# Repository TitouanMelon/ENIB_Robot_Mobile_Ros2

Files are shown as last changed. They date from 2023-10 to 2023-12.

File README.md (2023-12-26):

# Mobile robot with ROS2

Project to make a moving robot with communication with ROS2 and sensors
His little name is : Humble

## Project member
- Titouan Melon : https://www.linkedin.com/in/titouan-melon
- Louanne Floch : https://www.linkedin.com/in/louanne-floch
- Jérémy Plantec : https://www.linkedin.com/in/j%C3%A9r%C3%A9my-plantec-7a24a81bb
- Donald TOGNIA DJANKO DIALLO : https://www.linkedin.com/in/tognia-djanko-diallo-donald-b38281228

## Extern links
- Google drive :https://drive.google.com/drive/folders/1ekVw0Pp5evgDc79cSzruJdU0V-NTOiN-?usp=sharing
- Documentation of the mechanical part : https://www.enib.fr/~kerhoas/robot_ros_architecture.html
- Documentation of the STM32 workspace : https://nasmelon.ddns.net/robotRos/doc/index.html
- Visualization of the 3D model : https://nasmelon.ddns.net/robotRos/3d/index.html
- Virtual machine with all software and startup workspace :
 - rapid speed link : https://drive.google.com/file/d/1msf677nJeT9T99g9dxZXXRz8_1ijEkyR/view?usp=sharing
 - low speed link : https://nasmelon.ddns.net/robotRos/Ubuntu22.04.ova

## Schema
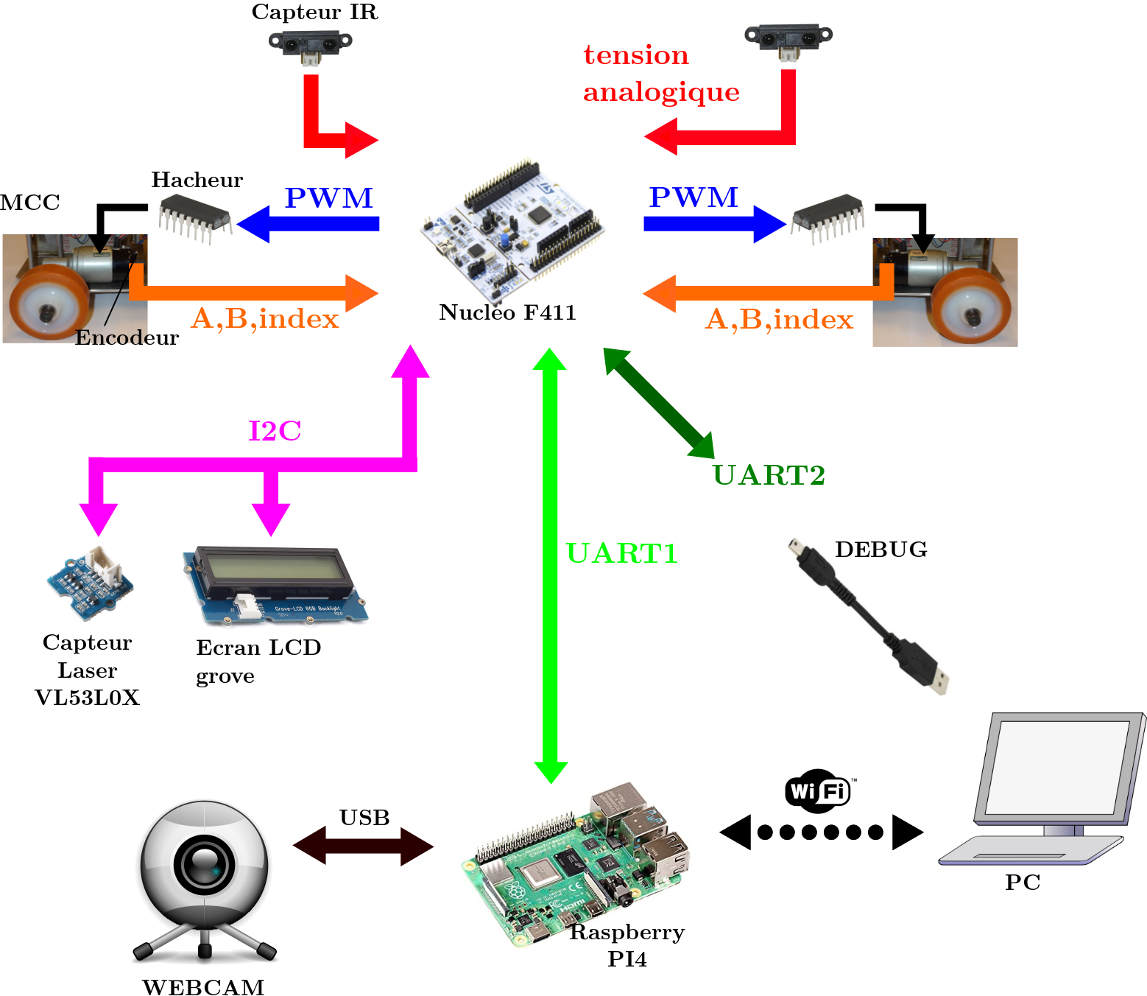
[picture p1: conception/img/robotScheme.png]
robot sheme


## Folder description

```
\---finalCode
|	\---Camera : camera's program 
|	\---IHM : qt ihm
|	\---WORKSPACE_F411_uROS6 : stm32 workspace
\---startupCode : contain the startup workspace
\---conception
|   \---3D_models
|   \---img : img to readme
|   \---installation scripts
|   \---schematique : eagle
\---docs
|   \---externe : extern pdf 
|   \---html : documentation in web format
|   \---latex : documentation in pdf format
\---report : report for ERI
```

## Summary
1. [Software installation](./README.md#Software-installation-procedure)
2. [Get startup workspace](./README.md#Get-startup-workspace)
3. [Get final workspace](./README.md#Get-final-workspace)
4. [Launch procedure](./README.md#Launch-procedure)
5. [Modify the code](./README.md#modify-code)
6. [Other information](./README.md#Other-information)

# Software installation procedure
## Install OS

### On a PC
Install <a href="https://ubuntu.com/download/desktop" >Ubuntu 22.04.3 LTS</a> on a pc
### On a RPI
Install <a href="https://www.raspberrypi.com/software/">RPI imager</a> and with this install Ubuntu like this

CHOOSE OS -> Other general-purpose OS -> Ubuntu -> Ubuntu Desktop 22.04.03 LTS (64bits)

## Install all in one script
>[!NOTE]
>this section is recommended for a pc but it is possible to apply it to the raspberry PI
>You need 8Go of free space

You can install all necessary tools with this following commands.

```
sudo apt install wget -y
wget https://raw.githubusercontent.com/TitouanMelon/ENIB_Robot_Mobile_Ros2/main/conception/installation%20scripts/ROS.sh
wget STM32cubeIDE.sh
sed -i 's/\r$//' ./ROS.sh && chmod +x ./ROS.sh && ./ROS.sh
```

## For PC and RaspberryPi
### Install ROS2
ROS2 installation is the same on PC and on RPI

```
sudo apt install wget -y
wget https://raw.githubusercontent.com/TitouanMelon/ENIB_Robot_Mobile_Ros2/main/conception/installation%20scripts/ROS_Install.sh
sed -i 's/\r$//' ./ROS_Install.sh && chmod +x ./ROS_Install.sh && ./ROS_Install.sh
```

### Install MicroRos

>[!WARNING]
>Be carreful the installation of microRos require a minimum of 1GB of RAM to succes

>[!NOTE]
>In order to install on a RPI4 with 2GB of RAM you can remove gdm3 install the script with the console and reinstall gdm3

```
sudo apt install wget -y
wget https://raw.githubusercontent.com/TitouanMelon/ENIB_Robot_Mobile_Ros2/main/conception/installation%20scripts/MicroROS_Install.sh
sed -i 's/\r$//' ./MicroROS_Install.sh && chmod +x ./MicroROS_Install.sh && ./MicroROS_Install.sh
```

### Copy scripts on pc
```
cd ~
sudo apt install wget -y
wget https://raw.githubusercontent.com/TitouanMelon/ENIB_Robot_Mobile_Ros2/main/conception/installation%20scripts/STM32.sh
wget https://raw.githubusercontent.com/TitouanMelon/ENIB_Robot_Mobile_Ros2/main/conception/installation%20scripts/SET_ROS_DOMAIN_ID.sh
sed -i 's/\r$//' ./STM32.sh && chmod +x ./STM32.sh
sed -i 's/\r$//' ./SET_ROS_DOMAIN_ID.sh && chmod +x ./SET_ROS_DOMAIN_ID.sh
echo "ROS_DOMAIN_ID=0" | sudo tee -a /etc/environment
sudo ln -s ./STM32.sh /usr/bin/stm32_ros_agent 
sudo ln -s ./SET_ROS_DOMAIN_ID.sh /usr/bin/set_ros_id
```

## For Pc only
>[!NOTE]
>this section is recommended for a pc but it is possible to apply it to the raspberry PI

### STM32CubeIde

Get <a href="https://www.st.com/en/development-tools/stm32cubeide.html">STM32CubeIde</a> and install it 

#### Install

Go to the **Get Software** level and select the latest version of your OS

Next accept the EULA and fil the form with the name of your choice but a valid email address on the next prompt

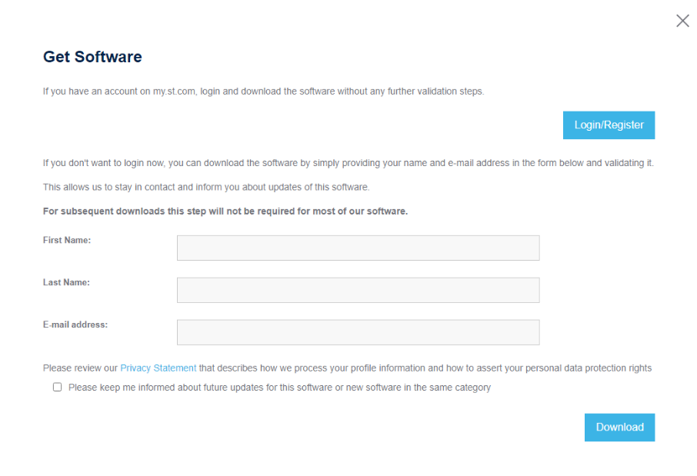
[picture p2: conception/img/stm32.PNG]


You will receive an email with the download link

After download just launch the executable and follow the instructions

#### Install gtkterm
```
sudo apt install gtkterm -y
```

### QT creator and QT creator ros
you need to install the qtcreator and qtcreator-ros software

```
sudo apt install qtcreator -y
sudo snap install qtcreator-ros --classic
```

# Get startup workspace
>[!NOTE]
>Be carreful if a directory have the same name the commands can erase the folder

Go to your project directory and run the command below
## Get the STM32 workspace
```
sudo apt install wget unzip -y
wget https://github.com/TitouanMelon/ENIB_Robot_Mobile_Ros2/raw/main/startupCode/WORKSPACE_F411_uROS.zip
unzip WORKSPACE_F411_uROS.zip
```

## Get the qt workspace
```
sudo apt install wget unzip -y
wget https://github.com/TitouanMelon/ENIB_Robot_Mobile_Ros2/raw/main/startupCode/IHM.zip
unzip IHM.zip
```

## Get the camera workspace
>[!NOTE]
>You need to have ROS2 install to follow this tutorial (see [here](./README.md#install-ros2) to install)

For the camera we can't give a startup folder because there are some configuration to do if they want modify the code like add more file
so is easier to follow this links to do the workspace by yourself:

- Tutorial ROS2 humble : https://docs.ros.org/en/humble/Tutorials/Beginner-Client-Libraries/Writing-A-Simple-Py-Publisher-And-Subscriber.html
- Github of the tutorial exemples : https://github.com/ros2/examples/tree/rolling/rclpy

# Get final workspace
```
sudo apt install git -y
git clone https://github.com/TitouanMelon/ENIB_Robot_Mobile_Ros2.git
mkdir -p ~/robot
mv -r ./ENIB_Robot_Mobile_Ros2/finalCode/* ~/robot/
#uncomment to remove git directory
#rm -r ./ENIB_Robot_Mobile_Ros2

```

# Launch procedure
>[!NOTE]
>The command below is make for our final solution so you maybe need to adjust some command to execute your solution

1. Build and run IHM
Open a terminal in the IHM directory and run this command

```
colcon build
source install/setup.bash
./build/robot_mobile_pkg_cpp/my_node_ihm
# if you change the name of project change this line like this ./build/<node_name>/<executable_name>
```

2. Compile, build and run the camera program
```
colcon build --packages-select py_pubsub
source install/setup.bash
ros2 run py_pubsub camera
# if you change the name of project change the line like this ros2 run <package_name> <entry_point>
```

3. Start the STM32.sh or stm32_ros_agent
```
stm32_ros_agent
# or launch STM32.sh from the terminal
```
4. Flash the stm32 and run the code
>[!NOTE]
>If you have the multiple pattern error clean and rebuild the project until the error dissipear

# modify code
## Open stm32 project
>[!NOTE]
>you need STM32CubeIde to follow this tutorial (see [here](./README.md#STM32CubeIde) to install)

- Open stm32cubeIde and select the workspace and select ok

## Open IHM
>[!NOTE]
>you need qtcreator and qtcreator-ros to follow this tutorial (see [here](./README.md#qt-creator-and-qt-creator-ros) to install)

- Open qtcreator-ros
- go to File -> Open project or file

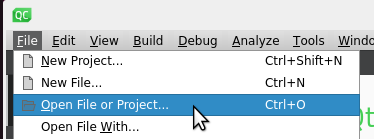
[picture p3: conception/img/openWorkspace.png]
openproject

- Open the file 'workspace.user'
- Then close and repeat to make qtcreator-ros load the project files

## Open camera code
1. Code directly on the RPI
2. Use Visual Studio to connect to in ssh to your raspberryPi and have access to his folder 

# Other information
## Documentation of the stm32 final workspace
You can found the documentation of the STM32 project [here](./docs)

## Config camera
```
sudo apt install v412-ctl
v4l2-ctl -d /dev/video0 --all
```

## Get information about ROS2 node and topic 
- You can use rqt to see information about ROS2. It's a visual ihm to see topics and data
- Information about all topic
```
ros2 topic list
```

- Information about a node
```
ros2 node info /nom/du/node
```

## Send and receive data on ros topic
You can see message_type and data on this link : https://docs.ros.org/en/melodic/api/std_msgs/html/index-msg.html

- Publish data once on a topic
```
ros2 topic --once <topic/name> <message_type> <data>
```
- Publish N data per seconds on a topic 
```
ros2 topic -r N <topic/name> <message_type> <data>
```
- exemple of publishing an array of 3 Int8 on the topic camera/hsv_low once ([data format](https://docs.ros.org/en/melodic/api/std_msgs/html/msg/Int8MultiArray.html))
```
ros2 topic pub --once camera/hsv_low std_msgs/msg/Int8MultiArray "{data : [99,91,30]}"
```

- Listen a topic
```
ros2 topic echo <topic/name>
```

## Redirect printf on UART2

Right-click on the syscalls.c file and select Properties. Under C/C++ Build>Settings, check Exclude ressource from build

Then click on Apply and close
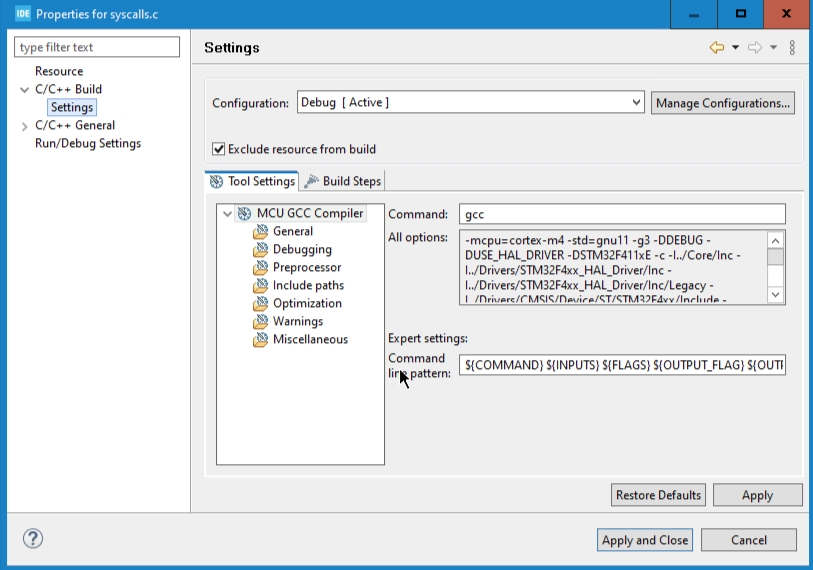
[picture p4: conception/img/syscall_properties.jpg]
syscall.c properties


Next create two files :
- retarget.h copy/paste code from [retarget.h](./conception/retarget/retarget.h) and save
- retarget.c and copy/paste code from [retarget.c](./conception/retarget/retarget.c) and save

After you need to include stdio.h and retarget.h in your main file and call 
```
RetargetInit(&huart2);
```

to indicate you want printf and scanf function on UART2

## 3D models
see 3D models information [here](./conception/3D_models/)

## Pinout

more information [here](./docs/externe/base_robot.pdf)

| Pin STM32 | Function | Use |
|--- | --- | --- |
|PA8 | PWM1/1 | Encodeur Voie A |
|PA9 | PWM1/2 | Encodeur Voie B |
|PB10 | EXTI1 | Index encodeur  |
|PA0 | PWM2/1 | Encodeur Voie A |
|PA1 | PWM2/2 | Encodeur Voie B |
|PC0 | EXTI | Index Moteur |
|PA6 | PWM3/1 | PWM motor 1 |
|PC7 | PWM3/2 | PWM motor 2 |
|PB3 | ENABLE MOTEUR | actif état Bas  |
|PA4 | ADC1_8 | Sensor IR 1 |
|PB0 | ADC1_4 | Sensor IR 2 |

## Robot cablage
### USART2
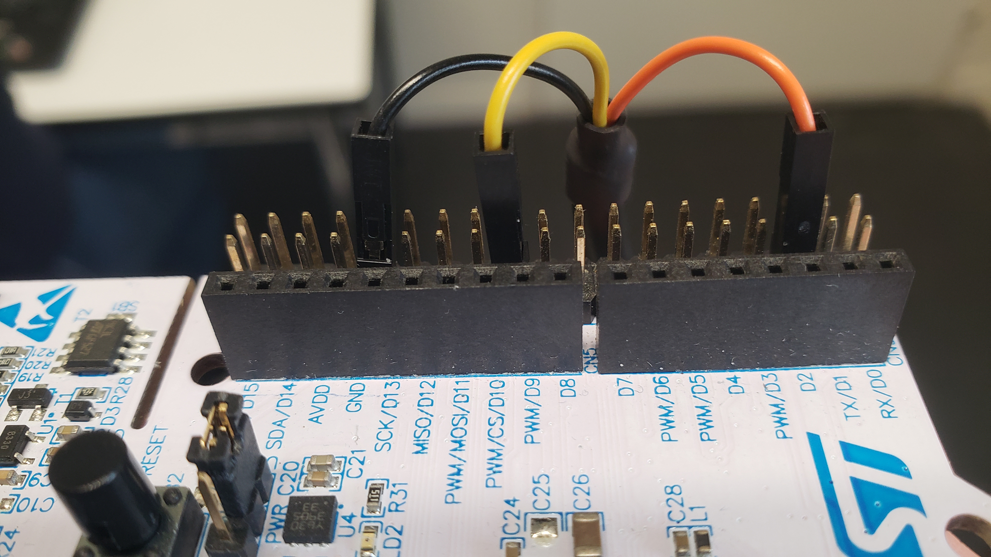
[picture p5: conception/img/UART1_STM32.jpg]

###Motor, Sensors and rpi
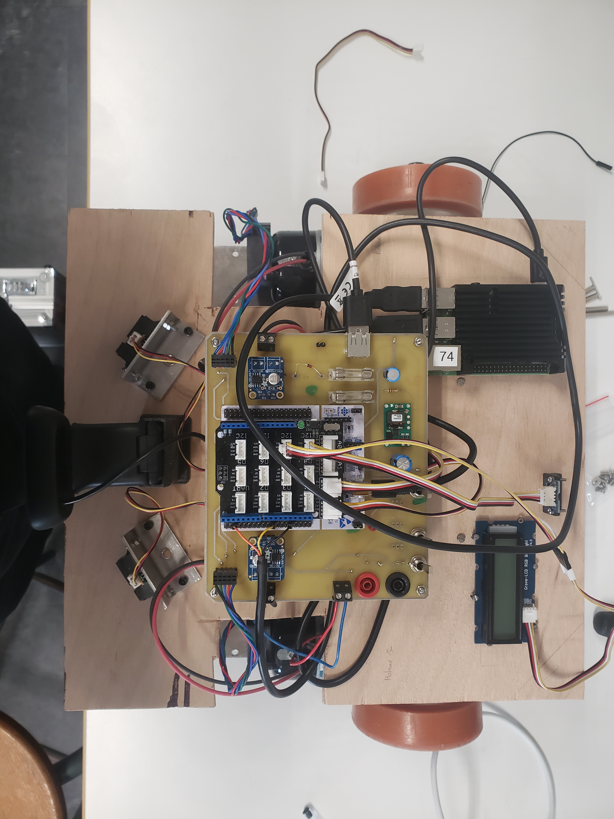
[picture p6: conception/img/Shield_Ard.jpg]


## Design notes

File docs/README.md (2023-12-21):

# Get the web documentation
1. Download the html zip, extract them and launch index.html
2. Go to https://nasmelon.ddns.net/robotRos/doc/index.html

# Get the pdf documentation
1. Download the stm32_doc.pdf

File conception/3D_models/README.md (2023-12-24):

# 3D model for construct the robot
- Catia file
 - [PlaqueHaut](./piece/plaque/RobotROSPlaque.CATPart)
 - [SupportCapteurArriere](./piece/support/SupportVL530X.CATPart)
 - [SupportCamera](./piece/support/support_webcam.CATPart)
 - [SupportCapteurAvant](./piece/support/SupportVL53L0X.CATPart)

- Drawing
 - [PlaqueHaut](./other/drawing/PlaqueRobotRos.pdf)
 - [SupportCapteurArriere](./other/drawing/SupportCapteurArriere.pdf)
 - [SupportCapteurAvant](./other/drawing/SupportCapteurAvant.pdf)

- Stl
 - [SupportCapteurArriere](./other/3dprint/SupportVL530X.stl)
 - [SupportCamera](./other/3dprint/support_webcam.stl)

- Gcode for prusa mk3/mk4
 - [SupportCapteurArriere](./other/3dprint/SupportVL530X.gcode)
 - [SupportCamera](./other/3dprint/support_webcam.gcode)

# 3D model in one file

- .obj and .stp of the assembly of the robot can be found in HumbleObj_Stp.rar
- Vizualize 3D model : https://nasmelon.ddns.net/robotRos/3d/index.html

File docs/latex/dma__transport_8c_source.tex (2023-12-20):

\doxysection{dma\+\_\+transport.\+c}
\hypertarget{dma__transport_8c_source}{}\label{dma__transport_8c_source}\index{C:/Users/Administrator/Documents/GitHub/ENIB\_Robot\_Mobile\_Ros2/finalCode/WORKSPACE\_F411\_uROS/base\_robot/Core/Src/dma\_transport.c@{C:/Users/Administrator/Documents/GitHub/ENIB\_Robot\_Mobile\_Ros2/finalCode/WORKSPACE\_F411\_uROS/base\_robot/Core/Src/dma\_transport.c}}

\begin{DoxyCode}{0}
\DoxyCodeLine{\Hypertarget{dma__transport_8c_source_l00001}00001\ \textcolor{preprocessor}{\#include\ <uxr/client/transport.h>}}
\DoxyCodeLine{\Hypertarget{dma__transport_8c_source_l00002}00002\ }
\DoxyCodeLine{\Hypertarget{dma__transport_8c_source_l00003}00003\ \textcolor{preprocessor}{\#include\ <rmw\_microxrcedds\_c/config.h>}}
\DoxyCodeLine{\Hypertarget{dma__transport_8c_source_l00004}00004\ }
\DoxyCodeLine{\Hypertarget{dma__transport_8c_source_l00005}00005\ \textcolor{preprocessor}{\#include\ "{}\mbox{\hyperlink{main_8h}{main.h}}"{}}}
\DoxyCodeLine{\Hypertarget{dma__transport_8c_source_l00006}00006\ \textcolor{preprocessor}{\#include\ "{}cmsis\_os.h"{}}}
\DoxyCodeLine{\Hypertarget{dma__transport_8c_source_l00007}00007\ }
\DoxyCodeLine{\Hypertarget{dma__transport_8c_source_l00008}00008\ \textcolor{preprocessor}{\#include\ <unistd.h>}}
\DoxyCodeLine{\Hypertarget{dma__transport_8c_source_l00009}00009\ \textcolor{preprocessor}{\#include\ <stdio.h>}}
\DoxyCodeLine{\Hypertarget{dma__transport_8c_source_l00010}00010\ \textcolor{preprocessor}{\#include\ <string.h>}}
\DoxyCodeLine{\Hypertarget{dma__transport_8c_source_l00011}00011\ \textcolor{preprocessor}{\#include\ <stdbool.h>}}
\DoxyCodeLine{\Hypertarget{dma__transport_8c_source_l00012}00012\ }
\DoxyCodeLine{\Hypertarget{dma__transport_8c_source_l00013}00013\ \textcolor{preprocessor}{\#ifdef\ RMW\_UXRCE\_TRANSPORT\_CUSTOM}}
\DoxyCodeLine{\Hypertarget{dma__transport_8c_source_l00014}00014\ }
\DoxyCodeLine{\Hypertarget{dma__transport_8c_source_l00015}00015\ \textcolor{comment}{//\ -\/-\/-\/\ micro-\/ROS\ Transports\ -\/-\/-\/}}
\DoxyCodeLine{\Hypertarget{dma__transport_8c_source_l00016}00016\ \textcolor{preprocessor}{\#define\ UART\_DMA\_BUFFER\_SIZE\ 2048}}
\DoxyCodeLine{\Hypertarget{dma__transport_8c_source_l00017}00017\ }
\DoxyCodeLine{\Hypertarget{dma__transport_8c_source_l00018}00018\ \textcolor{keyword}{static}\ uint8\_t\ dma\_buffer[UART\_DMA\_BUFFER\_SIZE];}
\DoxyCodeLine{\Hypertarget{dma__transport_8c_source_l00019}00019\ \textcolor{keyword}{static}\ \textcolor{keywordtype}{size\_t}\ dma\_head\ =\ 0,\ dma\_tail\ =\ 0;}
\DoxyCodeLine{\Hypertarget{dma__transport_8c_source_l00020}00020\ }
\DoxyCodeLine{\Hypertarget{dma__transport_8c_source_l00021}00021\ \textcolor{keywordtype}{bool}\ cubemx\_transport\_open(\textcolor{keyword}{struct}\ uxrCustomTransport\ *\ transport)\{}
\DoxyCodeLine{\Hypertarget{dma__transport_8c_source_l00022}00022\ \ \ \ \ UART\_HandleTypeDef\ *\ uart\ =\ (UART\_HandleTypeDef*)\ transport-\/>args;}
\DoxyCodeLine{\Hypertarget{dma__transport_8c_source_l00023}00023\ \ \ \ \ HAL\_UART\_Receive\_DMA(uart,\ dma\_buffer,\ UART\_DMA\_BUFFER\_SIZE);}
\DoxyCodeLine{\Hypertarget{dma__transport_8c_source_l00024}00024\ \ \ \ \ \textcolor{keywordflow}{return}\ \textcolor{keyword}{true};}
\DoxyCodeLine{\Hypertarget{dma__transport_8c_source_l00025}00025\ \}}
\DoxyCodeLine{\Hypertarget{dma__transport_8c_source_l00026}00026\ }
\DoxyCodeLine{\Hypertarget{dma__transport_8c_source_l00027}00027\ \textcolor{keywordtype}{bool}\ cubemx\_transport\_close(\textcolor{keyword}{struct}\ uxrCustomTransport\ *\ transport)\{}
\DoxyCodeLine{\Hypertarget{dma__transport_8c_source_l00028}00028\ \ \ \ \ UART\_HandleTypeDef\ *\ uart\ =\ (UART\_HandleTypeDef*)\ transport-\/>args;}
\DoxyCodeLine{\Hypertarget{dma__transport_8c_source_l00029}00029\ \ \ \ \ HAL\_UART\_DMAStop(uart);}
\DoxyCodeLine{\Hypertarget{dma__transport_8c_source_l00030}00030\ \ \ \ \ \textcolor{keywordflow}{return}\ \textcolor{keyword}{true};}
\DoxyCodeLine{\Hypertarget{dma__transport_8c_source_l00031}00031\ \}}
\DoxyCodeLine{\Hypertarget{dma__transport_8c_source_l00032}00032\ }
\DoxyCodeLine{\Hypertarget{dma__transport_8c_source_l00033}00033\ \textcolor{keywordtype}{size\_t}\ cubemx\_transport\_write(\textcolor{keyword}{struct}\ uxrCustomTransport*\ transport,\ uint8\_t\ *\ buf,\ \textcolor{keywordtype}{size\_t}\ len,\ uint8\_t\ *\ err)\{}
\DoxyCodeLine{\Hypertarget{dma__transport_8c_source_l00034}00034\ \ \ \ \ UART\_HandleTypeDef\ *\ uart\ =\ (UART\_HandleTypeDef*)\ transport-\/>args;}
\DoxyCodeLine{\Hypertarget{dma__transport_8c_source_l00035}00035\ }
\DoxyCodeLine{\Hypertarget{dma__transport_8c_source_l00036}00036\ \ \ \ \ HAL\_StatusTypeDef\ ret;}
\DoxyCodeLine{\Hypertarget{dma__transport_8c_source_l00037}00037\ \ \ \ \ \textcolor{keywordflow}{if}\ (uart-\/>gState\ ==\ HAL\_UART\_STATE\_READY)\{}
\DoxyCodeLine{\Hypertarget{dma__transport_8c_source_l00038}00038\ \ \ \ \ \ \ \ \ ret\ =\ HAL\_UART\_Transmit\_DMA(uart,\ buf,\ len);}
\DoxyCodeLine{\Hypertarget{dma__transport_8c_source_l00039}00039\ \ \ \ \ \ \ \ \ \textcolor{keywordflow}{while}\ (ret\ ==\ HAL\_OK\ \&\&\ uart-\/>gState\ !=\ HAL\_UART\_STATE\_READY)\{}
\DoxyCodeLine{\Hypertarget{dma__transport_8c_source_l00040}00040\ \ \ \ \ \ \ \ \ \ \ \ \ osDelay(1);}
\DoxyCodeLine{\Hypertarget{dma__transport_8c_source_l00041}00041\ \ \ \ \ \ \ \ \ \}}
\DoxyCodeLine{\Hypertarget{dma__transport_8c_source_l00042}00042\ }
\DoxyCodeLine{\Hypertarget{dma__transport_8c_source_l00043}00043\ \ \ \ \ \ \ \ \ \textcolor{keywordflow}{return}\ (ret\ ==\ HAL\_OK)\ ?\ len\ :\ 0;}
\DoxyCodeLine{\Hypertarget{dma__transport_8c_source_l00044}00044\ \ \ \ \ \}\textcolor{keywordflow}{else}\{}
\DoxyCodeLine{\Hypertarget{dma__transport_8c_source_l00045}00045\ \ \ \ \ \ \ \ \ \textcolor{keywordflow}{return}\ 0;}
\DoxyCodeLine{\Hypertarget{dma__transport_8c_source_l00046}00046\ \ \ \ \ \}}
\DoxyCodeLine{\Hypertarget{dma__transport_8c_source_l00047}00047\ \}}
\DoxyCodeLine{\Hypertarget{dma__transport_8c_source_l00048}00048\ }
\DoxyCodeLine{\Hypertarget{dma__transport_8c_source_l00049}00049\ \textcolor{keywordtype}{size\_t}\ cubemx\_transport\_read(\textcolor{keyword}{struct}\ uxrCustomTransport*\ transport,\ uint8\_t*\ buf,\ \textcolor{keywordtype}{size\_t}\ len,\ \textcolor{keywordtype}{int}\ timeout,\ uint8\_t*\ err)\{}
\DoxyCodeLine{\Hypertarget{dma__transport_8c_source_l00050}00050\ \ \ \ \ UART\_HandleTypeDef\ *\ uart\ =\ (UART\_HandleTypeDef*)\ transport-\/>args;}
\DoxyCodeLine{\Hypertarget{dma__transport_8c_source_l00051}00051\ }
\DoxyCodeLine{\Hypertarget{dma__transport_8c_source_l00052}00052\ \ \ \ \ \textcolor{keywordtype}{int}\ ms\_used\ =\ 0;}
\DoxyCodeLine{\Hypertarget{dma__transport_8c_source_l00053}00053\ \ \ \ \ \textcolor{keywordflow}{do}}
\DoxyCodeLine{\Hypertarget{dma__transport_8c_source_l00054}00054\ \ \ \ \ \{}
\DoxyCodeLine{\Hypertarget{dma__transport_8c_source_l00055}00055\ \ \ \ \ \ \ \ \ \_\_disable\_irq();}
\DoxyCodeLine{\Hypertarget{dma__transport_8c_source_l00056}00056\ \ \ \ \ \ \ \ \ dma\_tail\ =\ UART\_DMA\_BUFFER\_SIZE\ -\/\ \_\_HAL\_DMA\_GET\_COUNTER(uart-\/>hdmarx);}
\DoxyCodeLine{\Hypertarget{dma__transport_8c_source_l00057}00057\ \ \ \ \ \ \ \ \ \_\_enable\_irq();}
\DoxyCodeLine{\Hypertarget{dma__transport_8c_source_l00058}00058\ \ \ \ \ \ \ \ \ ms\_used++;}
\DoxyCodeLine{\Hypertarget{dma__transport_8c_source_l00059}00059\ \ \ \ \ \ \ \ \ osDelay(portTICK\_RATE\_MS);}
\DoxyCodeLine{\Hypertarget{dma__transport_8c_source_l00060}00060\ \ \ \ \ \}\ \textcolor{keywordflow}{while}\ (dma\_head\ ==\ dma\_tail\ \&\&\ ms\_used\ <\ timeout);}
\DoxyCodeLine{\Hypertarget{dma__transport_8c_source_l00061}00061\ \ \ \ \ }
\DoxyCodeLine{\Hypertarget{dma__transport_8c_source_l00062}00062\ \ \ \ \ \textcolor{keywordtype}{size\_t}\ wrote\ =\ 0;}
\DoxyCodeLine{\Hypertarget{dma__transport_8c_source_l00063}00063\ \ \ \ \ \textcolor{keywordflow}{while}\ ((dma\_head\ !=\ dma\_tail)\ \&\&\ (wrote\ <\ len))\{}
\DoxyCodeLine{\Hypertarget{dma__transport_8c_source_l00064}00064\ \ \ \ \ \ \ \ \ buf[wrote]\ =\ dma\_buffer[dma\_head];}
\DoxyCodeLine{\Hypertarget{dma__transport_8c_source_l00065}00065\ \ \ \ \ \ \ \ \ dma\_head\ =\ (dma\_head\ +\ 1)\ \%\ UART\_DMA\_BUFFER\_SIZE;}
\DoxyCodeLine{\Hypertarget{dma__transport_8c_source_l00066}00066\ \ \ \ \ \ \ \ \ wrote++;}
\DoxyCodeLine{\Hypertarget{dma__transport_8c_source_l00067}00067\ \ \ \ \ \}}
\DoxyCodeLine{\Hypertarget{dma__transport_8c_source_l00068}00068\ \ \ \ \ }
\DoxyCodeLine{\Hypertarget{dma__transport_8c_source_l00069}00069\ \ \ \ \ \textcolor{keywordflow}{return}\ wrote;}
\DoxyCodeLine{\Hypertarget{dma__transport_8c_source_l00070}00070\ \}}
\DoxyCodeLine{\Hypertarget{dma__transport_8c_source_l00071}00071\ }
\DoxyCodeLine{\Hypertarget{dma__transport_8c_source_l00072}00072\ \textcolor{preprocessor}{\#endif\ }\textcolor{comment}{//RMW\_UXRCE\_TRANSPORT\_CUSTOM}}

\end{DoxyCode}

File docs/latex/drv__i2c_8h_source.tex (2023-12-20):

\doxysection{drv\+\_\+i2c.\+h}
\hypertarget{drv__i2c_8h_source}{}\label{drv__i2c_8h_source}\index{C:/Users/Administrator/Documents/GitHub/ENIB\_Robot\_Mobile\_Ros2/finalCode/WORKSPACE\_F411\_uROS/base\_robot/Core/Inc/drv\_i2c.h@{C:/Users/Administrator/Documents/GitHub/ENIB\_Robot\_Mobile\_Ros2/finalCode/WORKSPACE\_F411\_uROS/base\_robot/Core/Inc/drv\_i2c.h}}

\begin{DoxyCode}{0}
\DoxyCodeLine{\Hypertarget{drv__i2c_8h_source_l00001}00001\ \textcolor{comment}{/*}}
\DoxyCodeLine{\Hypertarget{drv__i2c_8h_source_l00002}00002\ \textcolor{comment}{\ *\ drv\_i2c.h}}
\DoxyCodeLine{\Hypertarget{drv__i2c_8h_source_l00003}00003\ \textcolor{comment}{\ *}}
\DoxyCodeLine{\Hypertarget{drv__i2c_8h_source_l00004}00004\ \textcolor{comment}{\ *\ \ Created\ on:\ Mar\ 13,\ 2023}}
\DoxyCodeLine{\Hypertarget{drv__i2c_8h_source_l00005}00005\ \textcolor{comment}{\ *\ \ \ \ \ \ Author:\ kerhoas}}
\DoxyCodeLine{\Hypertarget{drv__i2c_8h_source_l00006}00006\ \textcolor{comment}{\ */}}
\DoxyCodeLine{\Hypertarget{drv__i2c_8h_source_l00007}00007\ }
\DoxyCodeLine{\Hypertarget{drv__i2c_8h_source_l00008}00008\ \textcolor{preprocessor}{\#ifndef\ INC\_DRV\_I2C\_H\_}}
\DoxyCodeLine{\Hypertarget{drv__i2c_8h_source_l00009}00009\ \textcolor{preprocessor}{\#define\ INC\_DRV\_I2C\_H\_}}
\DoxyCodeLine{\Hypertarget{drv__i2c_8h_source_l00010}00010\ }
\DoxyCodeLine{\Hypertarget{drv__i2c_8h_source_l00011}00011\ \textcolor{keywordtype}{void}\ MX\_I2C1\_Init(\textcolor{keywordtype}{void});}
\DoxyCodeLine{\Hypertarget{drv__i2c_8h_source_l00012}00012\ }
\DoxyCodeLine{\Hypertarget{drv__i2c_8h_source_l00013}00013\ \textcolor{comment}{//\ Transmit\ n\_data\ bytes\ to\ i2c\ slave}}
\DoxyCodeLine{\Hypertarget{drv__i2c_8h_source_l00014}00014\ \textcolor{keywordtype}{int}\ i2c1\_WriteBuffer(uint16\_t\ addrSlave,\ uint8\_t\ *data,\ \textcolor{keywordtype}{int}\ n\_data);}
\DoxyCodeLine{\Hypertarget{drv__i2c_8h_source_l00015}00015\ }
\DoxyCodeLine{\Hypertarget{drv__i2c_8h_source_l00016}00016\ \textcolor{comment}{//\ Receive\ n\_data\ bytes\ from\ i2c\ slave}}
\DoxyCodeLine{\Hypertarget{drv__i2c_8h_source_l00017}00017\ \textcolor{keywordtype}{int}\ i2c1\_ReadBuffer(uint16\_t\ addrSlave,\ uint8\_t\ *data,\ \textcolor{keywordtype}{int}\ n\_data);}
\DoxyCodeLine{\Hypertarget{drv__i2c_8h_source_l00018}00018\ }
\DoxyCodeLine{\Hypertarget{drv__i2c_8h_source_l00019}00019\ \textcolor{comment}{//\ Receive\ n\_data\ bytes\ -\/\ located\ at\ regAddr\ -\/\ from\ i2c\ slave}}
\DoxyCodeLine{\Hypertarget{drv__i2c_8h_source_l00020}00020\ \textcolor{keywordtype}{int}\ i2c1\_ReadRegBuffer(uint16\_t\ addrSlave,\ uint8\_t\ \ regAddr,\ \ uint8\_t\ *data,\ \textcolor{keywordtype}{int}\ n\_data);}
\DoxyCodeLine{\Hypertarget{drv__i2c_8h_source_l00021}00021\ }
\DoxyCodeLine{\Hypertarget{drv__i2c_8h_source_l00022}00022\ \textcolor{comment}{//\ Write\ n\_data\ bytes\ -\/\ have\ to\ be\ written\ at\ regAddr\ -\/\ to\ i2c\ slave}}
\DoxyCodeLine{\Hypertarget{drv__i2c_8h_source_l00023}00023\ \textcolor{keywordtype}{int}\ i2c1\_WriteRegBuffer(uint16\_t\ addrSlave,\ uint8\_t\ \ regAddr,\ \ uint8\_t\ *data,\ \textcolor{keywordtype}{int}\ n\_data);}
\DoxyCodeLine{\Hypertarget{drv__i2c_8h_source_l00024}00024\ }
\DoxyCodeLine{\Hypertarget{drv__i2c_8h_source_l00025}00025\ \textcolor{comment}{//\ Write\ 1\ byte\ at\ regAddr\ Slave\ -\/\ Interrupt\ Method}}
\DoxyCodeLine{\Hypertarget{drv__i2c_8h_source_l00026}00026\ \textcolor{keywordtype}{void}\ i2c1\_WriteRegByte\_IT(uint16\_t\ addrSlave,\ uint8\_t\ \ regAddr,\ \ uint8\_t\ data);}
\DoxyCodeLine{\Hypertarget{drv__i2c_8h_source_l00027}00027\ }
\DoxyCodeLine{\Hypertarget{drv__i2c_8h_source_l00028}00028\ \textcolor{comment}{//\ Read\ 1\ byte\ from\ regAddr\ Slave\ -\/\ Interrupt\ Method}}
\DoxyCodeLine{\Hypertarget{drv__i2c_8h_source_l00029}00029\ \textcolor{keywordtype}{void}\ i2c1\_ReadRegBuffer\_IT(uint16\_t\ addrSlave,\ uint8\_t\ \ regAddr,\ \ uint8\_t*\ datas,\ \textcolor{keywordtype}{int}\ len);}
\DoxyCodeLine{\Hypertarget{drv__i2c_8h_source_l00030}00030\ }
\DoxyCodeLine{\Hypertarget{drv__i2c_8h_source_l00031}00031\ \textcolor{comment}{//\ Write\ 1\ byte\ to\ regAddr\ (16\ bits)\ Slave}}
\DoxyCodeLine{\Hypertarget{drv__i2c_8h_source_l00032}00032\ \textcolor{keywordtype}{int}\ i2c1\_WriteReg16Byte(uint16\_t\ addrSlave,\ uint16\_t\ \ regAddr,\ \ uint8\_t\ data);}
\DoxyCodeLine{\Hypertarget{drv__i2c_8h_source_l00033}00033\ }
\DoxyCodeLine{\Hypertarget{drv__i2c_8h_source_l00034}00034\ \textcolor{comment}{//\ Write\ 16\ bits\ word\ to\ regAddr\ (16\ bits)\ Slave}}
\DoxyCodeLine{\Hypertarget{drv__i2c_8h_source_l00035}00035\ \textcolor{keywordtype}{int}\ i2c1\_WriteReg16Word16(uint16\_t\ addrSlave,\ uint16\_t\ \ regAddr,\ \ uint16\_t\ data);}
\DoxyCodeLine{\Hypertarget{drv__i2c_8h_source_l00036}00036\ }
\DoxyCodeLine{\Hypertarget{drv__i2c_8h_source_l00037}00037\ \textcolor{comment}{//\ Write\ 32\ bits\ word\ to\ regAddr\ (16\ bits)\ Slave}}
\DoxyCodeLine{\Hypertarget{drv__i2c_8h_source_l00038}00038\ \textcolor{keywordtype}{int}\ i2c1\_WriteReg16Word32(uint16\_t\ addrSlave,\ uint16\_t\ \ regAddr,\ \ uint32\_t\ data);}
\DoxyCodeLine{\Hypertarget{drv__i2c_8h_source_l00039}00039\ }
\DoxyCodeLine{\Hypertarget{drv__i2c_8h_source_l00040}00040\ \textcolor{comment}{//\ Read\ 1\ byte\ from\ regAddr\ (16\ bits)\ Slave}}
\DoxyCodeLine{\Hypertarget{drv__i2c_8h_source_l00041}00041\ \textcolor{keywordtype}{int}\ i2c1\_ReadReg16Byte(uint16\_t\ addrSlave,\ uint16\_t\ \ regAddr,\ uint8\_t\ *data);}
\DoxyCodeLine{\Hypertarget{drv__i2c_8h_source_l00042}00042\ }
\DoxyCodeLine{\Hypertarget{drv__i2c_8h_source_l00043}00043\ \textcolor{comment}{//\ Read\ 16\ bits\ word\ from\ regAddr\ (16\ bits)\ Slave}}
\DoxyCodeLine{\Hypertarget{drv__i2c_8h_source_l00044}00044\ \textcolor{keywordtype}{int}\ i2c1\_ReadReg16Word16(uint16\_t\ addrSlave,\ uint16\_t\ \ regAddr,\ uint16\_t\ *data);}
\DoxyCodeLine{\Hypertarget{drv__i2c_8h_source_l00045}00045\ }
\DoxyCodeLine{\Hypertarget{drv__i2c_8h_source_l00046}00046\ \textcolor{comment}{//\ Read\ 32\ bits\ word\ from\ regAddr\ (16\ bits)\ Slave}}
\DoxyCodeLine{\Hypertarget{drv__i2c_8h_source_l00047}00047\ \textcolor{keywordtype}{int}\ i2c1\_ReadReg16Word32(uint16\_t\ addrSlave,\ uint16\_t\ \ regAddr,\ uint32\_t\ *data);}
\DoxyCodeLine{\Hypertarget{drv__i2c_8h_source_l00048}00048\ }
\DoxyCodeLine{\Hypertarget{drv__i2c_8h_source_l00049}00049\ \textcolor{comment}{//\ Read\ n\_data\ bytes\ from\ regAddr\ (16\ bits)\ Slave}}
\DoxyCodeLine{\Hypertarget{drv__i2c_8h_source_l00050}00050\ \textcolor{keywordtype}{int}\ i2c1\_ReadReg16Buffer(uint16\_t\ addrSlave,\ uint16\_t\ \ regAddr,\ \ uint8\_t\ *data,\ \textcolor{keywordtype}{int}\ n\_data);}
\DoxyCodeLine{\Hypertarget{drv__i2c_8h_source_l00051}00051\ }
\DoxyCodeLine{\Hypertarget{drv__i2c_8h_source_l00052}00052\ \textcolor{preprocessor}{\#endif\ }\textcolor{comment}{/*\ INC\_DRV\_I2C\_H\_\ */}\textcolor{preprocessor}{}}

\end{DoxyCode}

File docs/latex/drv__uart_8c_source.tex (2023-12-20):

\doxysection{drv\+\_\+uart.\+c}
\hypertarget{drv__uart_8c_source}{}\label{drv__uart_8c_source}\index{C:/Users/Administrator/Documents/GitHub/ENIB\_Robot\_Mobile\_Ros2/finalCode/WORKSPACE\_F411\_uROS/base\_robot/Core/Src/drv\_uart.c@{C:/Users/Administrator/Documents/GitHub/ENIB\_Robot\_Mobile\_Ros2/finalCode/WORKSPACE\_F411\_uROS/base\_robot/Core/Src/drv\_uart.c}}

\begin{DoxyCode}{0}
\DoxyCodeLine{\Hypertarget{drv__uart_8c_source_l00001}00001\ \textcolor{preprocessor}{\#include\ "{}\mbox{\hyperlink{main_8h}{main.h}}"{}}}
\DoxyCodeLine{\Hypertarget{drv__uart_8c_source_l00002}00002\ \textcolor{preprocessor}{\#include\ "{}drv\_uart.h"{}}}
\DoxyCodeLine{\Hypertarget{drv__uart_8c_source_l00003}00003\ }
\DoxyCodeLine{\Hypertarget{drv__uart_8c_source_l00004}00004\ UART\_HandleTypeDef\ huart1;}
\DoxyCodeLine{\Hypertarget{drv__uart_8c_source_l00005}00005\ UART\_HandleTypeDef\ huart2;}
\DoxyCodeLine{\Hypertarget{drv__uart_8c_source_l00006}00006\ DMA\_HandleTypeDef\ hdma\_usart1\_rx;}
\DoxyCodeLine{\Hypertarget{drv__uart_8c_source_l00007}00007\ DMA\_HandleTypeDef\ hdma\_usart1\_tx;}
\DoxyCodeLine{\Hypertarget{drv__uart_8c_source_l00008}00008\ DMA\_HandleTypeDef\ hdma\_usart2\_rx;}
\DoxyCodeLine{\Hypertarget{drv__uart_8c_source_l00009}00009\ DMA\_HandleTypeDef\ hdma\_usart2\_tx;}
\DoxyCodeLine{\Hypertarget{drv__uart_8c_source_l00010}00010\ }
\DoxyCodeLine{\Hypertarget{drv__uart_8c_source_l00011}00011\ }
\DoxyCodeLine{\Hypertarget{drv__uart_8c_source_l00012}00012\ \textcolor{keywordtype}{void}\ MX\_USART1\_UART\_Init(\textcolor{keywordtype}{void})}
\DoxyCodeLine{\Hypertarget{drv__uart_8c_source_l00013}00013\ \{}
\DoxyCodeLine{\Hypertarget{drv__uart_8c_source_l00014}00014\ \ \ huart1.Instance\ =\ USART1;}
\DoxyCodeLine{\Hypertarget{drv__uart_8c_source_l00015}00015\ \ \ huart1.Init.BaudRate\ =\ 115200;}
\DoxyCodeLine{\Hypertarget{drv__uart_8c_source_l00016}00016\ \ \ huart1.Init.WordLength\ =\ UART\_WORDLENGTH\_8B;}
\DoxyCodeLine{\Hypertarget{drv__uart_8c_source_l00017}00017\ \ \ huart1.Init.StopBits\ =\ UART\_STOPBITS\_1;}
\DoxyCodeLine{\Hypertarget{drv__uart_8c_source_l00018}00018\ \ \ huart1.Init.Parity\ =\ UART\_PARITY\_NONE;}
\DoxyCodeLine{\Hypertarget{drv__uart_8c_source_l00019}00019\ \ \ huart1.Init.Mode\ =\ UART\_MODE\_TX\_RX;}
\DoxyCodeLine{\Hypertarget{drv__uart_8c_source_l00020}00020\ \ \ huart1.Init.HwFlowCtl\ =\ UART\_HWCONTROL\_NONE;}
\DoxyCodeLine{\Hypertarget{drv__uart_8c_source_l00021}00021\ \ \ huart1.Init.OverSampling\ =\ UART\_OVERSAMPLING\_16;}
\DoxyCodeLine{\Hypertarget{drv__uart_8c_source_l00022}00022\ \ \ \textcolor{keywordflow}{if}\ (HAL\_UART\_Init(\&huart1)\ !=\ HAL\_OK)}
\DoxyCodeLine{\Hypertarget{drv__uart_8c_source_l00023}00023\ \ \ \{}
\DoxyCodeLine{\Hypertarget{drv__uart_8c_source_l00024}00024\ \ \ \ \ Error\_Handler();}
\DoxyCodeLine{\Hypertarget{drv__uart_8c_source_l00025}00025\ \ \ \}}
\DoxyCodeLine{\Hypertarget{drv__uart_8c_source_l00026}00026\ \}}
\DoxyCodeLine{\Hypertarget{drv__uart_8c_source_l00027}00027\ }
\DoxyCodeLine{\Hypertarget{drv__uart_8c_source_l00028}00028\ }
\DoxyCodeLine{\Hypertarget{drv__uart_8c_source_l00029}00029\ \textcolor{keywordtype}{void}\ MX\_USART2\_UART\_Init(\textcolor{keywordtype}{void})}
\DoxyCodeLine{\Hypertarget{drv__uart_8c_source_l00030}00030\ \{}
\DoxyCodeLine{\Hypertarget{drv__uart_8c_source_l00031}00031\ \ \ huart2.Instance\ =\ USART2;}
\DoxyCodeLine{\Hypertarget{drv__uart_8c_source_l00032}00032\ \ \ huart2.Init.BaudRate\ =\ 115200;}
\DoxyCodeLine{\Hypertarget{drv__uart_8c_source_l00033}00033\ \ \ huart2.Init.WordLength\ =\ UART\_WORDLENGTH\_8B;}
\DoxyCodeLine{\Hypertarget{drv__uart_8c_source_l00034}00034\ \ \ huart2.Init.StopBits\ =\ UART\_STOPBITS\_1;}
\DoxyCodeLine{\Hypertarget{drv__uart_8c_source_l00035}00035\ \ \ huart2.Init.Parity\ =\ UART\_PARITY\_NONE;}
\DoxyCodeLine{\Hypertarget{drv__uart_8c_source_l00036}00036\ \ \ huart2.Init.Mode\ =\ UART\_MODE\_TX\_RX;}
\DoxyCodeLine{\Hypertarget{drv__uart_8c_source_l00037}00037\ \ \ huart2.Init.HwFlowCtl\ =\ UART\_HWCONTROL\_NONE;}
\DoxyCodeLine{\Hypertarget{drv__uart_8c_source_l00038}00038\ \ \ huart2.Init.OverSampling\ =\ UART\_OVERSAMPLING\_16;}
\DoxyCodeLine{\Hypertarget{drv__uart_8c_source_l00039}00039\ \ \ \textcolor{keywordflow}{if}\ (HAL\_UART\_Init(\&huart2)\ !=\ HAL\_OK)}
\DoxyCodeLine{\Hypertarget{drv__uart_8c_source_l00040}00040\ \ \ \{}
\DoxyCodeLine{\Hypertarget{drv__uart_8c_source_l00041}00041\ \ \ \ \ Error\_Handler();}
\DoxyCodeLine{\Hypertarget{drv__uart_8c_source_l00042}00042\ \ \ \}}
\DoxyCodeLine{\Hypertarget{drv__uart_8c_source_l00043}00043\ \}}
\DoxyCodeLine{\Hypertarget{drv__uart_8c_source_l00044}00044\ }
\DoxyCodeLine{\Hypertarget{drv__uart_8c_source_l00048}00048\ \textcolor{keywordtype}{void}\ MX\_DMA\_Init(\textcolor{keywordtype}{void})}
\DoxyCodeLine{\Hypertarget{drv__uart_8c_source_l00049}00049\ \{}
\DoxyCodeLine{\Hypertarget{drv__uart_8c_source_l00050}00050\ }
\DoxyCodeLine{\Hypertarget{drv__uart_8c_source_l00051}00051\ \ \ \textcolor{comment}{/*\ DMA\ controller\ clock\ enable\ */}}
\DoxyCodeLine{\Hypertarget{drv__uart_8c_source_l00052}00052\ \ \ \_\_HAL\_RCC\_DMA2\_CLK\_ENABLE();}
\DoxyCodeLine{\Hypertarget{drv__uart_8c_source_l00053}00053\ \ \ \_\_HAL\_RCC\_DMA1\_CLK\_ENABLE();}
\DoxyCodeLine{\Hypertarget{drv__uart_8c_source_l00054}00054\ }
\DoxyCodeLine{\Hypertarget{drv__uart_8c_source_l00055}00055\ \ \ \textcolor{comment}{/*\ DMA\ interrupt\ init\ */}}
\DoxyCodeLine{\Hypertarget{drv__uart_8c_source_l00056}00056\ \ \ \textcolor{comment}{/*\ DMA1\_Stream5\_IRQn\ interrupt\ configuration\ */}}
\DoxyCodeLine{\Hypertarget{drv__uart_8c_source_l00057}00057\ \ \ HAL\_NVIC\_SetPriority(DMA1\_Stream5\_IRQn,\ 5,\ 0);}
\DoxyCodeLine{\Hypertarget{drv__uart_8c_source_l00058}00058\ \ \ HAL\_NVIC\_EnableIRQ(DMA1\_Stream5\_IRQn);}
\DoxyCodeLine{\Hypertarget{drv__uart_8c_source_l00059}00059\ \ \ \textcolor{comment}{/*\ DMA1\_Stream6\_IRQn\ interrupt\ configuration\ */}}
\DoxyCodeLine{\Hypertarget{drv__uart_8c_source_l00060}00060\ \ \ HAL\_NVIC\_SetPriority(DMA1\_Stream6\_IRQn,\ 5,\ 0);}
\DoxyCodeLine{\Hypertarget{drv__uart_8c_source_l00061}00061\ \ \ HAL\_NVIC\_EnableIRQ(DMA1\_Stream6\_IRQn);}
\DoxyCodeLine{\Hypertarget{drv__uart_8c_source_l00062}00062\ \ \ \textcolor{comment}{/*\ DMA2\_Stream2\_IRQn\ interrupt\ configuration\ */}}
\DoxyCodeLine{\Hypertarget{drv__uart_8c_source_l00063}00063\ \ \ HAL\_NVIC\_SetPriority(DMA2\_Stream2\_IRQn,\ 5,\ 0);}
\DoxyCodeLine{\Hypertarget{drv__uart_8c_source_l00064}00064\ \ \ HAL\_NVIC\_EnableIRQ(DMA2\_Stream2\_IRQn);}
\DoxyCodeLine{\Hypertarget{drv__uart_8c_source_l00065}00065\ \ \ \textcolor{comment}{/*\ DMA2\_Stream7\_IRQn\ interrupt\ configuration\ */}}
\DoxyCodeLine{\Hypertarget{drv__uart_8c_source_l00066}00066\ \ \ HAL\_NVIC\_SetPriority(DMA2\_Stream7\_IRQn,\ 5,\ 0);}
\DoxyCodeLine{\Hypertarget{drv__uart_8c_source_l00067}00067\ \ \ HAL\_NVIC\_EnableIRQ(DMA2\_Stream7\_IRQn);}
\DoxyCodeLine{\Hypertarget{drv__uart_8c_source_l00068}00068\ }
\DoxyCodeLine{\Hypertarget{drv__uart_8c_source_l00069}00069\ \}}

\end{DoxyCode}

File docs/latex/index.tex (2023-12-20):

\chapter{Robot ROS}
\hypertarget{index}{}\label{index}\index{Robot ROS@{Robot ROS}}
  \hypertarget{index_Externe}{}\doxysection{\texorpdfstring{Externe documentation}{Externe documentation}}\label{index_Externe}
\href{base_robot.pdf}{\texttt{ Documentation about the pinout of the robot}}~\newline
\href{vl53l0x-datasheet-I2C.pdf}{\texttt{ I2C protocole for VLX530X}}~\newline
\hypertarget{index_Principal}{}\doxysection{\texorpdfstring{Principal function}{Principal function}}\label{index_Principal}
function \doxylink{main_8h_a840291bc02cba5474a4cb46a9b9566fe}{main} \+: init function and start kernel.~\newline
function \doxylink{main_8h_a5aca40d972a3057895d59e61e0e69678}{microros\+\_\+task} \+: Create the publishers and the subscribers and exploit them.~\newline
function \doxylink{main_8h_aeaf40c2ad14431735bdc8432bf5e57de}{task\+\_\+\+Motor\+\_\+\+Left} \+: Control the left motor.~\newline
function \doxylink{main_8h_a81f652726bff3b9832ab014d3fc28d1e}{task\+\_\+\+Motor\+\_\+\+Right} \+: Control the right motor.~\newline
function \doxylink{main_8h_a0770d7007222fbff5f97c3ea3b3cbb5c}{task\+\_\+\+VL53} \+: Get the VL53 measure and put it in the queue.~\newline
function \doxylink{main_8h_a0437f457b0f155ea2e19c99e841144f4}{task\+\_\+\+Grove\+\_\+\+LCD} \+: Get the information from rhe queue and print it on the LCD.~\newline
function \doxylink{main_8h_aa20650615a802a253757e491905b6af9}{task\+\_\+\+Supervision} \+: The brain\textquotesingle{}s robot decide of the action depending of data receive from micro\+ROS.~\newline
\hypertarget{index_Secondary}{}\doxysection{\texorpdfstring{Secondary function}{Secondary function}}\label{index_Secondary}
function \doxylink{micro_r_o_s_8h_a890a219b2095c02f9ad37f507e6e1bcb}{create\+Publisher} \+: use to create a default publisher.~\newline
function \doxylink{micro_r_o_s_8h_aa2d2993f945f17986c10ad57863224b5}{create\+Subscriber} \+: use to create a default subscriber.~\newline
function \doxylink{main_8h_a3f82047e1c93bff73e4db97a19f6ad2e}{CHECKMRRET} \+: Test if a micro\+Ros function success else print errror message.~\newline
function \doxylink{main_8h_afec8e194407d73381e7dfda42910309d}{Subscriber\+Callback\+Function} \+: callback call when message is receive.~\newline
\hypertarget{index_Test}{}\doxysection{\texorpdfstring{Test function}{Test function}}\label{index_Test}
function \doxylink{main_8h_a0068220a4432a5ea9b4442d018b706f8}{test\+\_\+uart2} \+: Test printf and scanf.~\newline
function \doxylink{main_8h_a03356c29f7343d5cd605bcd3e80e27e0}{test\+\_\+vl53} \+: Test VL53 sensors.~\newline
function \doxylink{main_8h_aac27f033a986ce7ecadc6f9532aa8c3a}{test\+\_\+motor} \+: Test correcteur.~\newline
\hypertarget{index_Config}{}\doxysection{\texorpdfstring{Config define}{Config define}}\label{index_Config}
\hypertarget{index_Exo}{}\doxysubsection{\texorpdfstring{Config exo}{Config exo}}\label{index_Exo}
\hypertarget{index_Param}{}\doxysubsection{\texorpdfstring{Config param}{Config param}}\label{index_Param}
\begin{DoxyAuthor}{Author}
\href{https://www.linkedin.com/in/titouan-melon}{\texttt{ Titouan Melon}}~\newline
\href{https://www.linkedin.com/in/louanne-floch}{\texttt{ Louanne Floch}}~\newline
\href{https://www.linkedin.com/in/j\%C3\%A9r\%C3\%A9my-plantec-7a24a81bb}{\texttt{ Jérémy Plantec}}~\newline
\href{https://www.linkedin.com/in/tognia-djanko-diallo-donald-b38281228}{\texttt{ Donald TOGNIA DJANKO DIALLO}}~\newline

\end{DoxyAuthor}
\begin{DoxyAttention}{Attention}

\end{DoxyAttention}
Copyright (c) 2022 STMicroelectronics. All rights reserved.

This software is licensed under terms that can be found in the LICENSE file in the root directory of this software component. If no LICENSE file comes with this software, it is provided AS-\/\+IS.

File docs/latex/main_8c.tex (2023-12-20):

\doxysection{C\+:/\+Users/\+Administrator/\+Documents/\+Git\+Hub/\+ENIB\+\_\+\+Robot\+\_\+\+Mobile\+\_\+\+Ros2/final\+Code/\+WORKSPACE\+\_\+\+F411\+\_\+u\+ROS/base\+\_\+robot/\+Core/\+Src/main.c File Reference}
\hypertarget{main_8c}{}\label{main_8c}\index{C:/Users/Administrator/Documents/GitHub/ENIB\_Robot\_Mobile\_Ros2/finalCode/WORKSPACE\_F411\_uROS/base\_robot/Core/Src/main.c@{C:/Users/Administrator/Documents/GitHub/ENIB\_Robot\_Mobile\_Ros2/finalCode/WORKSPACE\_F411\_uROS/base\_robot/Core/Src/main.c}}

file that contain the main code  

{\ttfamily \#include "{}main.\+h"{}}\newline
{\ttfamily \#include "{}motor\+Command.\+h"{}}\newline
{\ttfamily \#include "{}quad\+Encoder.\+h"{}}\newline
{\ttfamily \#include "{}capt\+Dist\+IR.\+h"{}}\newline
{\ttfamily \#include "{}VL53\+L0\+X.\+h"{}}\newline
{\ttfamily \#include "{}grove\+LCD.\+h"{}}\newline
\doxysubsubsection*{Data Structures}
\begin{DoxyCompactItemize}
\item 
struct \mbox{\hyperlink{struct_a_message}{AMessage}}
\item 
struct \mbox{\hyperlink{struct_micro_ros_pub_msg}{Micro\+Ros\+Pub\+Msg}}
\item 
struct \mbox{\hyperlink{struct_micro_ros_sub_msg}{Micro\+Ros\+Sub\+Msg}}
\end{DoxyCompactItemize}
\doxysubsubsection*{Macros}
\begin{DoxyCompactItemize}
\item 
\#define \mbox{\hyperlink{main_8c_a2e077c020d61734cb1ff60a0675673bd}{SAMPLING\+\_\+\+PERIOD\+\_\+ms}}~5
\end{DoxyCompactItemize}
\begin{Indent}\textbf{ config exo}\par
\begin{DoxyCompactItemize}
\item 
\#define \mbox{\hyperlink{main_8c_a515337f3365e5661ae661438b9e3287f}{EXSTARTUP}}~0
\item 
\#define \mbox{\hyperlink{main_8c_aa7a8b25b270619f1c6b15fd19a9454b7}{EXTEST\+\_\+\+UART2}}~1
\item 
\#define \mbox{\hyperlink{main_8c_af1effc30fa444fbfdd808d2cf02eee91}{EXCORRECTOR}}~2
\item 
\#define \mbox{\hyperlink{main_8c_a667f3a57a846fa3dd5c731e3540516be}{EXTESTCORRECTOR}}~3
\item 
\#define \mbox{\hyperlink{main_8c_a135f4fce99234202abb270c8e5593254}{EXTEST\+\_\+\+VL53}}~4
\item 
\#define \mbox{\hyperlink{main_8c_a078911f52c2ed596deab611e414f61b9}{EXTEST\+\_\+\+MICROROS}}~5
\item 
\#define \mbox{\hyperlink{main_8c_ae948c4c658b2bd925657c58f5b8f33ab}{EXFINAL}}~6
\item 
\#define \mbox{\hyperlink{main_8c_a81fc52cde1f4e885f6b60dca20bb031b}{SYNCHRO\+\_\+\+EX}}~\mbox{\hyperlink{main_8c_ae948c4c658b2bd925657c58f5b8f33ab}{EXFINAL}}
\end{DoxyCompactItemize}
\end{Indent}
\begin{Indent}\textbf{ config robot}\par
\begin{DoxyCompactItemize}
\item 
\#define \mbox{\hyperlink{main_8c_a6c7b89fa170faf81cf0702509bc7caef}{SEUIL\+\_\+\+DIST\+\_\+\+SENSOR}}~800
\item 
\#define \mbox{\hyperlink{main_8c_a3fd0b1ecf51c1cd847bb232b2fec904c}{ROS\+\_\+\+DOMAIN\+\_\+\+ID}}~0
\item 
\#define \mbox{\hyperlink{main_8c_abf2d80992dcfabfd1668184c3dff2733}{LCD}}~1
\item 
\#define \mbox{\hyperlink{main_8c_a39c8f0426010081d7f1fe74787adc164}{VL53}}~1
\item 
\#define \mbox{\hyperlink{main_8c_a96ea3637588f12d301b57f11d784daf3}{MICROROS}}~1
\item 
\#define \mbox{\hyperlink{main_8c_a2cc88864f2aaa74f3d4d09d76ac2961b}{DEBUG\+\_\+\+PRINTF}}~0
\item 
\#define \mbox{\hyperlink{main_8c_a86963c34eaf4aa7d9adc6e80a33871a7}{DEBUG\+\_\+\+MOTOR}}~0
\end{DoxyCompactItemize}
\end{Indent}
\begin{Indent}\textbf{ config correcteur}\par
\begin{DoxyCompactItemize}
\item 
\#define \mbox{\hyperlink{main_8c_a6a156e181d5d76e0ddd73ecc409ac9c3}{Te}}~SAMPLING\+\_\+\+PERIOD\+\_\+ms
\item 
\#define \mbox{\hyperlink{main_8c_ad0a3d11e0c5a60ce313ba4264e6eaba8}{LKp}}~0.\+001
\item 
\#define \mbox{\hyperlink{main_8c_a9c4bf434152b94b6a99df877f3a70185}{LKi}}~(5.\+0/(0.\+1\texorpdfstring{$\ast$}{*}40.\+0))
\item 
\#define \mbox{\hyperlink{main_8c_a7438270e3e1220d8d0bd82120273af12}{RKp}}~0.\+001
\item 
\#define \mbox{\hyperlink{main_8c_a8192f3340491948157f63db6418769aa}{RKi}}~(5.\+0/(0.\+1\texorpdfstring{$\ast$}{*}40.\+0))
\end{DoxyCompactItemize}
\end{Indent}
\begin{Indent}\textbf{ config default speed for each mode}\par
\begin{DoxyCompactItemize}
\item 
\#define \mbox{\hyperlink{main_8c_a0a5ceb9ceb914e08d345410b561cb37a}{CMD}}~1000
\item 
\#define \mbox{\hyperlink{main_8c_adad34192ac4bc13e73ed3be5a6309d53}{VITESSE\+\_\+\+KART}}~\mbox{\hyperlink{main_8c_a0a5ceb9ceb914e08d345410b561cb37a}{CMD}}/2
\item 
\#define \mbox{\hyperlink{main_8c_a71fa41f4b84f3fa3973737ac75e785a4}{VITESSE\+\_\+\+OBS}}~\mbox{\hyperlink{main_8c_a0a5ceb9ceb914e08d345410b561cb37a}{CMD}}
\item 
\#define \mbox{\hyperlink{main_8c_a83be4ba677a5b20cd4b969a5d2828f39}{VITESSE\+\_\+\+CAM}}~\mbox{\hyperlink{main_8c_a0a5ceb9ceb914e08d345410b561cb37a}{CMD}}/3
\end{DoxyCompactItemize}
\end{Indent}
\begin{Indent}\textbf{ config camera settings}\par
\begin{DoxyCompactItemize}
\item 
\#define \mbox{\hyperlink{main_8c_a4dee696e6f875ff0e01891dea054c4a1}{CAMERA\+\_\+\+X\+\_\+\+MIN}}~0
\item 
\#define \mbox{\hyperlink{main_8c_ab898595d41f7c7a6f5a7a7f2678c3bdd}{CAMERA\+\_\+\+X\+\_\+\+MAX}}~640
\item 
\#define \mbox{\hyperlink{main_8c_a9601c1b626116baa4ae182d8d32a7c41}{CAMERA\+\_\+\+Y\+\_\+\+MIN}}~0
\item 
\#define \mbox{\hyperlink{main_8c_a7f248c7643665aeacb8a58e541a60f50}{CAMERA\+\_\+\+Y\+\_\+\+MAX}}~480
\end{DoxyCompactItemize}
\end{Indent}
\begin{Indent}\textbf{ config default behaviour}\par
\begin{DoxyCompactItemize}
\item 
\#define \mbox{\hyperlink{main_8c_ab9c800875296f23bd616d7d273ff16d7}{DEFAULT\+\_\+\+MODE}}~MODE\+\_\+\+ZIG
\item 
\#define \mbox{\hyperlink{main_8c_afc945b2e8394478f97e2aabc7aebaf0e}{DEFAULT\+\_\+\+SPEED}}~LOW
\item 
\#define \mbox{\hyperlink{main_8c_a63ec0cea9c1f0ca8a7893c2c53d2fd81}{DEFAULT\+\_\+\+DIR}}~STOP
\end{DoxyCompactItemize}
\end{Indent}
\begin{Indent}\textbf{ config test value}\par
\begin{DoxyCompactItemize}
\item 
\#define \mbox{\hyperlink{main_8c_a58e95dc1eb9d6ce16f515e77beeadd58}{NB}}~200
\item 
\#define \mbox{\hyperlink{main_8c_a991a2b437e497b7c30f7c37f3da862c0}{TEST\+\_\+\+CORRECTOR\+\_\+\+DUTY}}~150
\item 
\#define \mbox{\hyperlink{main_8c_abfb9d3a25ca2e3a1dae1c814522ca875}{TEST\+\_\+\+CORRECTOR\+\_\+\+SPEEDL}}~-\/100
\item 
\#define \mbox{\hyperlink{main_8c_aafb3a6eb5ef46672cb007ee167d395a4}{TEST\+\_\+\+CORRECTOR\+\_\+\+SPEEDR}}~-\/100
\item 
\#define \mbox{\hyperlink{main_8c_ac8f0cb690a7ba18ff1d3bcac03a6205b}{TEST\+\_\+\+LEFT\+\_\+\+MOTOR}}~1
\end{DoxyCompactItemize}
\end{Indent}
\doxysubsubsection*{Enumerations}
\begin{DoxyCompactItemize}
\item 
enum \{ {\bfseries MODE\+\_\+\+OBS}
, {\bfseries MODE\+\_\+\+ZIG}
, {\bfseries MODE\+\_\+\+CAM}
, {\bfseries LAST\+\_\+\+MODE}
 \}
\item 
enum \{ \newline
{\bfseries STOP\+\_\+\+VIT}
, {\bfseries LOW}
, {\bfseries FAST}
, {\bfseries SONIC}
, \newline
{\bfseries LAST\+\_\+\+SPEED} =100
 \}
\item 
enum \{ \newline
{\bfseries AVANT}
, {\bfseries GAUCHE}
, {\bfseries RECULE}
, {\bfseries DROITE}
, \newline
{\bfseries STOP}
, {\bfseries AVANT\+\_\+\+GAUCHE}
, {\bfseries AVANT\+\_\+\+DROITE}
, {\bfseries RECULE\+\_\+\+GAUCHE}
, \newline
{\bfseries RECULE\+\_\+\+DROITE}
, {\bfseries LAST\+\_\+\+DIR}
 \}
\end{DoxyCompactItemize}
\doxysubsubsection*{Functions}
\begin{DoxyCompactItemize}
\item 
void \mbox{\hyperlink{main_8c_a70af21c671abfcc773614a9a4f63d920}{System\+Clock\+\_\+\+Config}} (void)
\item 
\Hypertarget{main_8c_a2504decd83a590057f35cbf3fb3d8a24}\label{main_8c_a2504decd83a590057f35cbf3fb3d8a24} 
bool {\bfseries cubemx\+\_\+transport\+\_\+open} (struct uxr\+Custom\+Transport \texorpdfstring{$\ast$}{*}transport)
\item 
\Hypertarget{main_8c_abbe7360a9584812682c8a6966a7f5f21}\label{main_8c_abbe7360a9584812682c8a6966a7f5f21} 
bool {\bfseries cubemx\+\_\+transport\+\_\+close} (struct uxr\+Custom\+Transport \texorpdfstring{$\ast$}{*}transport)
\item 
\Hypertarget{main_8c_a15743751ea08f8597ba27fb2d26b568c}\label{main_8c_a15743751ea08f8597ba27fb2d26b568c} 
size\+\_\+t {\bfseries cubemx\+\_\+transport\+\_\+write} (struct uxr\+Custom\+Transport \texorpdfstring{$\ast$}{*}transport, const uint8\+\_\+t \texorpdfstring{$\ast$}{*}buf, size\+\_\+t len, uint8\+\_\+t \texorpdfstring{$\ast$}{*}err)
\item 
\Hypertarget{main_8c_a607bea63774c226b5e25b7cc05921a72}\label{main_8c_a607bea63774c226b5e25b7cc05921a72} 
size\+\_\+t {\bfseries cubemx\+\_\+transport\+\_\+read} (struct uxr\+Custom\+Transport \texorpdfstring{$\ast$}{*}transport, uint8\+\_\+t \texorpdfstring{$\ast$}{*}buf, size\+\_\+t len, int timeout, uint8\+\_\+t \texorpdfstring{$\ast$}{*}err)
\item 
void \texorpdfstring{$\ast$}{*} \mbox{\hyperlink{main_8c_afbbd07004ef2541918f88b67c4af7a71}{microros\+\_\+allocate}} (size\+\_\+t size, void \texorpdfstring{$\ast$}{*}state)
\item 
void \mbox{\hyperlink{main_8c_aba9c00b570a317fad6f6d30220fada5b}{microros\+\_\+deallocate}} (void \texorpdfstring{$\ast$}{*}pointer, void \texorpdfstring{$\ast$}{*}state)
\item 
void \texorpdfstring{$\ast$}{*} \mbox{\hyperlink{main_8c_a3850b59e26ba636e5111bde82afafb01}{microros\+\_\+reallocate}} (void \texorpdfstring{$\ast$}{*}pointer, size\+\_\+t size, void \texorpdfstring{$\ast$}{*}state)
\item 
void \texorpdfstring{$\ast$}{*} \mbox{\hyperlink{main_8c_a74ab553464987a94faae5e414df0078a}{microros\+\_\+zero\+\_\+allocate}} (size\+\_\+t number\+\_\+of\+\_\+elements, size\+\_\+t size\+\_\+of\+\_\+element, void \texorpdfstring{$\ast$}{*}state)
\item 
void \mbox{\hyperlink{main_8c_a3f82047e1c93bff73e4db97a19f6ad2e}{CHECKMRRET}} (rcl\+\_\+ret\+\_\+t ret, char \texorpdfstring{$\ast$}{*}msg)
\item 
void \mbox{\hyperlink{main_8c_afec8e194407d73381e7dfda42910309d}{Subscriber\+Callback\+Function}} (const void \texorpdfstring{$\ast$}{*}msgin)
\item 
void \mbox{\hyperlink{main_8c_a5aca40d972a3057895d59e61e0e69678}{microros\+\_\+task}} (void \texorpdfstring{$\ast$}{*}argument)
\item 
void \mbox{\hyperlink{main_8c_aeaf40c2ad14431735bdc8432bf5e57de}{task\+\_\+\+Motor\+\_\+\+Left}} (void \texorpdfstring{$\ast$}{*}pv\+Parameters)
\item 
void \mbox{\hyperlink{main_8c_a81f652726bff3b9832ab014d3fc28d1e}{task\+\_\+\+Motor\+\_\+\+Right}} (void \texorpdfstring{$\ast$}{*}pv\+Parameters)
\item 
void \mbox{\hyperlink{main_8c_a0770d7007222fbff5f97c3ea3b3cbb5c}{task\+\_\+\+VL53}} (void \texorpdfstring{$\ast$}{*}pv\+Parameters)
\item 
void \mbox{\hyperlink{main_8c_a0437f457b0f155ea2e19c99e841144f4}{task\+\_\+\+Grove\+\_\+\+LCD}} (void \texorpdfstring{$\ast$}{*}pv\+Parameters)
\item 
void \mbox{\hyperlink{main_8c_aa20650615a802a253757e491905b6af9}{task\+\_\+\+Supervision}} (void \texorpdfstring{$\ast$}{*}pv\+Parameters)
\item 
int \mbox{\hyperlink{main_8c_a840291bc02cba5474a4cb46a9b9566fe}{main}} (void)
\item 
void \mbox{\hyperlink{main_8c_a0068220a4432a5ea9b4442d018b706f8}{test\+\_\+uart2}} (void \texorpdfstring{$\ast$}{*}pv\+Parameters)
\item 
void \mbox{\hyperlink{main_8c_a03356c29f7343d5cd605bcd3e80e27e0}{test\+\_\+vl53}} (void \texorpdfstring{$\ast$}{*}pv\+Parameters)
\item 
void \mbox{\hyperlink{main_8c_aac27f033a986ce7ecadc6f9532aa8c3a}{test\+\_\+motor}} (void \texorpdfstring{$\ast$}{*}pv\+Parameters)
\item 
void \mbox{\hyperlink{main_8c_a8a3b0ad512a6e6c6157440b68d395eac}{HAL\+\_\+\+TIM\+\_\+\+Period\+Elapsed\+Callback}} (TIM\+\_\+\+Handle\+Type\+Def \texorpdfstring{$\ast$}{*}htim)
\item 
void \mbox{\hyperlink{main_8c_a1730ffe1e560465665eb47d9264826f9}{Error\+\_\+\+Handler}} (void)
\end{DoxyCompactItemize}
\doxysubsubsection*{Variables}
\begin{DoxyCompactItemize}
\item 
UART\+\_\+\+Handle\+Type\+Def \mbox{\hyperlink{main_8c_a2cf715bef37f7e8ef385a30974a5f0d5}{huart1}}
\item 
UART\+\_\+\+Handle\+Type\+Def \mbox{\hyperlink{main_8c_aa9479c261d65eecedd3d9582f7f0f89c}{huart2}}
\item 
DMA\+\_\+\+Handle\+Type\+Def \mbox{\hyperlink{main_8c_a34251392f0d5e2461e3aef615918c235}{hdma\+\_\+usart1\+\_\+rx}}
\item 
DMA\+\_\+\+Handle\+Type\+Def \mbox{\hyperlink{main_8c_a5af94ab36bfe698db3e6beea96d10a90}{hdma\+\_\+usart1\+\_\+tx}}
\item 
DMA\+\_\+\+Handle\+Type\+Def \mbox{\hyperlink{main_8c_a784aa25dc7e4580cfbf80658340f482c}{hdma\+\_\+usart2\+\_\+rx}}
\item 
DMA\+\_\+\+Handle\+Type\+Def \mbox{\hyperlink{main_8c_a0083b476c2a75ab9fb2ccbed0048857e}{hdma\+\_\+usart2\+\_\+tx}}
\item 
I2\+C\+\_\+\+Handle\+Type\+Def \mbox{\hyperlink{main_8c_af7b2c26e44dadaaa798a5c3d82914ba7}{hi2c1}}
\item 
os\+Thread\+Id\+\_\+t \mbox{\hyperlink{main_8c_a6a263905468b0c37de4ee5e50ede4e74}{default\+Task\+Handle}}
\item 
const os\+Thread\+Attr\+\_\+t \mbox{\hyperlink{main_8c_a25fbb54afdba71c24ba51ed50166ac8d}{default\+Task\+\_\+attributes}}
\item 
int16\+\_\+t \mbox{\hyperlink{main_8c_a377891cff46d2f0a39f956b917366f95}{tab\+\_\+speed}} \mbox{[}\mbox{\hyperlink{main_8c_a58e95dc1eb9d6ce16f515e77beeadd58}{NB}}\mbox{]}
\end{DoxyCompactItemize}
\begin{Indent}\textbf{ semaphore}\par
\begin{DoxyCompactItemize}
\item 
x\+Semaphore\+Handle \mbox{\hyperlink{main_8c_a8c732ee84a40140fe90e1edb5e3fe61a}{x\+Sem\+\_\+\+Supervision}} = NULL
\end{DoxyCompactItemize}
\end{Indent}
\begin{Indent}\textbf{ queue\+Handle}\par
\begin{DoxyCompactItemize}
\item 
x\+Queue\+Handle \mbox{\hyperlink{main_8c_a938902e735d5df04bf790f601801da8e}{q\+\_\+mot\+\_\+L}} = NULL
\item 
x\+Queue\+Handle \mbox{\hyperlink{main_8c_aa26ca3e16f249f82045250c09e1cd053}{q\+\_\+mot\+\_\+R}} = NULL
\item 
x\+Queue\+Handle \mbox{\hyperlink{main_8c_a2313a36ccf1c497c3b1595ad8f7a266a}{qh\+MR\+\_\+sub}} = NULL
\item 
x\+Queue\+Handle \mbox{\hyperlink{main_8c_a2ec1e708e81871b5c6929cb901a69c51}{qh\+MR\+\_\+pub}} = NULL
\item 
x\+Queue\+Handle \mbox{\hyperlink{main_8c_a494090d44b64e4d33b49a38031ede042}{qh\+LCD}} = NULL
\item 
x\+Queue\+Handle \mbox{\hyperlink{main_8c_a3350c1d692cc188bf1b42c2a3810b9d1}{qh\+Vl53}} = NULL
\end{DoxyCompactItemize}
\end{Indent}

\doxysubsection{Detailed Description}
file that contain the main code 

Definition in file \mbox{\hyperlink{main_8c_source}{main.\+c}}.

\doxysubsection{Macro Definition Documentation}
\Hypertarget{main_8c_ab898595d41f7c7a6f5a7a7f2678c3bdd}\label{main_8c_ab898595d41f7c7a6f5a7a7f2678c3bdd} 
\index{main.c@{main.c}!CAMERA\_X\_MAX@{CAMERA\_X\_MAX}}
\index{CAMERA\_X\_MAX@{CAMERA\_X\_MAX}!main.c@{main.c}}
\doxysubsubsection{\texorpdfstring{CAMERA\_X\_MAX}{CAMERA\_X\_MAX}}
{\footnotesize\ttfamily \#define CAMERA\+\_\+\+X\+\_\+\+MAX~640}

Define maximal x position return by camera 

Definition at line \mbox{\hyperlink{main_8c_source_l00073}{73}} of file \mbox{\hyperlink{main_8c_source}{main.\+c}}.

\Hypertarget{main_8c_a4dee696e6f875ff0e01891dea054c4a1}\label{main_8c_a4dee696e6f875ff0e01891dea054c4a1} 
\index{main.c@{main.c}!CAMERA\_X\_MIN@{CAMERA\_X\_MIN}}
\index{CAMERA\_X\_MIN@{CAMERA\_X\_MIN}!main.c@{main.c}}
\doxysubsubsection{\texorpdfstring{CAMERA\_X\_MIN}{CAMERA\_X\_MIN}}
{\footnotesize\ttfamily \#define CAMERA\+\_\+\+X\+\_\+\+MIN~0}

Define minimal x position return by camera 

Definition at line \mbox{\hyperlink{main_8c_source_l00072}{72}} of file \mbox{\hyperlink{main_8c_source}{main.\+c}}.

\Hypertarget{main_8c_a7f248c7643665aeacb8a58e541a60f50}\label{main_8c_a7f248c7643665aeacb8a58e541a60f50} 
\index{main.c@{main.c}!CAMERA\_Y\_MAX@{CAMERA\_Y\_MAX}}
\index{CAMERA\_Y\_MAX@{CAMERA\_Y\_MAX}!main.c@{main.c}}
\doxysubsubsection{\texorpdfstring{CAMERA\_Y\_MAX}{CAMERA\_Y\_MAX}}
{\footnotesize\ttfamily \#define CAMERA\+\_\+\+Y\+\_\+\+MAX~480}

Define maximal y position return by camera 

Definition at line \mbox{\hyperlink{main_8c_source_l00075}{75}} of file \mbox{\hyperlink{main_8c_source}{main.\+c}}.

\Hypertarget{main_8c_a9601c1b626116baa4ae182d8d32a7c41}\label{main_8c_a9601c1b626116baa4ae182d8d32a7c41} 
\index{main.c@{main.c}!CAMERA\_Y\_MIN@{CAMERA\_Y\_MIN}}
\index{CAMERA\_Y\_MIN@{CAMERA\_Y\_MIN}!main.c@{main.c}}
\doxysubsubsection{\texorpdfstring{CAMERA\_Y\_MIN}{CAMERA\_Y\_MIN}}
{\footnotesize\ttfamily \#define CAMERA\+\_\+\+Y\+\_\+\+MIN~0}

Define minimal y position return by camera 

Definition at line \mbox{\hyperlink{main_8c_source_l00074}{74}} of file \mbox{\hyperlink{main_8c_source}{main.\+c}}.

\Hypertarget{main_8c_a0a5ceb9ceb914e08d345410b561cb37a}\label{main_8c_a0a5ceb9ceb914e08d345410b561cb37a} 
\index{main.c@{main.c}!CMD@{CMD}}
\index{CMD@{CMD}!main.c@{main.c}}
\doxysubsubsection{\texorpdfstring{CMD}{CMD}}
{\footnotesize\ttfamily \#define CMD~1000}

Can be use as default speed 

Definition at line \mbox{\hyperlink{main_8c_source_l00066}{66}} of file \mbox{\hyperlink{main_8c_source}{main.\+c}}.

\Hypertarget{main_8c_a86963c34eaf4aa7d9adc6e80a33871a7}\label{main_8c_a86963c34eaf4aa7d9adc6e80a33871a7} 
\index{main.c@{main.c}!DEBUG\_MOTOR@{DEBUG\_MOTOR}}
\index{DEBUG\_MOTOR@{DEBUG\_MOTOR}!main.c@{main.c}}
\doxysubsubsection{\texorpdfstring{DEBUG\_MOTOR}{DEBUG\_MOTOR}}
{\footnotesize\ttfamily \#define DEBUG\+\_\+\+MOTOR~0}

Activate motor debug print 

Definition at line \mbox{\hyperlink{main_8c_source_l00056}{56}} of file \mbox{\hyperlink{main_8c_source}{main.\+c}}.

\Hypertarget{main_8c_a2cc88864f2aaa74f3d4d09d76ac2961b}\label{main_8c_a2cc88864f2aaa74f3d4d09d76ac2961b} 
\index{main.c@{main.c}!DEBUG\_PRINTF@{DEBUG\_PRINTF}}
\index{DEBUG\_PRINTF@{DEBUG\_PRINTF}!main.c@{main.c}}
\doxysubsubsection{\texorpdfstring{DEBUG\_PRINTF}{DEBUG\_PRINTF}}
{\footnotesize\ttfamily \#define DEBUG\+\_\+\+PRINTF~0}

Activate debug print 

Definition at line \mbox{\hyperlink{main_8c_source_l00055}{55}} of file \mbox{\hyperlink{main_8c_source}{main.\+c}}.

\Hypertarget{main_8c_a63ec0cea9c1f0ca8a7893c2c53d2fd81}\label{main_8c_a63ec0cea9c1f0ca8a7893c2c53d2fd81} 
\index{main.c@{main.c}!DEFAULT\_DIR@{DEFAULT\_DIR}}
\index{DEFAULT\_DIR@{DEFAULT\_DIR}!main.c@{main.c}}
\doxysubsubsection{\texorpdfstring{DEFAULT\_DIR}{DEFAULT\_DIR}}
{\footnotesize\ttfamily \#define DEFAULT\+\_\+\+DIR~STOP}

Default direction at startup 

Definition at line \mbox{\hyperlink{main_8c_source_l00082}{82}} of file \mbox{\hyperlink{main_8c_source}{main.\+c}}.

\Hypertarget{main_8c_ab9c800875296f23bd616d7d273ff16d7}\label{main_8c_ab9c800875296f23bd616d7d273ff16d7} 
\index{main.c@{main.c}!DEFAULT\_MODE@{DEFAULT\_MODE}}
\index{DEFAULT\_MODE@{DEFAULT\_MODE}!main.c@{main.c}}
\doxysubsubsection{\texorpdfstring{DEFAULT\_MODE}{DEFAULT\_MODE}}
{\footnotesize\ttfamily \#define DEFAULT\+\_\+\+MODE~MODE\+\_\+\+ZIG}

Default mode at startup 

Definition at line \mbox{\hyperlink{main_8c_source_l00080}{80}} of file \mbox{\hyperlink{main_8c_source}{main.\+c}}.

\Hypertarget{main_8c_afc945b2e8394478f97e2aabc7aebaf0e}\label{main_8c_afc945b2e8394478f97e2aabc7aebaf0e} 
\index{main.c@{main.c}!DEFAULT\_SPEED@{DEFAULT\_SPEED}}
\index{DEFAULT\_SPEED@{DEFAULT\_SPEED}!main.c@{main.c}}
\doxysubsubsection{\texorpdfstring{DEFAULT\_SPEED}{DEFAULT\_SPEED}}
{\footnotesize\ttfamily \#define DEFAULT\+\_\+\+SPEED~LOW}

Default speed at startup 

Definition at line \mbox{\hyperlink{main_8c_source_l00081}{81}} of file \mbox{\hyperlink{main_8c_source}{main.\+c}}.

\Hypertarget{main_8c_af1effc30fa444fbfdd808d2cf02eee91}\label{main_8c_af1effc30fa444fbfdd808d2cf02eee91} 
\index{main.c@{main.c}!EXCORRECTOR@{EXCORRECTOR}}
\index{EXCORRECTOR@{EXCORRECTOR}!main.c@{main.c}}
\doxysubsubsection{\texorpdfstring{EXCORRECTOR}{EXCORRECTOR}}
{\footnotesize\ttfamily \#define EXCORRECTOR~2}

Code to calibrate your correcteur 

Definition at line \mbox{\hyperlink{main_8c_source_l00041}{41}} of file \mbox{\hyperlink{main_8c_source}{main.\+c}}.

\Hypertarget{main_8c_ae948c4c658b2bd925657c58f5b8f33ab}\label{main_8c_ae948c4c658b2bd925657c58f5b8f33ab} 
\index{main.c@{main.c}!EXFINAL@{EXFINAL}}
\index{EXFINAL@{EXFINAL}!main.c@{main.c}}
\doxysubsubsection{\texorpdfstring{EXFINAL}{EXFINAL}}
{\footnotesize\ttfamily \#define EXFINAL~6}

Final code 

Definition at line \mbox{\hyperlink{main_8c_source_l00045}{45}} of file \mbox{\hyperlink{main_8c_source}{main.\+c}}.

\Hypertarget{main_8c_a515337f3365e5661ae661438b9e3287f}\label{main_8c_a515337f3365e5661ae661438b9e3287f} 
\index{main.c@{main.c}!EXSTARTUP@{EXSTARTUP}}
\index{EXSTARTUP@{EXSTARTUP}!main.c@{main.c}}
\doxysubsubsection{\texorpdfstring{EXSTARTUP}{EXSTARTUP}}
{\footnotesize\ttfamily \#define EXSTARTUP~0}

startup code 

Definition at line \mbox{\hyperlink{main_8c_source_l00039}{39}} of file \mbox{\hyperlink{main_8c_source}{main.\+c}}.

\Hypertarget{main_8c_a078911f52c2ed596deab611e414f61b9}\label{main_8c_a078911f52c2ed596deab611e414f61b9} 
\index{main.c@{main.c}!EXTEST\_MICROROS@{EXTEST\_MICROROS}}
\index{EXTEST\_MICROROS@{EXTEST\_MICROROS}!main.c@{main.c}}
\doxysubsubsection{\texorpdfstring{EXTEST\_MICROROS}{EXTEST\_MICROROS}}
{\footnotesize\ttfamily \#define EXTEST\+\_\+\+MICROROS~5}

Test Micro ROS subscriber and publisher 

Definition at line \mbox{\hyperlink{main_8c_source_l00044}{44}} of file \mbox{\hyperlink{main_8c_source}{main.\+c}}.

\Hypertarget{main_8c_aa7a8b25b270619f1c6b15fd19a9454b7}\label{main_8c_aa7a8b25b270619f1c6b15fd19a9454b7} 
\index{main.c@{main.c}!EXTEST\_UART2@{EXTEST\_UART2}}
\index{EXTEST\_UART2@{EXTEST\_UART2}!main.c@{main.c}}
\doxysubsubsection{\texorpdfstring{EXTEST\_UART2}{EXTEST\_UART2}}
{\footnotesize\ttfamily \#define EXTEST\+\_\+\+UART2~1}

Test printf and scanf function 

Definition at line \mbox{\hyperlink{main_8c_source_l00040}{40}} of file \mbox{\hyperlink{main_8c_source}{main.\+c}}.

\Hypertarget{main_8c_a135f4fce99234202abb270c8e5593254}\label{main_8c_a135f4fce99234202abb270c8e5593254} 
\index{main.c@{main.c}!EXTEST\_VL53@{EXTEST\_VL53}}
\index{EXTEST\_VL53@{EXTEST\_VL53}!main.c@{main.c}}
\doxysubsubsection{\texorpdfstring{EXTEST\_VL53}{EXTEST\_VL53}}
{\footnotesize\ttfamily \#define EXTEST\+\_\+\+VL53~4}

Test VL530X sensor 

Definition at line \mbox{\hyperlink{main_8c_source_l00043}{43}} of file \mbox{\hyperlink{main_8c_source}{main.\+c}}.

\Hypertarget{main_8c_a667f3a57a846fa3dd5c731e3540516be}\label{main_8c_a667f3a57a846fa3dd5c731e3540516be} 
\index{main.c@{main.c}!EXTESTCORRECTOR@{EXTESTCORRECTOR}}
\index{EXTESTCORRECTOR@{EXTESTCORRECTOR}!main.c@{main.c}}
\doxysubsubsection{\texorpdfstring{EXTESTCORRECTOR}{EXTESTCORRECTOR}}
{\footnotesize\ttfamily \#define EXTESTCORRECTOR~3}

Code to test your correcteur 

Definition at line \mbox{\hyperlink{main_8c_source_l00042}{42}} of file \mbox{\hyperlink{main_8c_source}{main.\+c}}.

\Hypertarget{main_8c_abf2d80992dcfabfd1668184c3dff2733}\label{main_8c_abf2d80992dcfabfd1668184c3dff2733} 
\index{main.c@{main.c}!LCD@{LCD}}
\index{LCD@{LCD}!main.c@{main.c}}
\doxysubsubsection{\texorpdfstring{LCD}{LCD}}
{\footnotesize\ttfamily \#define LCD~1}

Activate LCD task 

Definition at line \mbox{\hyperlink{main_8c_source_l00052}{52}} of file \mbox{\hyperlink{main_8c_source}{main.\+c}}.

\Hypertarget{main_8c_a9c4bf434152b94b6a99df877f3a70185}\label{main_8c_a9c4bf434152b94b6a99df877f3a70185} 
\index{main.c@{main.c}!LKi@{LKi}}
\index{LKi@{LKi}!main.c@{main.c}}
\doxysubsubsection{\texorpdfstring{LKi}{LKi}}
{\footnotesize\ttfamily \#define LKi~(5.\+0/(0.\+1\texorpdfstring{$\ast$}{*}40.\+0))}

Ki factor for the left motor 

Definition at line \mbox{\hyperlink{main_8c_source_l00061}{61}} of file \mbox{\hyperlink{main_8c_source}{main.\+c}}.

\Hypertarget{main_8c_ad0a3d11e0c5a60ce313ba4264e6eaba8}\label{main_8c_ad0a3d11e0c5a60ce313ba4264e6eaba8} 
\index{main.c@{main.c}!LKp@{LKp}}
\index{LKp@{LKp}!main.c@{main.c}}
\doxysubsubsection{\texorpdfstring{LKp}{LKp}}
{\footnotesize\ttfamily \#define LKp~0.\+001}

Kp factor for the left motor 

Definition at line \mbox{\hyperlink{main_8c_source_l00060}{60}} of file \mbox{\hyperlink{main_8c_source}{main.\+c}}.

\Hypertarget{main_8c_a96ea3637588f12d301b57f11d784daf3}\label{main_8c_a96ea3637588f12d301b57f11d784daf3} 
\index{main.c@{main.c}!MICROROS@{MICROROS}}
\index{MICROROS@{MICROROS}!main.c@{main.c}}
\doxysubsubsection{\texorpdfstring{MICROROS}{MICROROS}}
{\footnotesize\ttfamily \#define MICROROS~1}

Activate Micro\+ROS task 

Definition at line \mbox{\hyperlink{main_8c_source_l00054}{54}} of file \mbox{\hyperlink{main_8c_source}{main.\+c}}.

\Hypertarget{main_8c_a58e95dc1eb9d6ce16f515e77beeadd58}\label{main_8c_a58e95dc1eb9d6ce16f515e77beeadd58} 
\index{main.c@{main.c}!NB@{NB}}
\index{NB@{NB}!main.c@{main.c}}
\doxysubsubsection{\texorpdfstring{NB}{NB}}
{\footnotesize\ttfamily \#define NB~200}

Number of samples in correcteur calibration task 

Definition at line \mbox{\hyperlink{main_8c_source_l00085}{85}} of file \mbox{\hyperlink{main_8c_source}{main.\+c}}.

\Hypertarget{main_8c_a8192f3340491948157f63db6418769aa}\label{main_8c_a8192f3340491948157f63db6418769aa} 
\index{main.c@{main.c}!RKi@{RKi}}
\index{RKi@{RKi}!main.c@{main.c}}
\doxysubsubsection{\texorpdfstring{RKi}{RKi}}
{\footnotesize\ttfamily \#define RKi~(5.\+0/(0.\+1\texorpdfstring{$\ast$}{*}40.\+0))}

Kp factor for the right motor 

Definition at line \mbox{\hyperlink{main_8c_source_l00063}{63}} of file \mbox{\hyperlink{main_8c_source}{main.\+c}}.

\Hypertarget{main_8c_a7438270e3e1220d8d0bd82120273af12}\label{main_8c_a7438270e3e1220d8d0bd82120273af12} 
\index{main.c@{main.c}!RKp@{RKp}}
\index{RKp@{RKp}!main.c@{main.c}}
\doxysubsubsection{\texorpdfstring{RKp}{RKp}}
{\footnotesize\ttfamily \#define RKp~0.\+001}

Kp factor for the right motor 

Definition at line \mbox{\hyperlink{main_8c_source_l00062}{62}} of file \mbox{\hyperlink{main_8c_source}{main.\+c}}.

\Hypertarget{main_8c_a3fd0b1ecf51c1cd847bb232b2fec904c}\label{main_8c_a3fd0b1ecf51c1cd847bb232b2fec904c} 
\index{main.c@{main.c}!ROS\_DOMAIN\_ID@{ROS\_DOMAIN\_ID}}
\index{ROS\_DOMAIN\_ID@{ROS\_DOMAIN\_ID}!main.c@{main.c}}
\doxysubsubsection{\texorpdfstring{ROS\_DOMAIN\_ID}{ROS\_DOMAIN\_ID}}
{\footnotesize\ttfamily \#define ROS\+\_\+\+DOMAIN\+\_\+\+ID~0}

Define ROS domain id 

Definition at line \mbox{\hyperlink{main_8c_source_l00051}{51}} of file \mbox{\hyperlink{main_8c_source}{main.\+c}}.

\Hypertarget{main_8c_a2e077c020d61734cb1ff60a0675673bd}\label{main_8c_a2e077c020d61734cb1ff60a0675673bd} 
\index{main.c@{main.c}!SAMPLING\_PERIOD\_ms@{SAMPLING\_PERIOD\_ms}}
\index{SAMPLING\_PERIOD\_ms@{SAMPLING\_PERIOD\_ms}!main.c@{main.c}}
\doxysubsubsection{\texorpdfstring{SAMPLING\_PERIOD\_ms}{SAMPLING\_PERIOD\_ms}}
{\footnotesize\ttfamily \#define SAMPLING\+\_\+\+PERIOD\+\_\+ms~5}

Define the delay beetween two execution of the same task 

Definition at line \mbox{\hyperlink{main_8c_source_l00037}{37}} of file \mbox{\hyperlink{main_8c_source}{main.\+c}}.

\Hypertarget{main_8c_a6c7b89fa170faf81cf0702509bc7caef}\label{main_8c_a6c7b89fa170faf81cf0702509bc7caef} 
\index{main.c@{main.c}!SEUIL\_DIST\_SENSOR@{SEUIL\_DIST\_SENSOR}}
\index{SEUIL\_DIST\_SENSOR@{SEUIL\_DIST\_SENSOR}!main.c@{main.c}}
\doxysubsubsection{\texorpdfstring{SEUIL\_DIST\_SENSOR}{SEUIL\_DIST\_SENSOR}}
{\footnotesize\ttfamily \#define SEUIL\+\_\+\+DIST\+\_\+\+SENSOR~800}

Define the trigger for forward sensors4 

Definition at line \mbox{\hyperlink{main_8c_source_l00050}{50}} of file \mbox{\hyperlink{main_8c_source}{main.\+c}}.

\Hypertarget{main_8c_a81fc52cde1f4e885f6b60dca20bb031b}\label{main_8c_a81fc52cde1f4e885f6b60dca20bb031b} 
\index{main.c@{main.c}!SYNCHRO\_EX@{SYNCHRO\_EX}}
\index{SYNCHRO\_EX@{SYNCHRO\_EX}!main.c@{main.c}}
\doxysubsubsection{\texorpdfstring{SYNCHRO\_EX}{SYNCHRO\_EX}}
{\footnotesize\ttfamily \#define SYNCHRO\+\_\+\+EX~\mbox{\hyperlink{main_8c_ae948c4c658b2bd925657c58f5b8f33ab}{EXFINAL}}}

Define wich config are executed 

Definition at line \mbox{\hyperlink{main_8c_source_l00047}{47}} of file \mbox{\hyperlink{main_8c_source}{main.\+c}}.

\Hypertarget{main_8c_a6a156e181d5d76e0ddd73ecc409ac9c3}\label{main_8c_a6a156e181d5d76e0ddd73ecc409ac9c3} 
\index{main.c@{main.c}!Te@{Te}}
\index{Te@{Te}!main.c@{main.c}}
\doxysubsubsection{\texorpdfstring{Te}{Te}}
{\footnotesize\ttfamily \#define Te~SAMPLING\+\_\+\+PERIOD\+\_\+ms}

Definition at line \mbox{\hyperlink{main_8c_source_l00059}{59}} of file \mbox{\hyperlink{main_8c_source}{main.\+c}}.

\Hypertarget{main_8c_a991a2b437e497b7c30f7c37f3da862c0}\label{main_8c_a991a2b437e497b7c30f7c37f3da862c0} 
\index{main.c@{main.c}!TEST\_CORRECTOR\_DUTY@{TEST\_CORRECTOR\_DUTY}}
\index{TEST\_CORRECTOR\_DUTY@{TEST\_CORRECTOR\_DUTY}!main.c@{main.c}}
\doxysubsubsection{\texorpdfstring{TEST\_CORRECTOR\_DUTY}{TEST\_CORRECTOR\_DUTY}}
{\footnotesize\ttfamily \#define TEST\+\_\+\+CORRECTOR\+\_\+\+DUTY~150}

Duty cycle to apply to calibrate the correcteur 

Definition at line \mbox{\hyperlink{main_8c_source_l00086}{86}} of file \mbox{\hyperlink{main_8c_source}{main.\+c}}.

\Hypertarget{main_8c_abfb9d3a25ca2e3a1dae1c814522ca875}\label{main_8c_abfb9d3a25ca2e3a1dae1c814522ca875} 
\index{main.c@{main.c}!TEST\_CORRECTOR\_SPEEDL@{TEST\_CORRECTOR\_SPEEDL}}
\index{TEST\_CORRECTOR\_SPEEDL@{TEST\_CORRECTOR\_SPEEDL}!main.c@{main.c}}
\doxysubsubsection{\texorpdfstring{TEST\_CORRECTOR\_SPEEDL}{TEST\_CORRECTOR\_SPEEDL}}
{\footnotesize\ttfamily \#define TEST\+\_\+\+CORRECTOR\+\_\+\+SPEEDL~-\/100}

Speed to test the left correcteur 

Definition at line \mbox{\hyperlink{main_8c_source_l00087}{87}} of file \mbox{\hyperlink{main_8c_source}{main.\+c}}.

\Hypertarget{main_8c_aafb3a6eb5ef46672cb007ee167d395a4}\label{main_8c_aafb3a6eb5ef46672cb007ee167d395a4} 
\index{main.c@{main.c}!TEST\_CORRECTOR\_SPEEDR@{TEST\_CORRECTOR\_SPEEDR}}
\index{TEST\_CORRECTOR\_SPEEDR@{TEST\_CORRECTOR\_SPEEDR}!main.c@{main.c}}
\doxysubsubsection{\texorpdfstring{TEST\_CORRECTOR\_SPEEDR}{TEST\_CORRECTOR\_SPEEDR}}
{\footnotesize\ttfamily \#define TEST\+\_\+\+CORRECTOR\+\_\+\+SPEEDR~-\/100}

Speed to test the right correcteur 

Definition at line \mbox{\hyperlink{main_8c_source_l00088}{88}} of file \mbox{\hyperlink{main_8c_source}{main.\+c}}.

\Hypertarget{main_8c_ac8f0cb690a7ba18ff1d3bcac03a6205b}\label{main_8c_ac8f0cb690a7ba18ff1d3bcac03a6205b} 
\index{main.c@{main.c}!TEST\_LEFT\_MOTOR@{TEST\_LEFT\_MOTOR}}
\index{TEST\_LEFT\_MOTOR@{TEST\_LEFT\_MOTOR}!main.c@{main.c}}
\doxysubsubsection{\texorpdfstring{TEST\_LEFT\_MOTOR}{TEST\_LEFT\_MOTOR}}
{\footnotesize\ttfamily \#define TEST\+\_\+\+LEFT\+\_\+\+MOTOR~1}

Calibrate left motor correcteur or not 

Definition at line \mbox{\hyperlink{main_8c_source_l00089}{89}} of file \mbox{\hyperlink{main_8c_source}{main.\+c}}.

\Hypertarget{main_8c_a83be4ba677a5b20cd4b969a5d2828f39}\label{main_8c_a83be4ba677a5b20cd4b969a5d2828f39} 
\index{main.c@{main.c}!VITESSE\_CAM@{VITESSE\_CAM}}
\index{VITESSE\_CAM@{VITESSE\_CAM}!main.c@{main.c}}
\doxysubsubsection{\texorpdfstring{VITESSE\_CAM}{VITESSE\_CAM}}
{\footnotesize\ttfamily \#define VITESSE\+\_\+\+CAM~\mbox{\hyperlink{main_8c_a0a5ceb9ceb914e08d345410b561cb37a}{CMD}}/3}

Default speed for camera mode 

Definition at line \mbox{\hyperlink{main_8c_source_l00069}{69}} of file \mbox{\hyperlink{main_8c_source}{main.\+c}}.

\Hypertarget{main_8c_adad34192ac4bc13e73ed3be5a6309d53}\label{main_8c_adad34192ac4bc13e73ed3be5a6309d53} 
\index{main.c@{main.c}!VITESSE\_KART@{VITESSE\_KART}}
\index{VITESSE\_KART@{VITESSE\_KART}!main.c@{main.c}}
\doxysubsubsection{\texorpdfstring{VITESSE\_KART}{VITESSE\_KART}}
{\footnotesize\ttfamily \#define VITESSE\+\_\+\+KART~\mbox{\hyperlink{main_8c_a0a5ceb9ceb914e08d345410b561cb37a}{CMD}}/2}

Default speed for manual mode 

Definition at line \mbox{\hyperlink{main_8c_source_l00067}{67}} of file \mbox{\hyperlink{main_8c_source}{main.\+c}}.

\Hypertarget{main_8c_a71fa41f4b84f3fa3973737ac75e785a4}\label{main_8c_a71fa41f4b84f3fa3973737ac75e785a4} 
\index{main.c@{main.c}!VITESSE\_OBS@{VITESSE\_OBS}}
\index{VITESSE\_OBS@{VITESSE\_OBS}!main.c@{main.c}}
\doxysubsubsection{\texorpdfstring{VITESSE\_OBS}{VITESSE\_OBS}}
{\footnotesize\ttfamily \#define VITESSE\+\_\+\+OBS~\mbox{\hyperlink{main_8c_a0a5ceb9ceb914e08d345410b561cb37a}{CMD}}}

Default speed for obstacle mode 

Definition at line \mbox{\hyperlink{main_8c_source_l00068}{68}} of file \mbox{\hyperlink{main_8c_source}{main.\+c}}.

\Hypertarget{main_8c_a39c8f0426010081d7f1fe74787adc164}\label{main_8c_a39c8f0426010081d7f1fe74787adc164} 
\index{main.c@{main.c}!VL53@{VL53}}
\index{VL53@{VL53}!main.c@{main.c}}
\doxysubsubsection{\texorpdfstring{VL53}{VL53}}
{\footnotesize\ttfamily \#define VL53~1}

Activate VL530X task 

Definition at line \mbox{\hyperlink{main_8c_source_l00053}{53}} of file \mbox{\hyperlink{main_8c_source}{main.\+c}}.

\doxysubsection{Enumeration Type Documentation}
\Hypertarget{main_8c_a06fc87d81c62e9abb8790b6e5713c55b}\label{main_8c_a06fc87d81c62e9abb8790b6e5713c55b} 
\doxysubsubsection{\texorpdfstring{anonymous enum}{anonymous enum}}
{\footnotesize\ttfamily anonymous enum}

enumerate mode of robot 

Definition at line \mbox{\hyperlink{main_8c_source_l00031}{31}} of file \mbox{\hyperlink{main_8c_source}{main.\+c}}.

\Hypertarget{main_8c_adf764cbdea00d65edcd07bb9953ad2b7}\label{main_8c_adf764cbdea00d65edcd07bb9953ad2b7} 
\doxysubsubsection{\texorpdfstring{anonymous enum}{anonymous enum}}
{\footnotesize\ttfamily anonymous enum}

enumerate speed 

Definition at line \mbox{\hyperlink{main_8c_source_l00033}{33}} of file \mbox{\hyperlink{main_8c_source}{main.\+c}}.

\Hypertarget{main_8c_a99fb83031ce9923c84392b4e92f956b5}\label{main_8c_a99fb83031ce9923c84392b4e92f956b5} 
\doxysubsubsection{\texorpdfstring{anonymous enum}{anonymous enum}}
{\footnotesize\ttfamily anonymous enum}

enumerate direction 

Definition at line \mbox{\hyperlink{main_8c_source_l00035}{35}} of file \mbox{\hyperlink{main_8c_source}{main.\+c}}.

\doxysubsection{Function Documentation}
\Hypertarget{main_8c_a3f82047e1c93bff73e4db97a19f6ad2e}\label{main_8c_a3f82047e1c93bff73e4db97a19f6ad2e} 
\index{main.c@{main.c}!CHECKMRRET@{CHECKMRRET}}
\index{CHECKMRRET@{CHECKMRRET}!main.c@{main.c}}
\doxysubsubsection{\texorpdfstring{CHECKMRRET()}{CHECKMRRET()}}
{\footnotesize\ttfamily void CHECKMRRET (\begin{DoxyParamCaption}\item[{rcl\+\_\+ret\+\_\+t}]{ret,  }\item[{char \texorpdfstring{$\ast$}{*}}]{msg }\end{DoxyParamCaption})}

check if micro\+Ros function success else print msg in console 
\begin{DoxyParams}{Parameters}
{\em ret} & return value of micro\+Ros function \\
\hline
{\em msg} & message to print if fail \\
\hline
\end{DoxyParams}

Definition at line \mbox{\hyperlink{main_8c_source_l00154}{154}} of file \mbox{\hyperlink{main_8c_source}{main.\+c}}.

\Hypertarget{main_8c_a1730ffe1e560465665eb47d9264826f9}\label{main_8c_a1730ffe1e560465665eb47d9264826f9} 
\index{main.c@{main.c}!Error\_Handler@{Error\_Handler}}
\index{Error\_Handler@{Error\_Handler}!main.c@{main.c}}
\doxysubsubsection{\texorpdfstring{Error\_Handler()}{Error\_Handler()}}
{\footnotesize\ttfamily void Error\+\_\+\+Handler (\begin{DoxyParamCaption}\item[{void}]{ }\end{DoxyParamCaption})}

Definition at line \mbox{\hyperlink{main_8c_source_l00914}{914}} of file \mbox{\hyperlink{main_8c_source}{main.\+c}}.

\Hypertarget{main_8c_a8a3b0ad512a6e6c6157440b68d395eac}\label{main_8c_a8a3b0ad512a6e6c6157440b68d395eac} 
\index{main.c@{main.c}!HAL\_TIM\_PeriodElapsedCallback@{HAL\_TIM\_PeriodElapsedCallback}}
\index{HAL\_TIM\_PeriodElapsedCallback@{HAL\_TIM\_PeriodElapsedCallback}!main.c@{main.c}}
\doxysubsubsection{\texorpdfstring{HAL\_TIM\_PeriodElapsedCallback()}{HAL\_TIM\_PeriodElapsedCallback()}}
{\footnotesize\ttfamily void HAL\+\_\+\+TIM\+\_\+\+Period\+Elapsed\+Callback (\begin{DoxyParamCaption}\item[{TIM\+\_\+\+Handle\+Type\+Def \texorpdfstring{$\ast$}{*}}]{htim }\end{DoxyParamCaption})}

Definition at line \mbox{\hyperlink{main_8c_source_l00906}{906}} of file \mbox{\hyperlink{main_8c_source}{main.\+c}}.

\Hypertarget{main_8c_a840291bc02cba5474a4cb46a9b9566fe}\label{main_8c_a840291bc02cba5474a4cb46a9b9566fe} 
\index{main.c@{main.c}!main@{main}}
\index{main@{main}!main.c@{main.c}}
\doxysubsubsection{\texorpdfstring{main()}{main()}}
{\footnotesize\ttfamily int main (\begin{DoxyParamCaption}\item[{void}]{ }\end{DoxyParamCaption})}

Init all GPIO and drivers, start the task, init semaphore and queue and launch the kernel
\begin{DoxyItemize}
\item Config EXSTARTUP
\begin{DoxyItemize}
\item Launch micro\+Ros, supervision, left motor, right motor and lcd task
\end{DoxyItemize}
\item Config EXTEST\+\_\+\+UART2
\begin{DoxyItemize}
\item Launch test\+\_\+uart2 task
\end{DoxyItemize}
\item Config EXCORRECTOR
\begin{DoxyItemize}
\item Launch test\+\_\+motor task
\end{DoxyItemize}
\item Config EXTESTCORRECTOR
\begin{DoxyItemize}
\item Launch supervision, left motor and right motor task
\end{DoxyItemize}
\item Config EXTEST\+\_\+\+VL53
\begin{DoxyItemize}
\item Launch test\+\_\+vl53 task
\end{DoxyItemize}
\item Config EXTEST\+\_\+\+MICROROS
\begin{DoxyItemize}
\item Launch micro\+Ros task
\end{DoxyItemize}
\item Config EXFINAL
\begin{DoxyItemize}
\item Launch micro\+Ros, supervision, left motor, right motor, vl53 and lcd task 
\end{DoxyItemize}
\end{DoxyItemize}

Definition at line \mbox{\hyperlink{main_8c_source_l00752}{752}} of file \mbox{\hyperlink{main_8c_source}{main.\+c}}.

\Hypertarget{main_8c_afbbd07004ef2541918f88b67c4af7a71}\label{main_8c_afbbd07004ef2541918f88b67c4af7a71} 
\index{main.c@{main.c}!microros\_allocate@{microros\_allocate}}
\index{microros\_allocate@{microros\_allocate}!main.c@{main.c}}
\doxysubsubsection{\texorpdfstring{microros\_allocate()}{microros\_allocate()}}
{\footnotesize\ttfamily void \texorpdfstring{$\ast$}{*} microros\+\_\+allocate (\begin{DoxyParamCaption}\item[{size\+\_\+t}]{size,  }\item[{void \texorpdfstring{$\ast$}{*}}]{state }\end{DoxyParamCaption})}

Definition at line \mbox{\hyperlink{microros__allocators_8c_source_l00014}{14}} of file \mbox{\hyperlink{microros__allocators_8c_source}{microros\+\_\+allocators.\+c}}.

\Hypertarget{main_8c_aba9c00b570a317fad6f6d30220fada5b}\label{main_8c_aba9c00b570a317fad6f6d30220fada5b} 
\index{main.c@{main.c}!microros\_deallocate@{microros\_deallocate}}
\index{microros\_deallocate@{microros\_deallocate}!main.c@{main.c}}
\doxysubsubsection{\texorpdfstring{microros\_deallocate()}{microros\_deallocate()}}
{\footnotesize\ttfamily void microros\+\_\+deallocate (\begin{DoxyParamCaption}\item[{void \texorpdfstring{$\ast$}{*}}]{pointer,  }\item[{void \texorpdfstring{$\ast$}{*}}]{state }\end{DoxyParamCaption})}

Definition at line \mbox{\hyperlink{microros__allocators_8c_source_l00022}{22}} of file \mbox{\hyperlink{microros__allocators_8c_source}{microros\+\_\+allocators.\+c}}.

\Hypertarget{main_8c_a3850b59e26ba636e5111bde82afafb01}\label{main_8c_a3850b59e26ba636e5111bde82afafb01} 
\index{main.c@{main.c}!microros\_reallocate@{microros\_reallocate}}
\index{microros\_reallocate@{microros\_reallocate}!main.c@{main.c}}
\doxysubsubsection{\texorpdfstring{microros\_reallocate()}{microros\_reallocate()}}
{\footnotesize\ttfamily void \texorpdfstring{$\ast$}{*} microros\+\_\+reallocate (\begin{DoxyParamCaption}\item[{void \texorpdfstring{$\ast$}{*}}]{pointer,  }\item[{size\+\_\+t}]{size,  }\item[{void \texorpdfstring{$\ast$}{*}}]{state }\end{DoxyParamCaption})}

Definition at line \mbox{\hyperlink{microros__allocators_8c_source_l00031}{31}} of file \mbox{\hyperlink{microros__allocators_8c_source}{microros\+\_\+allocators.\+c}}.

\Hypertarget{main_8c_a5aca40d972a3057895d59e61e0e69678}\label{main_8c_a5aca40d972a3057895d59e61e0e69678} 
\index{main.c@{main.c}!microros\_task@{microros\_task}}
\index{microros\_task@{microros\_task}!main.c@{main.c}}
\doxysubsubsection{\texorpdfstring{microros\_task()}{microros\_task()}}
{\footnotesize\ttfamily void microros\+\_\+task (\begin{DoxyParamCaption}\item[{void \texorpdfstring{$\ast$}{*}}]{argument }\end{DoxyParamCaption})}

\begin{DoxyItemize}
\item All config
\begin{DoxyItemize}
\item Create the node {\itshape STM32\+\_\+node} 
\item Set the Domain id of micro\+Ros
\end{DoxyItemize}
\item Config EXSTARTUP \+:
\begin{DoxyItemize}
\item Create a publisher and send a message on it
\end{DoxyItemize}
\item Config EXTEST\+\_\+\+MICROROS \+:
\begin{DoxyItemize}
\item Create a publisher, a subscriber and an executor
\item Init the executor and add the subscriber to it
\item Run the executor and send the receive message on the publisher
\end{DoxyItemize}
\item Config EXFINAL \+:
\begin{DoxyItemize}
\item Create 3 publishers, 5 subscriber and an executor
\item Init the executor and add the 5 subscribers to it
\item run the executor and if they are no elements waiting to be read by the task decision put the receive information in the queue If decison task send data then publish data to micro\+Ros 
\begin{DoxyParams}{Parameters}
{\em argument} & \\
\hline
\end{DoxyParams}

\end{DoxyItemize}
\end{DoxyItemize}

Definition at line \mbox{\hyperlink{main_8c_source_l00168}{168}} of file \mbox{\hyperlink{main_8c_source}{main.\+c}}.

\Hypertarget{main_8c_a74ab553464987a94faae5e414df0078a}\label{main_8c_a74ab553464987a94faae5e414df0078a} 
\index{main.c@{main.c}!microros\_zero\_allocate@{microros\_zero\_allocate}}
\index{microros\_zero\_allocate@{microros\_zero\_allocate}!main.c@{main.c}}
\doxysubsubsection{\texorpdfstring{microros\_zero\_allocate()}{microros\_zero\_allocate()}}
{\footnotesize\ttfamily void \texorpdfstring{$\ast$}{*} microros\+\_\+zero\+\_\+allocate (\begin{DoxyParamCaption}\item[{size\+\_\+t}]{number\+\_\+of\+\_\+elements,  }\item[{size\+\_\+t}]{size\+\_\+of\+\_\+element,  }\item[{void \texorpdfstring{$\ast$}{*}}]{state }\end{DoxyParamCaption})}

Definition at line \mbox{\hyperlink{microros__allocators_8c_source_l00044}{44}} of file \mbox{\hyperlink{microros__allocators_8c_source}{microros\+\_\+allocators.\+c}}.

\Hypertarget{main_8c_afec8e194407d73381e7dfda42910309d}\label{main_8c_afec8e194407d73381e7dfda42910309d} 
\index{main.c@{main.c}!SubscriberCallbackFunction@{SubscriberCallbackFunction}}
\index{SubscriberCallbackFunction@{SubscriberCallbackFunction}!main.c@{main.c}}
\doxysubsubsection{\texorpdfstring{SubscriberCallbackFunction()}{SubscriberCallbackFunction()}}
{\footnotesize\ttfamily void Subscriber\+Callback\+Function (\begin{DoxyParamCaption}\item[{const void \texorpdfstring{$\ast$}{*}}]{msgin }\end{DoxyParamCaption})}

callback call by microros when a message is receive here use as debug and just print the receive msg 
\begin{DoxyParams}{Parameters}
{\em message} & receive \\
\hline
\end{DoxyParams}

Definition at line \mbox{\hyperlink{main_8c_source_l00156}{156}} of file \mbox{\hyperlink{main_8c_source}{main.\+c}}.

\Hypertarget{main_8c_a70af21c671abfcc773614a9a4f63d920}\label{main_8c_a70af21c671abfcc773614a9a4f63d920} 
\index{main.c@{main.c}!SystemClock\_Config@{SystemClock\_Config}}
\index{SystemClock\_Config@{SystemClock\_Config}!main.c@{main.c}}
\doxysubsubsection{\texorpdfstring{SystemClock\_Config()}{SystemClock\_Config()}}
{\footnotesize\ttfamily void System\+Clock\+\_\+\+Config (\begin{DoxyParamCaption}\item[{void}]{ }\end{DoxyParamCaption})}

Configure the main internal regulator output voltage

Initializes the RCC Oscillators according to the specified parameters in the RCC\+\_\+\+Osc\+Init\+Type\+Def structure.

Initializes the CPU, AHB and APB buses clocks

Definition at line \mbox{\hyperlink{systemclock_8c_source_l00011}{11}} of file \mbox{\hyperlink{systemclock_8c_source}{systemclock.\+c}}.

\Hypertarget{main_8c_a0437f457b0f155ea2e19c99e841144f4}\label{main_8c_a0437f457b0f155ea2e19c99e841144f4} 
\index{main.c@{main.c}!task\_Grove\_LCD@{task\_Grove\_LCD}}
\index{task\_Grove\_LCD@{task\_Grove\_LCD}!main.c@{main.c}}
\doxysubsubsection{\texorpdfstring{task\_Grove\_LCD()}{task\_Grove\_LCD()}}
{\footnotesize\ttfamily void task\+\_\+\+Grove\+\_\+\+LCD (\begin{DoxyParamCaption}\item[{void \texorpdfstring{$\ast$}{*}}]{pv\+Parameters }\end{DoxyParamCaption})}

Task use to write information on LCD depending of the data in the LCD queue
\begin{DoxyItemize}
\item Config EXSTARTUP \+:
\begin{DoxyItemize}
\item Print \textquotesingle{}TEST\textquotesingle{} LCD on screen
\end{DoxyItemize}
\item Config EXFINAL \+:
\begin{DoxyItemize}
\item Print different messages depending of the actual mode 
\begin{DoxyParams}{Parameters}
{\em argument} & \\
\hline
\end{DoxyParams}

\end{DoxyItemize}
\end{DoxyItemize}

Definition at line \mbox{\hyperlink{main_8c_source_l00463}{463}} of file \mbox{\hyperlink{main_8c_source}{main.\+c}}.

\Hypertarget{main_8c_aeaf40c2ad14431735bdc8432bf5e57de}\label{main_8c_aeaf40c2ad14431735bdc8432bf5e57de} 
\index{main.c@{main.c}!task\_Motor\_Left@{task\_Motor\_Left}}
\index{task\_Motor\_Left@{task\_Motor\_Left}!main.c@{main.c}}
\doxysubsubsection{\texorpdfstring{task\_Motor\_Left()}{task\_Motor\_Left()}}
{\footnotesize\ttfamily void task\+\_\+\+Motor\+\_\+\+Left (\begin{DoxyParamCaption}\item[{void \texorpdfstring{$\ast$}{*}}]{pv\+Parameters }\end{DoxyParamCaption})}

Task use to control the left motor of the robot 
\begin{DoxyParams}{Parameters}
{\em argument} & \\
\hline
\end{DoxyParams}

Definition at line \mbox{\hyperlink{main_8c_source_l00385}{385}} of file \mbox{\hyperlink{main_8c_source}{main.\+c}}.

\Hypertarget{main_8c_a81f652726bff3b9832ab014d3fc28d1e}\label{main_8c_a81f652726bff3b9832ab014d3fc28d1e} 
\index{main.c@{main.c}!task\_Motor\_Right@{task\_Motor\_Right}}
\index{task\_Motor\_Right@{task\_Motor\_Right}!main.c@{main.c}}
\doxysubsubsection{\texorpdfstring{task\_Motor\_Right()}{task\_Motor\_Right()}}
{\footnotesize\ttfamily void task\+\_\+\+Motor\+\_\+\+Right (\begin{DoxyParamCaption}\item[{void \texorpdfstring{$\ast$}{*}}]{pv\+Parameters }\end{DoxyParamCaption})}

Task use to control the right motor of the robot 
\begin{DoxyParams}{Parameters}
{\em argument} & \\
\hline
\end{DoxyParams}

Definition at line \mbox{\hyperlink{main_8c_source_l00411}{411}} of file \mbox{\hyperlink{main_8c_source}{main.\+c}}.

\Hypertarget{main_8c_aa20650615a802a253757e491905b6af9}\label{main_8c_aa20650615a802a253757e491905b6af9} 
\index{main.c@{main.c}!task\_Supervision@{task\_Supervision}}
\index{task\_Supervision@{task\_Supervision}!main.c@{main.c}}
\doxysubsubsection{\texorpdfstring{task\_Supervision()}{task\_Supervision()}}
{\footnotesize\ttfamily void task\+\_\+\+Supervision (\begin{DoxyParamCaption}\item[{void \texorpdfstring{$\ast$}{*}}]{pv\+Parameters }\end{DoxyParamCaption})}

Brain of the robot. get information for Micro\+Ros and VL53 task, then send speed to left and right motor, lcd and micro\+Ros task
\begin{DoxyItemize}
\item Config EXSTARTUP \+:
\begin{DoxyItemize}
\item Make the robot drive forward until an obstacle are found
\end{DoxyItemize}
\item Config EXTESTCORRECTOR \+:
\begin{DoxyItemize}
\item Make the robot drive forward at speed set by config
\end{DoxyItemize}
\item Config EXFINAL \+:
\begin{DoxyItemize}
\item Make robot switch beetween 3 behaviour depending of the mode
\item Obstacle \+: drive and avoid obstacles
\item Manual \+: drive in direction set in ihm
\item Camera \+: follow an object 
\begin{DoxyParams}{Parameters}
{\em argument} & \\
\hline
\end{DoxyParams}

\end{DoxyItemize}
\end{DoxyItemize}

Definition at line \mbox{\hyperlink{main_8c_source_l00498}{498}} of file \mbox{\hyperlink{main_8c_source}{main.\+c}}.

\Hypertarget{main_8c_a0770d7007222fbff5f97c3ea3b3cbb5c}\label{main_8c_a0770d7007222fbff5f97c3ea3b3cbb5c} 
\index{main.c@{main.c}!task\_VL53@{task\_VL53}}
\index{task\_VL53@{task\_VL53}!main.c@{main.c}}
\doxysubsubsection{\texorpdfstring{task\_VL53()}{task\_VL53()}}
{\footnotesize\ttfamily void task\+\_\+\+VL53 (\begin{DoxyParamCaption}\item[{void \texorpdfstring{$\ast$}{*}}]{pv\+Parameters }\end{DoxyParamCaption})}

task that get the value of the VL53 sensor and put it on the VL53 queue 
\begin{DoxyParams}{Parameters}
{\em argument} & \\
\hline
\end{DoxyParams}

Definition at line \mbox{\hyperlink{main_8c_source_l00438}{438}} of file \mbox{\hyperlink{main_8c_source}{main.\+c}}.

\Hypertarget{main_8c_aac27f033a986ce7ecadc6f9532aa8c3a}\label{main_8c_aac27f033a986ce7ecadc6f9532aa8c3a} 
\index{main.c@{main.c}!test\_motor@{test\_motor}}
\index{test\_motor@{test\_motor}!main.c@{main.c}}
\doxysubsubsection{\texorpdfstring{test\_motor()}{test\_motor()}}
{\footnotesize\ttfamily void test\+\_\+motor (\begin{DoxyParamCaption}\item[{void \texorpdfstring{$\ast$}{*}}]{pv\+Parameters }\end{DoxyParamCaption})}

Use to set the duty cycle and register the motor speed at each Te 

Definition at line \mbox{\hyperlink{main_8c_source_l00868}{868}} of file \mbox{\hyperlink{main_8c_source}{main.\+c}}.

\Hypertarget{main_8c_a0068220a4432a5ea9b4442d018b706f8}\label{main_8c_a0068220a4432a5ea9b4442d018b706f8} 
\index{main.c@{main.c}!test\_uart2@{test\_uart2}}
\index{test\_uart2@{test\_uart2}!main.c@{main.c}}
\doxysubsubsection{\texorpdfstring{test\_uart2()}{test\_uart2()}}
{\footnotesize\ttfamily void test\+\_\+uart2 (\begin{DoxyParamCaption}\item[{void \texorpdfstring{$\ast$}{*}}]{pv\+Parameters }\end{DoxyParamCaption})}

Use to test printf and scanf function 

Definition at line \mbox{\hyperlink{main_8c_source_l00845}{845}} of file \mbox{\hyperlink{main_8c_source}{main.\+c}}.

\Hypertarget{main_8c_a03356c29f7343d5cd605bcd3e80e27e0}\label{main_8c_a03356c29f7343d5cd605bcd3e80e27e0} 
\index{main.c@{main.c}!test\_vl53@{test\_vl53}}
\index{test\_vl53@{test\_vl53}!main.c@{main.c}}
\doxysubsubsection{\texorpdfstring{test\_vl53()}{test\_vl53()}}
{\footnotesize\ttfamily void test\+\_\+vl53 (\begin{DoxyParamCaption}\item[{void \texorpdfstring{$\ast$}{*}}]{pv\+Parameters }\end{DoxyParamCaption})}

Use to test the VL53 sensor 

Definition at line \mbox{\hyperlink{main_8c_source_l00857}{857}} of file \mbox{\hyperlink{main_8c_source}{main.\+c}}.

\doxysubsection{Variable Documentation}
\Hypertarget{main_8c_a25fbb54afdba71c24ba51ed50166ac8d}\label{main_8c_a25fbb54afdba71c24ba51ed50166ac8d} 
\index{main.c@{main.c}!defaultTask\_attributes@{defaultTask\_attributes}}
\index{defaultTask\_attributes@{defaultTask\_attributes}!main.c@{main.c}}
\doxysubsubsection{\texorpdfstring{defaultTask\_attributes}{defaultTask\_attributes}}
{\footnotesize\ttfamily const os\+Thread\+Attr\+\_\+t default\+Task\+\_\+attributes}

{\bfseries Initial value\+:}
\begin{DoxyCode}{0}
\DoxyCodeLine{=\ \{}
\DoxyCodeLine{\ \ .name\ =\ \textcolor{stringliteral}{"{}defaultTask"{}},}
\DoxyCodeLine{\ \ .stack\_size\ =\ 3000\ *\ 4,}
\DoxyCodeLine{\ \ .priority\ =\ (osPriority\_t)\ osPriorityNormal,}
\DoxyCodeLine{\}}

\end{DoxyCode}

Definition at line \mbox{\hyperlink{main_8c_source_l00024}{24}} of file \mbox{\hyperlink{main_8c_source}{main.\+c}}.

\Hypertarget{main_8c_a6a263905468b0c37de4ee5e50ede4e74}\label{main_8c_a6a263905468b0c37de4ee5e50ede4e74} 
\index{main.c@{main.c}!defaultTaskHandle@{defaultTaskHandle}}
\index{defaultTaskHandle@{defaultTaskHandle}!main.c@{main.c}}
\doxysubsubsection{\texorpdfstring{defaultTaskHandle}{defaultTaskHandle}}
{\footnotesize\ttfamily os\+Thread\+Id\+\_\+t default\+Task\+Handle}

Definition at line \mbox{\hyperlink{main_8c_source_l00023}{23}} of file \mbox{\hyperlink{main_8c_source}{main.\+c}}.

\Hypertarget{main_8c_a34251392f0d5e2461e3aef615918c235}\label{main_8c_a34251392f0d5e2461e3aef615918c235} 
\index{main.c@{main.c}!hdma\_usart1\_rx@{hdma\_usart1\_rx}}
\index{hdma\_usart1\_rx@{hdma\_usart1\_rx}!main.c@{main.c}}
\doxysubsubsection{\texorpdfstring{hdma\_usart1\_rx}{hdma\_usart1\_rx}}
{\footnotesize\ttfamily DMA\+\_\+\+Handle\+Type\+Def hdma\+\_\+usart1\+\_\+rx\hspace{0.3cm}{\ttfamily [extern]}}

Definition at line \mbox{\hyperlink{drv__uart_8c_source_l00006}{6}} of file \mbox{\hyperlink{drv__uart_8c_source}{drv\+\_\+uart.\+c}}.

\Hypertarget{main_8c_a5af94ab36bfe698db3e6beea96d10a90}\label{main_8c_a5af94ab36bfe698db3e6beea96d10a90} 
\index{main.c@{main.c}!hdma\_usart1\_tx@{hdma\_usart1\_tx}}
\index{hdma\_usart1\_tx@{hdma\_usart1\_tx}!main.c@{main.c}}
\doxysubsubsection{\texorpdfstring{hdma\_usart1\_tx}{hdma\_usart1\_tx}}
{\footnotesize\ttfamily DMA\+\_\+\+Handle\+Type\+Def hdma\+\_\+usart1\+\_\+tx\hspace{0.3cm}{\ttfamily [extern]}}

Definition at line \mbox{\hyperlink{drv__uart_8c_source_l00007}{7}} of file \mbox{\hyperlink{drv__uart_8c_source}{drv\+\_\+uart.\+c}}.

\Hypertarget{main_8c_a784aa25dc7e4580cfbf80658340f482c}\label{main_8c_a784aa25dc7e4580cfbf80658340f482c} 
\index{main.c@{main.c}!hdma\_usart2\_rx@{hdma\_usart2\_rx}}
\index{hdma\_usart2\_rx@{hdma\_usart2\_rx}!main.c@{main.c}}
\doxysubsubsection{\texorpdfstring{hdma\_usart2\_rx}{hdma\_usart2\_rx}}
{\footnotesize\ttfamily DMA\+\_\+\+Handle\+Type\+Def hdma\+\_\+usart2\+\_\+rx\hspace{0.3cm}{\ttfamily [extern]}}

Definition at line \mbox{\hyperlink{drv__uart_8c_source_l00008}{8}} of file \mbox{\hyperlink{drv__uart_8c_source}{drv\+\_\+uart.\+c}}.

\Hypertarget{main_8c_a0083b476c2a75ab9fb2ccbed0048857e}\label{main_8c_a0083b476c2a75ab9fb2ccbed0048857e} 
\index{main.c@{main.c}!hdma\_usart2\_tx@{hdma\_usart2\_tx}}
\index{hdma\_usart2\_tx@{hdma\_usart2\_tx}!main.c@{main.c}}
\doxysubsubsection{\texorpdfstring{hdma\_usart2\_tx}{hdma\_usart2\_tx}}
{\footnotesize\ttfamily DMA\+\_\+\+Handle\+Type\+Def hdma\+\_\+usart2\+\_\+tx\hspace{0.3cm}{\ttfamily [extern]}}

Definition at line \mbox{\hyperlink{drv__uart_8c_source_l00009}{9}} of file \mbox{\hyperlink{drv__uart_8c_source}{drv\+\_\+uart.\+c}}.

\Hypertarget{main_8c_af7b2c26e44dadaaa798a5c3d82914ba7}\label{main_8c_af7b2c26e44dadaaa798a5c3d82914ba7} 
\index{main.c@{main.c}!hi2c1@{hi2c1}}
\index{hi2c1@{hi2c1}!main.c@{main.c}}
\doxysubsubsection{\texorpdfstring{hi2c1}{hi2c1}}
{\footnotesize\ttfamily I2\+C\+\_\+\+Handle\+Type\+Def hi2c1\hspace{0.3cm}{\ttfamily [extern]}}

Definition at line \mbox{\hyperlink{drv__i2c_8c_source_l00006}{6}} of file \mbox{\hyperlink{drv__i2c_8c_source}{drv\+\_\+i2c.\+c}}.

\Hypertarget{main_8c_a2cf715bef37f7e8ef385a30974a5f0d5}\label{main_8c_a2cf715bef37f7e8ef385a30974a5f0d5} 
\index{main.c@{main.c}!huart1@{huart1}}
\index{huart1@{huart1}!main.c@{main.c}}
\doxysubsubsection{\texorpdfstring{huart1}{huart1}}
{\footnotesize\ttfamily UART\+\_\+\+Handle\+Type\+Def huart1\hspace{0.3cm}{\ttfamily [extern]}}

Definition at line \mbox{\hyperlink{drv__uart_8c_source_l00004}{4}} of file \mbox{\hyperlink{drv__uart_8c_source}{drv\+\_\+uart.\+c}}.

\Hypertarget{main_8c_aa9479c261d65eecedd3d9582f7f0f89c}\label{main_8c_aa9479c261d65eecedd3d9582f7f0f89c} 
\index{main.c@{main.c}!huart2@{huart2}}
\index{huart2@{huart2}!main.c@{main.c}}
\doxysubsubsection{\texorpdfstring{huart2}{huart2}}
{\footnotesize\ttfamily UART\+\_\+\+Handle\+Type\+Def huart2\hspace{0.3cm}{\ttfamily [extern]}}

Definition at line \mbox{\hyperlink{drv__uart_8c_source_l00005}{5}} of file \mbox{\hyperlink{drv__uart_8c_source}{drv\+\_\+uart.\+c}}.

\Hypertarget{main_8c_a938902e735d5df04bf790f601801da8e}\label{main_8c_a938902e735d5df04bf790f601801da8e} 
\index{main.c@{main.c}!q\_mot\_L@{q\_mot\_L}}
\index{q\_mot\_L@{q\_mot\_L}!main.c@{main.c}}
\doxysubsubsection{\texorpdfstring{q\_mot\_L}{q\_mot\_L}}
{\footnotesize\ttfamily x\+Queue\+Handle q\+\_\+mot\+\_\+L = NULL}

Queue to communicate with left motor task 

Definition at line \mbox{\hyperlink{main_8c_source_l00097}{97}} of file \mbox{\hyperlink{main_8c_source}{main.\+c}}.

\Hypertarget{main_8c_aa26ca3e16f249f82045250c09e1cd053}\label{main_8c_aa26ca3e16f249f82045250c09e1cd053} 
\index{main.c@{main.c}!q\_mot\_R@{q\_mot\_R}}
\index{q\_mot\_R@{q\_mot\_R}!main.c@{main.c}}
\doxysubsubsection{\texorpdfstring{q\_mot\_R}{q\_mot\_R}}
{\footnotesize\ttfamily x\+Queue\+Handle q\+\_\+mot\+\_\+R = NULL}

Queue to communicate with right motor task 

Definition at line \mbox{\hyperlink{main_8c_source_l00098}{98}} of file \mbox{\hyperlink{main_8c_source}{main.\+c}}.

\Hypertarget{main_8c_a494090d44b64e4d33b49a38031ede042}\label{main_8c_a494090d44b64e4d33b49a38031ede042} 
\index{main.c@{main.c}!qhLCD@{qhLCD}}
\index{qhLCD@{qhLCD}!main.c@{main.c}}
\doxysubsubsection{\texorpdfstring{qhLCD}{qhLCD}}
{\footnotesize\ttfamily x\+Queue\+Handle qh\+LCD = NULL}

Queue to communicate with LCD task 

Definition at line \mbox{\hyperlink{main_8c_source_l00101}{101}} of file \mbox{\hyperlink{main_8c_source}{main.\+c}}.

\Hypertarget{main_8c_a2ec1e708e81871b5c6929cb901a69c51}\label{main_8c_a2ec1e708e81871b5c6929cb901a69c51} 
\index{main.c@{main.c}!qhMR\_pub@{qhMR\_pub}}
\index{qhMR\_pub@{qhMR\_pub}!main.c@{main.c}}
\doxysubsubsection{\texorpdfstring{qhMR\_pub}{qhMR\_pub}}
{\footnotesize\ttfamily x\+Queue\+Handle qh\+MR\+\_\+pub = NULL}

Queue to communicate with micro\+Ros task 

Definition at line \mbox{\hyperlink{main_8c_source_l00100}{100}} of file \mbox{\hyperlink{main_8c_source}{main.\+c}}.

\Hypertarget{main_8c_a2313a36ccf1c497c3b1595ad8f7a266a}\label{main_8c_a2313a36ccf1c497c3b1595ad8f7a266a} 
\index{main.c@{main.c}!qhMR\_sub@{qhMR\_sub}}
\index{qhMR\_sub@{qhMR\_sub}!main.c@{main.c}}
\doxysubsubsection{\texorpdfstring{qhMR\_sub}{qhMR\_sub}}
{\footnotesize\ttfamily x\+Queue\+Handle qh\+MR\+\_\+sub = NULL}

Queue to get information from micro\+Ros task 

Definition at line \mbox{\hyperlink{main_8c_source_l00099}{99}} of file \mbox{\hyperlink{main_8c_source}{main.\+c}}.

\Hypertarget{main_8c_a3350c1d692cc188bf1b42c2a3810b9d1}\label{main_8c_a3350c1d692cc188bf1b42c2a3810b9d1} 
\index{main.c@{main.c}!qhVl53@{qhVl53}}
\index{qhVl53@{qhVl53}!main.c@{main.c}}
\doxysubsubsection{\texorpdfstring{qhVl53}{qhVl53}}
{\footnotesize\ttfamily x\+Queue\+Handle qh\+Vl53 = NULL}

Queue to communicate with VL53 task 

Definition at line \mbox{\hyperlink{main_8c_source_l00102}{102}} of file \mbox{\hyperlink{main_8c_source}{main.\+c}}.

\Hypertarget{main_8c_a377891cff46d2f0a39f956b917366f95}\label{main_8c_a377891cff46d2f0a39f956b917366f95} 
\index{main.c@{main.c}!tab\_speed@{tab\_speed}}
\index{tab\_speed@{tab\_speed}!main.c@{main.c}}
\doxysubsubsection{\texorpdfstring{tab\_speed}{tab\_speed}}
{\footnotesize\ttfamily int16\+\_\+t tab\+\_\+speed\mbox{[}\mbox{\hyperlink{main_8c_a58e95dc1eb9d6ce16f515e77beeadd58}{NB}}\mbox{]}}

use to store speed of motor during calibration of the correcteur 

Definition at line \mbox{\hyperlink{main_8c_source_l00105}{105}} of file \mbox{\hyperlink{main_8c_source}{main.\+c}}.

\Hypertarget{main_8c_a8c732ee84a40140fe90e1edb5e3fe61a}\label{main_8c_a8c732ee84a40140fe90e1edb5e3fe61a} 
\index{main.c@{main.c}!xSem\_Supervision@{xSem\_Supervision}}
\index{xSem\_Supervision@{xSem\_Supervision}!main.c@{main.c}}
\doxysubsubsection{\texorpdfstring{xSem\_Supervision}{xSem\_Supervision}}
{\footnotesize\ttfamily x\+Semaphore\+Handle x\+Sem\+\_\+\+Supervision = NULL}

Semaphore use in decision task 

Definition at line \mbox{\hyperlink{main_8c_source_l00094}{94}} of file \mbox{\hyperlink{main_8c_source}{main.\+c}}.

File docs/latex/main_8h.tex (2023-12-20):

\doxysection{C\+:/\+Users/\+Administrator/\+Documents/\+Git\+Hub/\+ENIB\+\_\+\+Robot\+\_\+\+Mobile\+\_\+\+Ros2/final\+Code/\+WORKSPACE\+\_\+\+F411\+\_\+u\+ROS/base\+\_\+robot/\+Core/\+Inc/main.h File Reference}
\hypertarget{main_8h}{}\label{main_8h}\index{C:/Users/Administrator/Documents/GitHub/ENIB\_Robot\_Mobile\_Ros2/finalCode/WORKSPACE\_F411\_uROS/base\_robot/Core/Inc/main.h@{C:/Users/Administrator/Documents/GitHub/ENIB\_Robot\_Mobile\_Ros2/finalCode/WORKSPACE\_F411\_uROS/base\_robot/Core/Inc/main.h}}

\+: Header for \doxylink{main_8c}{main.\+c} file. This file contains the common defines of the application.  

{\ttfamily \#include "{}stm32f4xx\+\_\+hal.\+h"{}}\newline
{\ttfamily \#include $<$stdio.\+h$>$}\newline
{\ttfamily \#include $<$rcl/rcl.\+h$>$}\newline
{\ttfamily \#include $<$rcl/error\+\_\+handling.\+h$>$}\newline
{\ttfamily \#include $<$rclc/rclc.\+h$>$}\newline
{\ttfamily \#include $<$rclc/executor.\+h$>$}\newline
{\ttfamily \#include $<$uxr/client/transport.\+h$>$}\newline
{\ttfamily \#include $<$rmw\+\_\+microxrcedds\+\_\+c/config.\+h$>$}\newline
{\ttfamily \#include $<$rmw\+\_\+microros/rmw\+\_\+microros.\+h$>$}\newline
{\ttfamily \#include $<$std\+\_\+msgs/msg/int32.\+h$>$}\newline
{\ttfamily \#include $<$std\+\_\+msgs/msg/string.\+h$>$}\newline
{\ttfamily \#include $<$std\+\_\+msgs/msg/header.\+h$>$}\newline
{\ttfamily \#include "{}Free\+RTOS.\+h"{}}\newline
{\ttfamily \#include "{}task.\+h"{}}\newline
{\ttfamily \#include "{}queue.\+h"{}}\newline
{\ttfamily \#include "{}semphr.\+h"{}}\newline
{\ttfamily \#include "{}systemclock.\+h"{}}\newline
{\ttfamily \#include "{}drv\+\_\+uart.\+h"{}}\newline
{\ttfamily \#include "{}drv\+\_\+gpio.\+h"{}}\newline
{\ttfamily \#include "{}drv\+\_\+i2c.\+h"{}}\newline
{\ttfamily \#include "{}cmsis\+\_\+os.\+h"{}}\newline
{\ttfamily \#include "{}micro\+ROS.\+h"{}}\newline
{\ttfamily \#include "{}retarget.\+h"{}}\newline
\doxysubsubsection*{Macros}
\begin{DoxyCompactItemize}
\item 
\#define \mbox{\hyperlink{main_8h_a31ac298fbbc8a1d6de1dc4577a108232}{B1\+\_\+\+Pin}}~GPIO\+\_\+\+PIN\+\_\+13
\item 
\#define \mbox{\hyperlink{main_8h_a4926b92dcb220e465850d9616c27e171}{B1\+\_\+\+GPIO\+\_\+\+Port}}~GPIOC
\item 
\#define \mbox{\hyperlink{main_8h_a5644600bf1ed996688dd87dc3f88526c}{USART\+\_\+\+TX\+\_\+\+Pin}}~GPIO\+\_\+\+PIN\+\_\+2
\item 
\#define \mbox{\hyperlink{main_8h_a79a3e098f5d738c55a12e4272b7b2f84}{USART\+\_\+\+TX\+\_\+\+GPIO\+\_\+\+Port}}~GPIOA
\item 
\#define \mbox{\hyperlink{main_8h_ac93b92f1334823df872908c845c71afc}{USART\+\_\+\+RX\+\_\+\+Pin}}~GPIO\+\_\+\+PIN\+\_\+3
\item 
\#define \mbox{\hyperlink{main_8h_aae451289f2eda1c04e3bf6d6120b6c0b}{USART\+\_\+\+RX\+\_\+\+GPIO\+\_\+\+Port}}~GPIOA
\item 
\#define \mbox{\hyperlink{main_8h_af17a94dd613cff35c699b06c7c6a2820}{LD2\+\_\+\+Pin}}~GPIO\+\_\+\+PIN\+\_\+5
\item 
\#define \mbox{\hyperlink{main_8h_a5aff6ddf7fe557e53b048115ad322aa0}{LD2\+\_\+\+GPIO\+\_\+\+Port}}~GPIOA
\item 
\#define \mbox{\hyperlink{main_8h_af2c8a7a0746106e52f6f415b8921c21b}{TMS\+\_\+\+Pin}}~GPIO\+\_\+\+PIN\+\_\+13
\item 
\#define \mbox{\hyperlink{main_8h_affce477a22cc940d3962932cb33ec422}{TMS\+\_\+\+GPIO\+\_\+\+Port}}~GPIOA
\item 
\#define \mbox{\hyperlink{main_8h_a9e21d9bed16b0275ff16a864ffb2ab6e}{TCK\+\_\+\+Pin}}~GPIO\+\_\+\+PIN\+\_\+14
\item 
\#define \mbox{\hyperlink{main_8h_a1541f23b870848a43f0274857badd175}{TCK\+\_\+\+GPIO\+\_\+\+Port}}~GPIOA
\item 
\#define \mbox{\hyperlink{main_8h_a92aba89301afeefb00b6dfbc6e874027}{SWO\+\_\+\+Pin}}~GPIO\+\_\+\+PIN\+\_\+3
\item 
\#define \mbox{\hyperlink{main_8h_a1540b1bd5614d42feb933c5b943263c0}{SWO\+\_\+\+GPIO\+\_\+\+Port}}~GPIOB
\end{DoxyCompactItemize}
\doxysubsubsection*{Functions}
\begin{DoxyCompactItemize}
\item 
void \mbox{\hyperlink{main_8h_a1730ffe1e560465665eb47d9264826f9}{Error\+\_\+\+Handler}} (void)
\item 
void \mbox{\hyperlink{main_8h_a3f82047e1c93bff73e4db97a19f6ad2e}{CHECKMRRET}} (rcl\+\_\+ret\+\_\+t ret, char \texorpdfstring{$\ast$}{*}msg)
\item 
void \mbox{\hyperlink{main_8h_afec8e194407d73381e7dfda42910309d}{Subscriber\+Callback\+Function}} (const void \texorpdfstring{$\ast$}{*}msgin)
\item 
void \mbox{\hyperlink{main_8h_a5aca40d972a3057895d59e61e0e69678}{microros\+\_\+task}} (void \texorpdfstring{$\ast$}{*}argument)
\item 
void \mbox{\hyperlink{main_8h_aeaf40c2ad14431735bdc8432bf5e57de}{task\+\_\+\+Motor\+\_\+\+Left}} (void \texorpdfstring{$\ast$}{*}pv\+Parameters)
\item 
void \mbox{\hyperlink{main_8h_a81f652726bff3b9832ab014d3fc28d1e}{task\+\_\+\+Motor\+\_\+\+Right}} (void \texorpdfstring{$\ast$}{*}pv\+Parameters)
\item 
void \mbox{\hyperlink{main_8h_a0770d7007222fbff5f97c3ea3b3cbb5c}{task\+\_\+\+VL53}} (void \texorpdfstring{$\ast$}{*}pv\+Parameters)
\item 
void \mbox{\hyperlink{main_8h_a0437f457b0f155ea2e19c99e841144f4}{task\+\_\+\+Grove\+\_\+\+LCD}} (void \texorpdfstring{$\ast$}{*}pv\+Parameters)
\item 
void \mbox{\hyperlink{main_8h_aa20650615a802a253757e491905b6af9}{task\+\_\+\+Supervision}} (void \texorpdfstring{$\ast$}{*}pv\+Parameters)
\item 
int \mbox{\hyperlink{main_8h_a840291bc02cba5474a4cb46a9b9566fe}{main}} (void)
\end{DoxyCompactItemize}
\begin{Indent}\textbf{ Test function}\par
\begin{DoxyCompactItemize}
\item 
void \mbox{\hyperlink{main_8h_a0068220a4432a5ea9b4442d018b706f8}{test\+\_\+uart2}} (void \texorpdfstring{$\ast$}{*}pv\+Parameters)
\item 
void \mbox{\hyperlink{main_8h_a03356c29f7343d5cd605bcd3e80e27e0}{test\+\_\+vl53}} (void \texorpdfstring{$\ast$}{*}pv\+Parameters)
\item 
void \mbox{\hyperlink{main_8h_aac27f033a986ce7ecadc6f9532aa8c3a}{test\+\_\+motor}} (void \texorpdfstring{$\ast$}{*}pv\+Parameters)
\end{DoxyCompactItemize}
\end{Indent}

\doxysubsection{Detailed Description}
\+: Header for \doxylink{main_8c}{main.\+c} file. This file contains the common defines of the application. 

Definition in file \mbox{\hyperlink{main_8h_source}{main.\+h}}.

\doxysubsection{Macro Definition Documentation}
\Hypertarget{main_8h_a4926b92dcb220e465850d9616c27e171}\label{main_8h_a4926b92dcb220e465850d9616c27e171} 
\index{main.h@{main.h}!B1\_GPIO\_Port@{B1\_GPIO\_Port}}
\index{B1\_GPIO\_Port@{B1\_GPIO\_Port}!main.h@{main.h}}
\doxysubsubsection{\texorpdfstring{B1\_GPIO\_Port}{B1\_GPIO\_Port}}
{\footnotesize\ttfamily \#define B1\+\_\+\+GPIO\+\_\+\+Port~GPIOC}

Definition at line \mbox{\hyperlink{main_8h_source_l00220}{220}} of file \mbox{\hyperlink{main_8h_source}{main.\+h}}.

\Hypertarget{main_8h_a31ac298fbbc8a1d6de1dc4577a108232}\label{main_8h_a31ac298fbbc8a1d6de1dc4577a108232} 
\index{main.h@{main.h}!B1\_Pin@{B1\_Pin}}
\index{B1\_Pin@{B1\_Pin}!main.h@{main.h}}
\doxysubsubsection{\texorpdfstring{B1\_Pin}{B1\_Pin}}
{\footnotesize\ttfamily \#define B1\+\_\+\+Pin~GPIO\+\_\+\+PIN\+\_\+13}

Definition at line \mbox{\hyperlink{main_8h_source_l00219}{219}} of file \mbox{\hyperlink{main_8h_source}{main.\+h}}.

\Hypertarget{main_8h_a5aff6ddf7fe557e53b048115ad322aa0}\label{main_8h_a5aff6ddf7fe557e53b048115ad322aa0} 
\index{main.h@{main.h}!LD2\_GPIO\_Port@{LD2\_GPIO\_Port}}
\index{LD2\_GPIO\_Port@{LD2\_GPIO\_Port}!main.h@{main.h}}
\doxysubsubsection{\texorpdfstring{LD2\_GPIO\_Port}{LD2\_GPIO\_Port}}
{\footnotesize\ttfamily \#define LD2\+\_\+\+GPIO\+\_\+\+Port~GPIOA}

Definition at line \mbox{\hyperlink{main_8h_source_l00226}{226}} of file \mbox{\hyperlink{main_8h_source}{main.\+h}}.

\Hypertarget{main_8h_af17a94dd613cff35c699b06c7c6a2820}\label{main_8h_af17a94dd613cff35c699b06c7c6a2820} 
\index{main.h@{main.h}!LD2\_Pin@{LD2\_Pin}}
\index{LD2\_Pin@{LD2\_Pin}!main.h@{main.h}}
\doxysubsubsection{\texorpdfstring{LD2\_Pin}{LD2\_Pin}}
{\footnotesize\ttfamily \#define LD2\+\_\+\+Pin~GPIO\+\_\+\+PIN\+\_\+5}

Definition at line \mbox{\hyperlink{main_8h_source_l00225}{225}} of file \mbox{\hyperlink{main_8h_source}{main.\+h}}.

\Hypertarget{main_8h_a1540b1bd5614d42feb933c5b943263c0}\label{main_8h_a1540b1bd5614d42feb933c5b943263c0} 
\index{main.h@{main.h}!SWO\_GPIO\_Port@{SWO\_GPIO\_Port}}
\index{SWO\_GPIO\_Port@{SWO\_GPIO\_Port}!main.h@{main.h}}
\doxysubsubsection{\texorpdfstring{SWO\_GPIO\_Port}{SWO\_GPIO\_Port}}
{\footnotesize\ttfamily \#define SWO\+\_\+\+GPIO\+\_\+\+Port~GPIOB}

Definition at line \mbox{\hyperlink{main_8h_source_l00232}{232}} of file \mbox{\hyperlink{main_8h_source}{main.\+h}}.

\Hypertarget{main_8h_a92aba89301afeefb00b6dfbc6e874027}\label{main_8h_a92aba89301afeefb00b6dfbc6e874027} 
\index{main.h@{main.h}!SWO\_Pin@{SWO\_Pin}}
\index{SWO\_Pin@{SWO\_Pin}!main.h@{main.h}}
\doxysubsubsection{\texorpdfstring{SWO\_Pin}{SWO\_Pin}}
{\footnotesize\ttfamily \#define SWO\+\_\+\+Pin~GPIO\+\_\+\+PIN\+\_\+3}

Definition at line \mbox{\hyperlink{main_8h_source_l00231}{231}} of file \mbox{\hyperlink{main_8h_source}{main.\+h}}.

\Hypertarget{main_8h_a1541f23b870848a43f0274857badd175}\label{main_8h_a1541f23b870848a43f0274857badd175} 
\index{main.h@{main.h}!TCK\_GPIO\_Port@{TCK\_GPIO\_Port}}
\index{TCK\_GPIO\_Port@{TCK\_GPIO\_Port}!main.h@{main.h}}
\doxysubsubsection{\texorpdfstring{TCK\_GPIO\_Port}{TCK\_GPIO\_Port}}
{\footnotesize\ttfamily \#define TCK\+\_\+\+GPIO\+\_\+\+Port~GPIOA}

Definition at line \mbox{\hyperlink{main_8h_source_l00230}{230}} of file \mbox{\hyperlink{main_8h_source}{main.\+h}}.

\Hypertarget{main_8h_a9e21d9bed16b0275ff16a864ffb2ab6e}\label{main_8h_a9e21d9bed16b0275ff16a864ffb2ab6e} 
\index{main.h@{main.h}!TCK\_Pin@{TCK\_Pin}}
\index{TCK\_Pin@{TCK\_Pin}!main.h@{main.h}}
\doxysubsubsection{\texorpdfstring{TCK\_Pin}{TCK\_Pin}}
{\footnotesize\ttfamily \#define TCK\+\_\+\+Pin~GPIO\+\_\+\+PIN\+\_\+14}

Definition at line \mbox{\hyperlink{main_8h_source_l00229}{229}} of file \mbox{\hyperlink{main_8h_source}{main.\+h}}.

\Hypertarget{main_8h_affce477a22cc940d3962932cb33ec422}\label{main_8h_affce477a22cc940d3962932cb33ec422} 
\index{main.h@{main.h}!TMS\_GPIO\_Port@{TMS\_GPIO\_Port}}
\index{TMS\_GPIO\_Port@{TMS\_GPIO\_Port}!main.h@{main.h}}
\doxysubsubsection{\texorpdfstring{TMS\_GPIO\_Port}{TMS\_GPIO\_Port}}
{\footnotesize\ttfamily \#define TMS\+\_\+\+GPIO\+\_\+\+Port~GPIOA}

Definition at line \mbox{\hyperlink{main_8h_source_l00228}{228}} of file \mbox{\hyperlink{main_8h_source}{main.\+h}}.

\Hypertarget{main_8h_af2c8a7a0746106e52f6f415b8921c21b}\label{main_8h_af2c8a7a0746106e52f6f415b8921c21b} 
\index{main.h@{main.h}!TMS\_Pin@{TMS\_Pin}}
\index{TMS\_Pin@{TMS\_Pin}!main.h@{main.h}}
\doxysubsubsection{\texorpdfstring{TMS\_Pin}{TMS\_Pin}}
{\footnotesize\ttfamily \#define TMS\+\_\+\+Pin~GPIO\+\_\+\+PIN\+\_\+13}

Definition at line \mbox{\hyperlink{main_8h_source_l00227}{227}} of file \mbox{\hyperlink{main_8h_source}{main.\+h}}.

\Hypertarget{main_8h_aae451289f2eda1c04e3bf6d6120b6c0b}\label{main_8h_aae451289f2eda1c04e3bf6d6120b6c0b} 
\index{main.h@{main.h}!USART\_RX\_GPIO\_Port@{USART\_RX\_GPIO\_Port}}
\index{USART\_RX\_GPIO\_Port@{USART\_RX\_GPIO\_Port}!main.h@{main.h}}
\doxysubsubsection{\texorpdfstring{USART\_RX\_GPIO\_Port}{USART\_RX\_GPIO\_Port}}
{\footnotesize\ttfamily \#define USART\+\_\+\+RX\+\_\+\+GPIO\+\_\+\+Port~GPIOA}

Definition at line \mbox{\hyperlink{main_8h_source_l00224}{224}} of file \mbox{\hyperlink{main_8h_source}{main.\+h}}.

\Hypertarget{main_8h_ac93b92f1334823df872908c845c71afc}\label{main_8h_ac93b92f1334823df872908c845c71afc} 
\index{main.h@{main.h}!USART\_RX\_Pin@{USART\_RX\_Pin}}
\index{USART\_RX\_Pin@{USART\_RX\_Pin}!main.h@{main.h}}
\doxysubsubsection{\texorpdfstring{USART\_RX\_Pin}{USART\_RX\_Pin}}
{\footnotesize\ttfamily \#define USART\+\_\+\+RX\+\_\+\+Pin~GPIO\+\_\+\+PIN\+\_\+3}

Definition at line \mbox{\hyperlink{main_8h_source_l00223}{223}} of file \mbox{\hyperlink{main_8h_source}{main.\+h}}.

\Hypertarget{main_8h_a79a3e098f5d738c55a12e4272b7b2f84}\label{main_8h_a79a3e098f5d738c55a12e4272b7b2f84} 
\index{main.h@{main.h}!USART\_TX\_GPIO\_Port@{USART\_TX\_GPIO\_Port}}
\index{USART\_TX\_GPIO\_Port@{USART\_TX\_GPIO\_Port}!main.h@{main.h}}
\doxysubsubsection{\texorpdfstring{USART\_TX\_GPIO\_Port}{USART\_TX\_GPIO\_Port}}
{\footnotesize\ttfamily \#define USART\+\_\+\+TX\+\_\+\+GPIO\+\_\+\+Port~GPIOA}

Definition at line \mbox{\hyperlink{main_8h_source_l00222}{222}} of file \mbox{\hyperlink{main_8h_source}{main.\+h}}.

\Hypertarget{main_8h_a5644600bf1ed996688dd87dc3f88526c}\label{main_8h_a5644600bf1ed996688dd87dc3f88526c} 
\index{main.h@{main.h}!USART\_TX\_Pin@{USART\_TX\_Pin}}
\index{USART\_TX\_Pin@{USART\_TX\_Pin}!main.h@{main.h}}
\doxysubsubsection{\texorpdfstring{USART\_TX\_Pin}{USART\_TX\_Pin}}
{\footnotesize\ttfamily \#define USART\+\_\+\+TX\+\_\+\+Pin~GPIO\+\_\+\+PIN\+\_\+2}

Definition at line \mbox{\hyperlink{main_8h_source_l00221}{221}} of file \mbox{\hyperlink{main_8h_source}{main.\+h}}.

\doxysubsection{Function Documentation}
\Hypertarget{main_8h_a3f82047e1c93bff73e4db97a19f6ad2e}\label{main_8h_a3f82047e1c93bff73e4db97a19f6ad2e} 
\index{main.h@{main.h}!CHECKMRRET@{CHECKMRRET}}
\index{CHECKMRRET@{CHECKMRRET}!main.h@{main.h}}
\doxysubsubsection{\texorpdfstring{CHECKMRRET()}{CHECKMRRET()}}
{\footnotesize\ttfamily void CHECKMRRET (\begin{DoxyParamCaption}\item[{rcl\+\_\+ret\+\_\+t}]{ret,  }\item[{char \texorpdfstring{$\ast$}{*}}]{msg }\end{DoxyParamCaption})}

check if micro\+Ros function success else print msg in console 
\begin{DoxyParams}{Parameters}
{\em ret} & return value of micro\+Ros function \\
\hline
{\em msg} & message to print if fail \\
\hline
\end{DoxyParams}

Definition at line \mbox{\hyperlink{main_8c_source_l00154}{154}} of file \mbox{\hyperlink{main_8c_source}{main.\+c}}.

\Hypertarget{main_8h_a1730ffe1e560465665eb47d9264826f9}\label{main_8h_a1730ffe1e560465665eb47d9264826f9} 
\index{main.h@{main.h}!Error\_Handler@{Error\_Handler}}
\index{Error\_Handler@{Error\_Handler}!main.h@{main.h}}
\doxysubsubsection{\texorpdfstring{Error\_Handler()}{Error\_Handler()}}
{\footnotesize\ttfamily void Error\+\_\+\+Handler (\begin{DoxyParamCaption}\item[{void}]{ }\end{DoxyParamCaption})}

Definition at line \mbox{\hyperlink{main_8c_source_l00914}{914}} of file \mbox{\hyperlink{main_8c_source}{main.\+c}}.

\Hypertarget{main_8h_a840291bc02cba5474a4cb46a9b9566fe}\label{main_8h_a840291bc02cba5474a4cb46a9b9566fe} 
\index{main.h@{main.h}!main@{main}}
\index{main@{main}!main.h@{main.h}}
\doxysubsubsection{\texorpdfstring{main()}{main()}}
{\footnotesize\ttfamily int main (\begin{DoxyParamCaption}\item[{void}]{ }\end{DoxyParamCaption})}
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

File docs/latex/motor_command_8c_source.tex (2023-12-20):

\doxysection{motor\+Command.\+c}
\hypertarget{motor_command_8c_source}{}\label{motor_command_8c_source}\index{C:/Users/Administrator/Documents/GitHub/ENIB\_Robot\_Mobile\_Ros2/finalCode/WORKSPACE\_F411\_uROS/base\_robot/Core/Src/motorCommand.c@{C:/Users/Administrator/Documents/GitHub/ENIB\_Robot\_Mobile\_Ros2/finalCode/WORKSPACE\_F411\_uROS/base\_robot/Core/Src/motorCommand.c}}

\begin{DoxyCode}{0}
\DoxyCodeLine{\Hypertarget{motor_command_8c_source_l00001}00001\ \textcolor{comment}{/*}}
\DoxyCodeLine{\Hypertarget{motor_command_8c_source_l00002}00002\ \textcolor{comment}{\ *\ MotorCommand.c}}
\DoxyCodeLine{\Hypertarget{motor_command_8c_source_l00003}00003\ \textcolor{comment}{\ */}}
\DoxyCodeLine{\Hypertarget{motor_command_8c_source_l00004}00004\ }
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

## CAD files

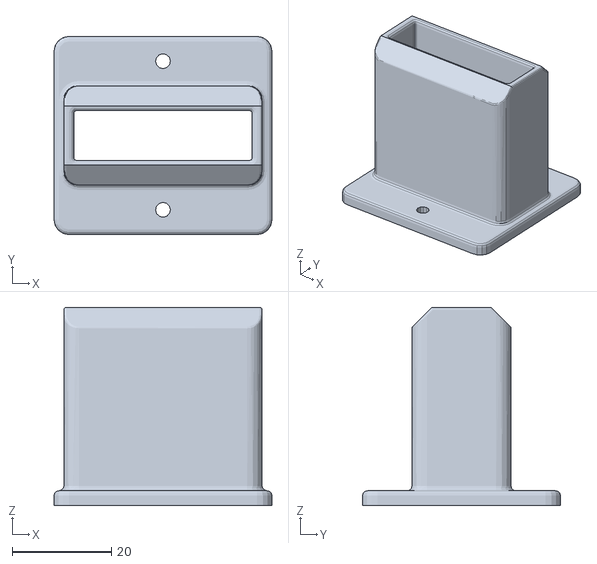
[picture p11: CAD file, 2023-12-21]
conception/3D_models/other/3dprint/support_webcam.stl
44.0 x 40.0 x 40.0

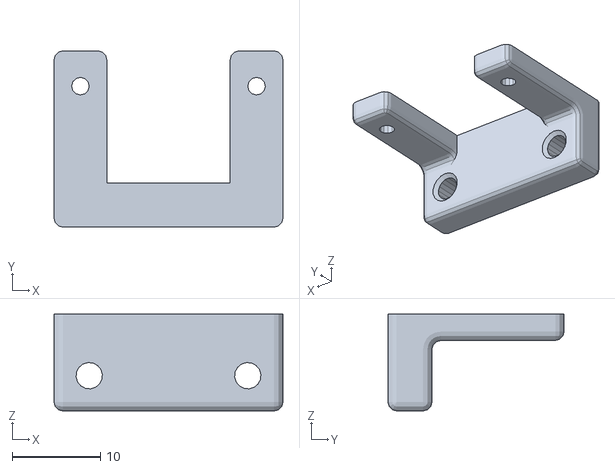
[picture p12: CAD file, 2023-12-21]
conception/3D_models/other/3dprint/SupportVL530X.stl
26.0 x 20.0 x 11.0

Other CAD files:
conception/3D_models/Humble.CATProduct
conception/3D_models/MainBoard.CATProduct
conception/3D_models/piece/24V-5V/convertisseur.CATPart
conception/3D_models/piece/Hacheur/Droite/CAPC-0805-T0.CATPart
conception/3D_models/piece/Hacheur/Droite/DRV8871_R-PDSO-G8.CATPart
conception/3D_models/piece/Hacheur/Droite/DRV8871_module_PCB.CATPart
conception/3D_models/piece/Hacheur/Droite/RESC-0805.CATPart
conception/3D_models/piece/Hacheur/Droite/SMD AEC (Base).CATPart
conception/3D_models/piece/Hacheur/Droite/SMD AEC (Cylinder).CATPart
conception/3D_models/piece/Hacheur/Droite/SMD AEC (Pin).CATPart
conception/3D_models/piece/Hacheur/Droite/hacheurDroite.CATProduct
conception/3D_models/piece/Hacheur/Gauche/CAPC-0805-T0.CATPart
conception/3D_models/piece/Hacheur/Gauche/DRV8871_R-PDSO-G8.CATPart
conception/3D_models/piece/Hacheur/Gauche/DRV8871_module_PCB.CATPart
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

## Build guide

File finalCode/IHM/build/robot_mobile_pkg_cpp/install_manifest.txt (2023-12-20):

/home/rospc/robot_mobile_ihm/install/robot_mobile_pkg_cpp/lib/robot_mobile_pkg_cpp/my_node_ihm
/home/rospc/robot_mobile_ihm/install/robot_mobile_pkg_cpp/share/ament_index/resource_index/package_run_dependencies/robot_mobile_pkg_cpp
/home/rospc/robot_mobile_ihm/install/robot_mobile_pkg_cpp/share/ament_index/resource_index/parent_prefix_path/robot_mobile_pkg_cpp
/home/rospc/robot_mobile_ihm/install/robot_mobile_pkg_cpp/share/robot_mobile_pkg_cpp/environment/ament_prefix_path.sh
/home/rospc/robot_mobile_ihm/install/robot_mobile_pkg_cpp/share/robot_mobile_pkg_cpp/environment/ament_prefix_path.dsv
/home/rospc/robot_mobile_ihm/install/robot_mobile_pkg_cpp/share/robot_mobile_pkg_cpp/environment/path.sh
/home/rospc/robot_mobile_ihm/install/robot_mobile_pkg_cpp/share/robot_mobile_pkg_cpp/environment/path.dsv
/home/rospc/robot_mobile_ihm/install/robot_mobile_pkg_cpp/share/robot_mobile_pkg_cpp/local_setup.bash
/home/rospc/robot_mobile_ihm/install/robot_mobile_pkg_cpp/share/robot_mobile_pkg_cpp/local_setup.sh
/home/rospc/robot_mobile_ihm/install/robot_mobile_pkg_cpp/share/robot_mobile_pkg_cpp/local_setup.zsh
/home/rospc/robot_mobile_ihm/install/robot_mobile_pkg_cpp/share/robot_mobile_pkg_cpp/local_setup.dsv
/home/rospc/robot_mobile_ihm/install/robot_mobile_pkg_cpp/share/robot_mobile_pkg_cpp/package.dsv
/home/rospc/robot_mobile_ihm/install/robot_mobile_pkg_cpp/share/ament_index/resource_index/packages/robot_mobile_pkg_cpp
/home/rospc/robot_mobile_ihm/install/robot_mobile_pkg_cpp/share/robot_mobile_pkg_cpp/cmake/robot_mobile_pkg_cppConfig.cmake
/home/rospc/robot_mobile_ihm/install/robot_mobile_pkg_cpp/share/robot_mobile_pkg_cpp/cmake/robot_mobile_pkg_cppConfig-version.cmake
/home/rospc/robot_mobile_ihm/install/robot_mobile_pkg_cpp/share/robot_mobile_pkg_cpp/package.xml

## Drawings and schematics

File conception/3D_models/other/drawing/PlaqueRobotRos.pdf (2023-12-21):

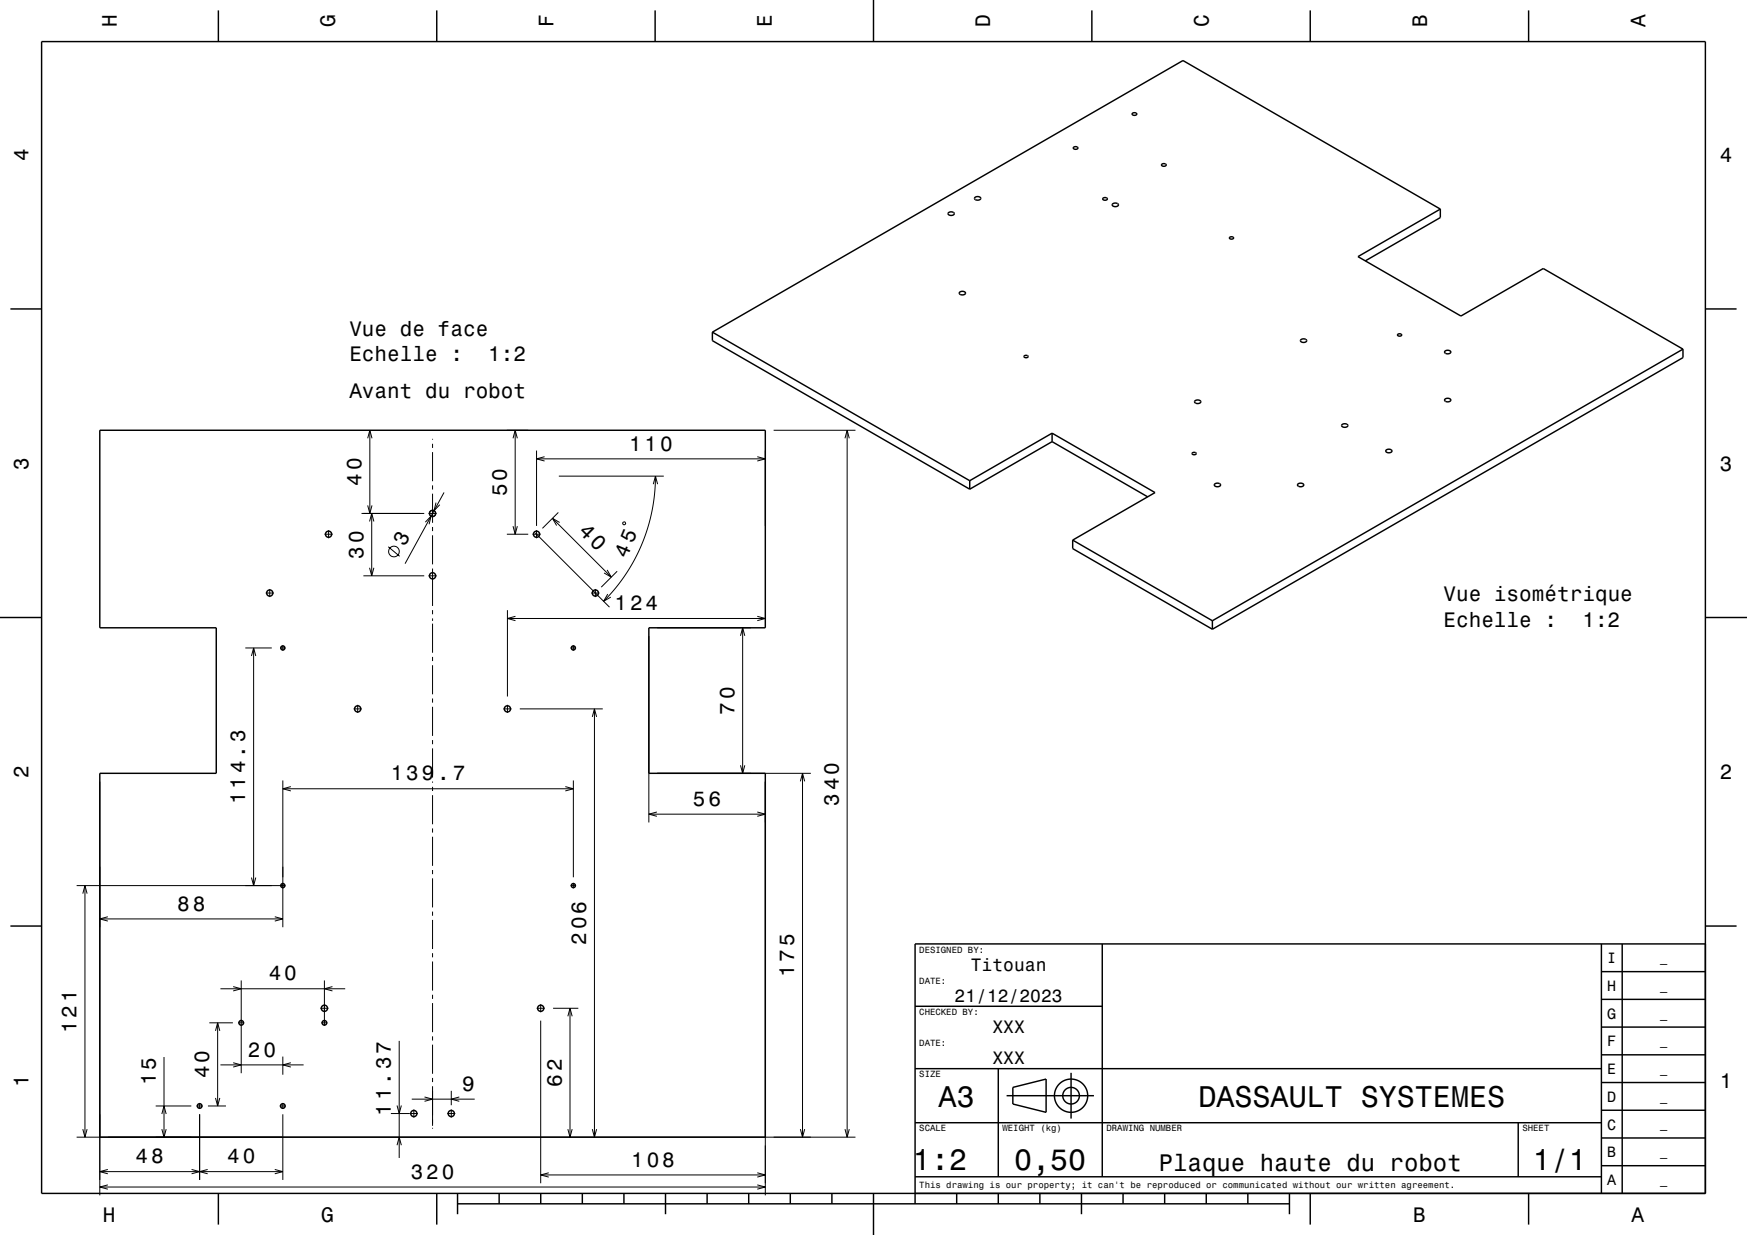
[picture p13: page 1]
CHECKED BY:; Vue isométrique Echelle : 1:2

Vue de face
Echelle : 1:2
Avant du robot

DESIGNED BY: Titouan DATE: 21/12/2023 | I | _

SIZE A3 | | | | DASSAULT SYSTEMES

SCALE 1:2 | WEIGHT (kg) 0,50 | DRAWING NUMBER Plaque haute du robot | SHEET 1/1

This drawing is our property; it can't be reproduced or communicated without our written agreement.

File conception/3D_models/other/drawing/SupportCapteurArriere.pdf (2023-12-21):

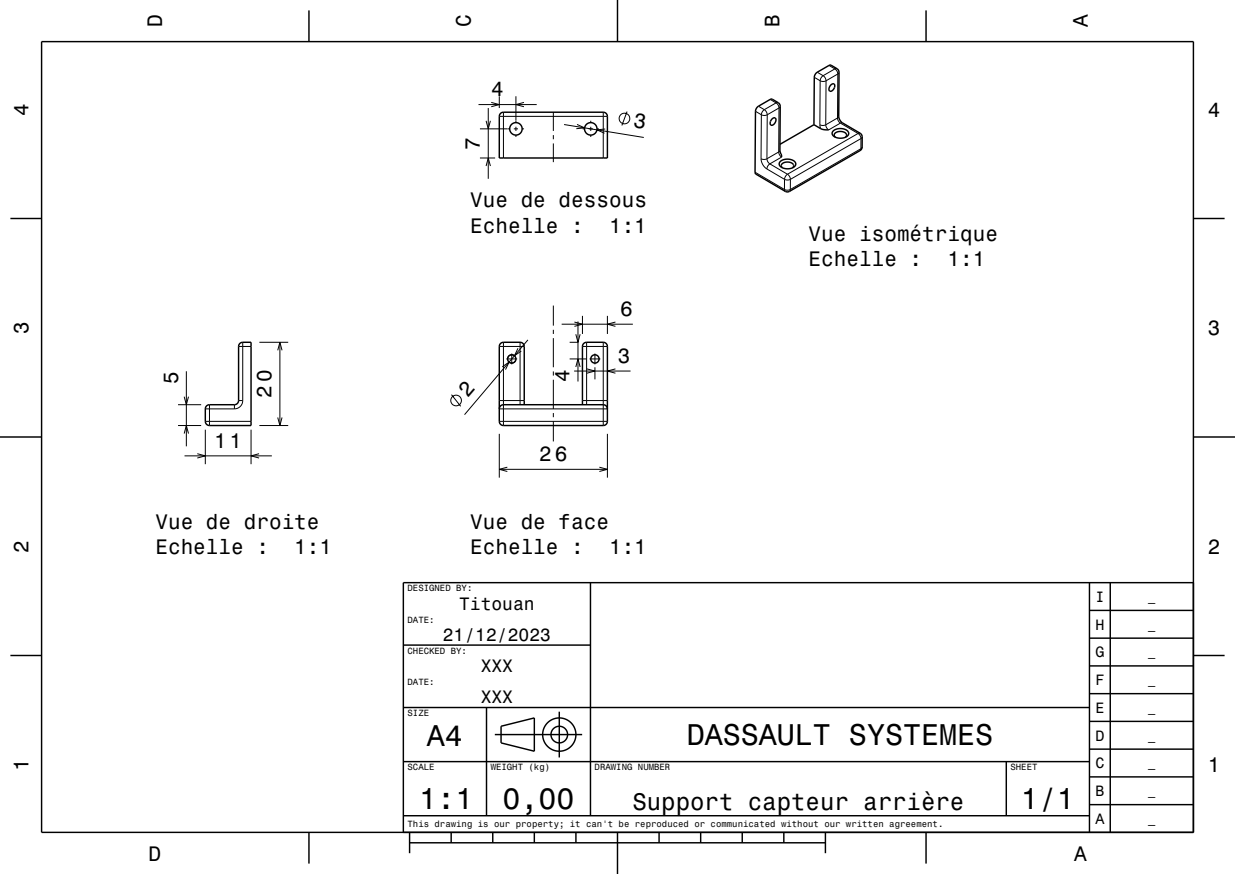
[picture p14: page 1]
CHECKED BY:; Echelle : 1:1 20; Vue isométrique Echelle : 1:1

Vue de dessous
Echelle : 1:1

Vue de droite

Vue de face

DESIGNED BY: Titouan DATE: 21/12/2023 | I | _

SIZE A4 | | | | DASSAULT SYSTEMES

SCALE 1:1 | WEIGHT (kg) 0,00 | DRAWING NUMBER Support capteur arrière | SHEET 1/1

This drawing is our property; it can't be reproduced or communicated without our written agreement.

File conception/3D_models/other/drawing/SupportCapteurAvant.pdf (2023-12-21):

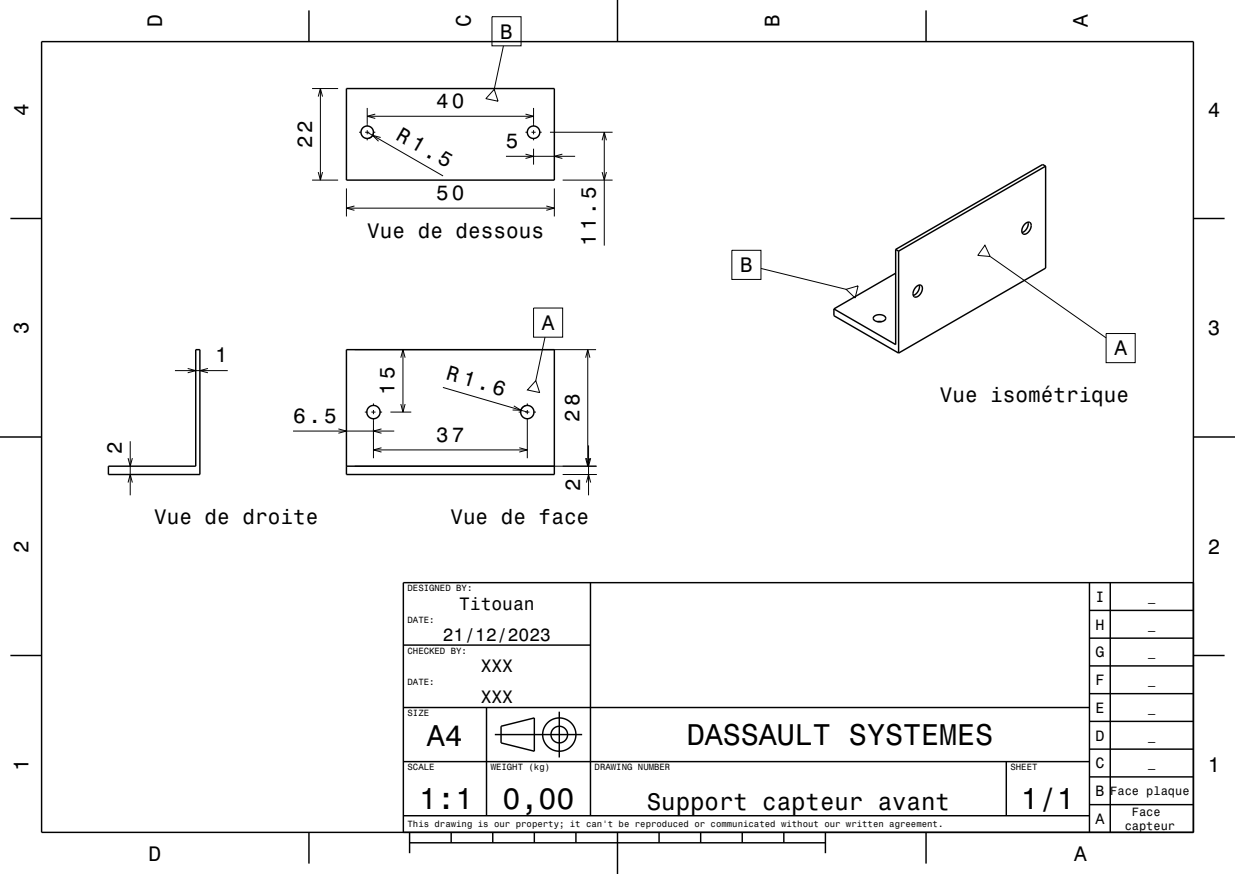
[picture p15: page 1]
CHECKED BY:; Vue isométrique

Vue de dessous

Vue de droite

Vue de face

DESIGNED BY: Titouan DATE: 21/12/2023 | I | _

B | Face plaque
A | Face capteur

SIZE A4 | | | | DASSAULT SYSTEMES

SCALE 1:1 | WEIGHT (kg) 0,00 | DRAWING NUMBER Support capteur avant | SHEET 1/1

This drawing is our property; it can't be reproduced or communicated without our written agreement.

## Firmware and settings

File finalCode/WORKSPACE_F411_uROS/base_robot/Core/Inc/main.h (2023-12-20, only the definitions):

#define B1_Pin GPIO_PIN_13
#define B1_GPIO_Port GPIOC
#define USART_TX_Pin GPIO_PIN_2
#define USART_TX_GPIO_Port GPIOA
#define USART_RX_Pin GPIO_PIN_3
#define USART_RX_GPIO_Port GPIOA
#define LD2_Pin GPIO_PIN_5
#define LD2_GPIO_Port GPIOA
#define TMS_Pin GPIO_PIN_13
#define TMS_GPIO_Port GPIOA
#define TCK_Pin GPIO_PIN_14
#define TCK_GPIO_Port GPIOA
#define SWO_Pin GPIO_PIN_3
#define SWO_GPIO_Port GPIOB

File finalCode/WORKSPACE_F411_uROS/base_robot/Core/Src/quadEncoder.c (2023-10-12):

/*
 * QuadEncoder.c
 */
#include "quadEncoder.h"

#define SAMPLING_PERIOD_ms		5
#define TE_ms	SAMPLING_PERIOD_ms
#define USE_QUAD_ENCODER_1250_CPR 1

#if USE_QUAD_ENCODER_1250_CPR
#define COUNT_PER_ROUND 1250
#define MAX_CNT_PER_REV (COUNT_PER_ROUND * 4 - 1)
#define MAX_COUNT (int)(((unsigned long)MAX_CNT_PER_REV*6555)/1000)
#define HALF_MAX_COUNT (MAX_COUNT>>1)
#define COEFF	6555
#endif

#if USE_QUAD_ENCODER_1000_CPR
#define COUNT_PER_ROUND 1000
#define MAX_CNT_PER_REV (COUNT_PER_ROUND * 4 - 1)
#define MAX_COUNT (int)(((unsigned long)MAX_CNT_PER_REV*8192)/1000)
#define HALF_MAX_COUNT (MAX_COUNT>>1)
#define COEFF 8192
#endif

#if USE_QUAD_ENCODER_500_CPR
#define COUNT_PER_ROUND 500
#define MAX_CNT_PER_REV (COUNT_PER_ROUND * 4 - 1)
#define MAX_COUNT (int)(((unsigned long)MAX_CNT_PER_REV*16392)/1000)
#define HALF_MAX_COUNT (MAX_COUNT>>1)
#define COEFF 16392
#endif

#if USE_QUAD_ENCODER_250_CPR
#define COUNT_PER_ROUND 250
#define MAX_CNT_PER_REV (COUNT_PER_ROUND * 4 - 1)
#define MAX_COUNT (int)(((unsigned long)MAX_CNT_PER_REV*32768)/1000)
#define HALF_MAX_COUNT (MAX_COUNT>>1)
#define COEFF 32768
#endif



TIM_HandleTypeDef    TimEncoderHandleLeft;
TIM_HandleTypeDef    TimEncoderHandleRight;

/*******************************************************************************
 * TIMER 1, CHANNEL 1 et 2  --> RIGHT
 * TIMER 2, CHANNEL 1 et 2	--> LEFT
****************************************************************************** */
int indexL=0;
static int indexR=0;

//================================================================
//		TIMER INIT
//================================================================

void quadEncoder_Init(void)
{
	TIM_Encoder_InitTypeDef sConfig;
	//--------------------------------------------------
	// TIMER 1
	//--------------------------------------------------
	TimEncoderHandleLeft.Instance = TIM1;
	TimEncoderHandleLeft.Init.Prescaler = 0;
	TimEncoderHandleLeft.Init.CounterMode = TIM_COUNTERMODE_UP;
	TimEncoderHandleLeft.Init.Period = COUNT_PER_ROUND*4;
	TimEncoderHandleLeft.Init.ClockDivision = TIM_CLOCKDIVISION_DIV1;

	sConfig.EncoderMode = TIM_ENCODERMODE_TI12;
	sConfig.IC1Polarity = TIM_INPUTCHANNELPOLARITY_RISING;
	sConfig.IC1Selection = TIM_ICSELECTION_DIRECTTI;
	sConfig.IC1Prescaler = TIM_ICPSC_DIV4;
	sConfig.IC1Filter = 0x0F;
	sConfig.IC2Polarity = TIM_INPUTCHANNELPOLARITY_RISING;
	sConfig.IC2Selection = TIM_ICSELECTION_DIRECTTI;//TIM_ICSELECTION_DIRECTTI; //TIM_TI1SELECTION_XORCOMBINATION
	sConfig.IC2Prescaler = TIM_ICPSC_DIV4;
	sConfig.IC2Filter = 0x0F;

	HAL_TIM_Encoder_Init(&TimEncoderHandleLeft, &sConfig);

	__HAL_TIM_SetCounter(&TimEncoderHandleLeft, 0);

	HAL_TIM_Encoder_Start(&TimEncoderHandleLeft,TIM_CHANNEL_1);
	HAL_TIM_Encoder_Start(&TimEncoderHandleLeft,TIM_CHANNEL_2);

	//--------------------------------------------------
	// TIMER 2
	//--------------------------------------------------
	TimEncoderHandleRight.Instance = TIM2;
	TimEncoderHandleRight.Init.Prescaler = 0;
	TimEncoderHandleRight.Init.CounterMode = TIM_COUNTERMODE_UP;
	TimEncoderHandleRight.Init.Period = COUNT_PER_ROUND*4;
	TimEncoderHandleRight.Init.ClockDivision = TIM_CLOCKDIVISION_DIV1;

	sConfig.EncoderMode = TIM_ENCODERMODE_TI12;
	sConfig.IC1Polarity = TIM_INPUTCHANNELPOLARITY_RISING;
	sConfig.IC1Selection = TIM_ICSELECTION_DIRECTTI;
	sConfig.IC1Prescaler = TIM_ICPSC_DIV4;
	sConfig.IC1Filter = 0x0F;
	sConfig.IC2Polarity = TIM_INPUTCHANNELPOLARITY_RISING;
	sConfig.IC2Selection = TIM_ICSELECTION_DIRECTTI;//TIM_ICSELECTION_DIRECTTI; //TIM_TI1SELECTION_XORCOMBINATION
	sConfig.IC2Prescaler = TIM_ICPSC_DIV4;
	sConfig.IC2Filter = 0x0F;

	HAL_TIM_Encoder_Init(&TimEncoderHandleRight, &sConfig);

	__HAL_TIM_SetCounter(&TimEncoderHandleRight, 0);

	HAL_TIM_Encoder_Start(&TimEncoderHandleRight,TIM_CHANNEL_1);
	HAL_TIM_Encoder_Start(&TimEncoderHandleRight,TIM_CHANNEL_2);
}

//================================================================
//		POSITION LEFT CALC
//================================================================

void quadEncoder_PosCalcL(int* AngPos)
{

int POSCNTcopy = 0;
POSCNTcopy = (int)TIM1->CNT;
AngPos[1] = AngPos[0];
AngPos[0] = (unsigned int)(((unsigned long)POSCNTcopy * COEFF)/1000); // 0 <= POSCNT <= 4999 to 0 <= AngPos <= 32767
}

//================================================================
//		POSITION RIGHT CALC
//================================================================

void quadEncoder_PosCalcR(int* AngPos)
{

int POSCNTcopy = 0;
POSCNTcopy = (int)TIM2->CNT;
AngPos[1] = AngPos[0];
AngPos[0] = (unsigned int)(((unsigned long)POSCNTcopy * COEFF)/1000); // 0 <= POSCNT <= 4999 to 0 <= AngPos <= 32767
}

//================================================================
//		POSITION LEFT 16 BITS
//================================================================

int16_t quadEncoder_GetPos16L(void)
{
	uint16_t PosL = 0;
	PosL=TIM1->CNT;
	return (int16_t)PosL;

	}

//================================================================
//		POSITION RIGHT 16 BITS
//================================================================

int16_t quadEncoder_GetPos16R(void)
{
	uint16_t PosR = 0;
	PosR=TIM2->CNT;
    return (int16_t)PosR;
}
//================================================================
//		POSITION LEFT 32 BITS	(pos 16 bits + nombre de tours)
//================================================================

int32_t quadEncoder_GetPos32L(void)
{
	int32_t  PosL = 0;
	PosL=indexL*4*COUNT_PER_ROUND + (int32_t) quadEncoder_GetPos16L();
	return PosL;
}

//================================================================
//		POSITION RIGHT 32 BITS	(pos 16 bits + nombre de tours)
//================================================================

int32_t quadEncoder_GetPos32R(void)
{
	int32_t PosR = 0;
	PosR=indexR*4*COUNT_PER_ROUND + (int32_t) quadEncoder_GetPos16R();
	return PosR;
}

//================================================================
//		SPEED LEFT
//--> must be called every Te
//================================================================

int16_t quadEncoder_GetSpeedL(void)
{
	static int AngPos[2] = {0,0};
	static int16_t SpeedL=0;

	quadEncoder_PosCalcL(AngPos);
	SpeedL = AngPos[0] - AngPos[1];
	if (SpeedL >= 0)
	{
		if (SpeedL >= HALF_MAX_COUNT)
			{
			SpeedL = SpeedL - MAX_COUNT;
			}
	}
	else
	{
		if (SpeedL < -HALF_MAX_COUNT)
			{
			SpeedL = SpeedL + MAX_COUNT;
			}
	}
	
	//***********************************
	// CONVERT RPM
	// 1 tour = 32767
	// Nbre de Tours pendant Te: DELTA_pos/32767
	// Nbre de Tours pendant 1s (Te en ms) : (DELTA_pos/32767)*(1000/Te)
	// Nbre de Tours par minute : : (DELTA_pos/32767)*((60*1000)/Te)

	SpeedL=(SpeedL*60*1000)/(32767*TE_ms);
	return SpeedL;
}

//================================================================
//		SPEED RIGHT
//-->  must be called every Te
//================================================================
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

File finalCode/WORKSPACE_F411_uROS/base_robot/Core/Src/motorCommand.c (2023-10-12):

/*
 * MotorCommand.c
 */

#include "motorCommand.h"

static TIM_HandleTypeDef    TimHandle;
static TIM_OC_InitTypeDef   sConfigOC;

//=================================================================
//			PWM INIT
// TIMER 3 (PWM)  : CH1 et CH2
// ENABLE : Sortie Logique (GPIO) PA7
//=================================================================

void motorCommand_Init(void)
{
	unsigned int uwPrescalerValue = 0;

	/* Compute the prescaler value to have TIM4 counter clock equal to 10MHz */
	  uwPrescalerValue = (unsigned int) ((SystemCoreClock / 10000000) - 1);
	  TimHandle.Instance = TIM3;
	  TimHandle.Init.Period = 200 - 1; // 100MHz/200=50kHz
	  TimHandle.Init.Prescaler = uwPrescalerValue;
	  TimHandle.Init.ClockDivision = 0;
	  TimHandle.Init.CounterMode = TIM_COUNTERMODE_UP;

	  HAL_TIM_Base_Init(&TimHandle);

	  sConfigOC.OCMode = TIM_OCMODE_PWM1;
	  sConfigOC.Pulse = 0x5;// Specifies the pulse value to be loaded into the Capture Compare Register. This parameter can be a number between Min_Data = 0x0000 and Max_Data = 0xFFFF */

	  sConfigOC.OCPolarity = TIM_OCPOLARITY_HIGH;
	  sConfigOC.OCFastMode = TIM_OCFAST_DISABLE;

	 HAL_TIM_PWM_ConfigChannel(&TimHandle, &sConfigOC, TIM_CHANNEL_1);
	 HAL_TIM_PWM_ConfigChannel(&TimHandle, &sConfigOC, TIM_CHANNEL_2);

	 // CHANGEMENT DU RAPPORT CYCLIQUE
	 __HAL_TIM_SetCompare(&TimHandle, TIM_CHANNEL_1, 100);	// 100 : moteurs au repos
	 __HAL_TIM_SetCompare(&TimHandle, TIM_CHANNEL_2, 100);

	  HAL_TIM_PWM_Start(&TimHandle, TIM_CHANNEL_1);	// MOTOR RIGHT
	  HAL_TIM_PWM_Start(&TimHandle, TIM_CHANNEL_2); // MOTOR LEFT

	  // ENABLE MOTEUR (SI INVERSEUR)
	  //HAL_GPIO_WritePin(GPIOA, GPIO_PIN_7, 0);
	  HAL_GPIO_WritePin(GPIOB, GPIO_PIN_3, 0);
}

//=================================================================
//			SET DUTY CYCLE LEFT
//=================================================================
void motorLeft_SetDuty(int duty)
{
	__HAL_TIM_SetCompare(&TimHandle, TIM_CHANNEL_1, duty);
}
//=================================================================
//			SET DUTY CYCLE RIGHT
//=================================================================
void motorRight_SetDuty(int duty)
{
	__HAL_TIM_SetCompare(&TimHandle, TIM_CHANNEL_2, duty);
}
//=================================================================

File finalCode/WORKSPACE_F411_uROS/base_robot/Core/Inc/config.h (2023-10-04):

/*
 * config.h
 */

#ifndef INC_CONFIG_H_
#define INC_CONFIG_H_

//========================================================
// USART : CHOIX DE LA LIAISON SERIE
// USART2 : USART_STLINK (cable)
// USART6 : USART_ZIGBEE (sans fil)
//========================================================
#define	USE_USART_STLINK 1			// A Commenter pour utiliser stlink dans term_printf !! faire un clean
//#define	USE_USART_ZIGBEE 1

#define NB_CAR_TO_RECEIVE		1		// nombre de caractères à recevoir pour déclencher une interruption

#define USART2_BAUDRATE			115200
#define USART6_BAUDRATE			9600
//========================================================
//					LIAISON I2C
//========================================================
#define I2C1_CLOCKSPEED			100000
#define I2C2_CLOCKSPEED			100000

// CAPTEUR I2C DISTANCE ULTRASON SRF02
#define	CAPT_US_LEFT_ADDRESS	0xE0
#define	CAPT_US_RIGHT_ADDRESS	0xE2

// IMU MPU9250
#define    MPU9250_ADDRESS      0x68
#define    AK8963_ADDRESS       0x0C

// ECRAN LCD
#define SCREEN_LCD_ADDRESS		(0x30<<1)

// SAMPLING PERIOD in ms
#define SAMPLING_PERIOD_ms		5

#endif /* INC_CONFIG_H_ */

/*^^^^^^^^^^^^^^^^^^^^^^^^^^^^^^^^^^^^^^^^^^^^^^^^^^^^^^^^^^^^^^^^^^^^^*/

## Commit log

2023-10-04 add STM32 workspace
2023-10-12 add schematics
2023-11-09 add 3D part
    [CapteurVL53.CATPart, RobotROSPlaque.CATPart]
2023-11-10 Add 3D models
    [CapteurVL53.CATPart, CapteurVL53.stl, LCD.CATPart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]
2023-11-25 add 3D model
    [WebCamHolder.stl]
2023-12-12 update 3d model
    [CapteurVL53_2.CATPart, Logitech c270.CATPart, Logitech c270b.CATPart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]
2023-12-18 Add camera program
2023-12-18 modify files structures
    [0207_10.CATPart, 02P.CATPart, 05P.CATPart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]
2023-12-21 add drawing + stl
    [Humble.CATProduct, Logitech c270.CATPart, Logitech c270b.CATPart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]
2023-12-21 update assembly
2023-12-24 update 3d modrl
    [RoueArriere.CATPart]
